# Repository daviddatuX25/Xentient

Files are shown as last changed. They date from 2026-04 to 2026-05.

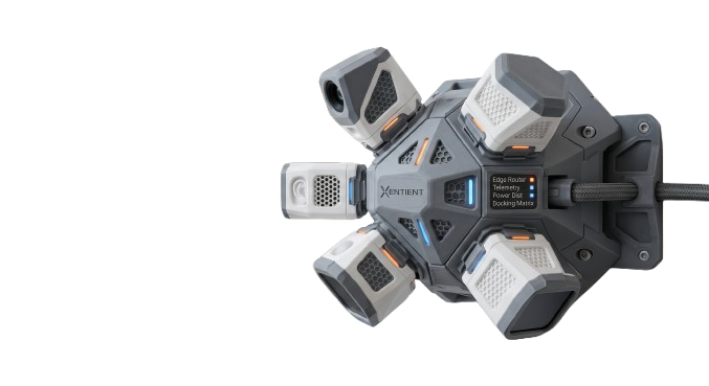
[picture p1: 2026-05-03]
Xentient-vision-product-bgremoved.png

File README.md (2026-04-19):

# Xentient

The IoT terminal that gives any AI a physical presence in any room.

Voice. Sensors. Display. Any AI brain can plug in.

---

## What It Does

Xentient is the bridge between physical rooms and AI brains. The core is a thin terminal OS — voice pipeline, MQTT bridge, LCD faces, mode management. That is what Xentient uniquely owns. Intelligence plugs in via Hermes, Mem0, OpenClaw, or a basic LLM. The same hardware can be a simple room assistant in one space and a full dev workstation in another.

---

## Demo Status

V1 prototype demo Apr 24, 2026. Voice pipeline + MQTT bridge + LCD + basic memory.

---

## Quick Start

- Full architecture and integration tiers: [docs/VISION.md](docs/VISION.md)
- Locked hardware decisions (B1-B7): [docs/HARDWARE.md](docs/HARDWARE.md)
- Explicit scope boundaries: [docs/NON_GOALS.md](docs/NON_GOALS.md)

---

## Architecture

```
Tier 3  AI Brain (remote/sandboxed)
        Hermes + Mem0 | OpenClaw | Archon
                |              |          |
Tier 2  Core (always-on hosted)            |
        Runtime daemon + Web Control Panel  |
        Brain Router → adapters ───────────┘
                |
Tier 1  Hardware
        Node Base + Mic + Speaker + LCD + Sensors
```

---

## Documentation

| Document | Purpose |
|---|---|
| [VISION.md](docs/VISION.md) | Bridge model, integration tiers, Spaces/Modes |
| [HARDWARE.md](docs/HARDWARE.md) | Locked B1-B7 decisions, BOM, enclosures |
| [NON_GOALS.md](docs/NON_GOALS.md) | What Xentient explicitly does NOT do |
| [CONTRACTS.md](docs/CONTRACTS.md) | Wire format, MQTT topics, message schemas |
| [PACKS.md](docs/PACKS.md) | Pack folder spec, manifest, handlers, lifecycle |
| [SPACES.md](docs/SPACES.md) | Space model, Mode state machine, integration tiers |

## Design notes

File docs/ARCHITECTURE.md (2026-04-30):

# Xentient Architecture

> Source of truth for *structure* — for *intent* see `CONTEXT.md`, for *contracts* see `CONTRACTS.md`, for *hardware* see `HARDWARE.md`.

---

## 1. System Overview

**Xentient is a room that thinks.** Two processes: Core (always-on) and Brain (connected sandbox). The room is the constant, the brain is the variable.

```mermaid
flowchart TB
    subgraph CORE["CORE — Always-On Orchestrator"]
        direction TB
        SE["SkillExecutor<br/>heartbeat loop"]
        MM["ModeManager<br/>sleep/listen/active/record"]
        SM["SpaceManager<br/>identity + configurations"]
        MC["MqttClient<br/>Node Base bridge"]
        AS["AudioServer<br/>PCM WebSocket"]
        CS["CameraServer<br/>JPEG WebSocket"]
        MCP["MCP Server<br/>8+ tools"]
        REST["ControlServer<br/>16+ REST endpoints"]
        SSE["SSE Bus<br/>10+ event types"]
        AW["ArtifactWriter<br/>audio + transcript"]
        PL["PackLoader<br/>skill manifests"]
    end

    subgraph NODES["NODE BASES (ESP32)"]
        NB1["Node Base 1<br/>MQTT + WS"]
        NB2["Node Base 2<br/>MQTT + WS"]
    end

    subgraph BRAIN["BRAIN — Connected Sandbox"]
        direction TB
        EI["Channel 1<br/>Escalation Inbox"]
        SO["Channel 2<br/>Stream Out"]
        TC["Channel 3<br/>Tool Calls"]
    end

    subgraph DASH["Web Dashboard"]
        UI["HTML/JS<br/>Overview/Skills/Telemetry/Mode"]
    end

    NB1 & NB2 <-->|MQTT + WS| MC & AS
    MC & AS <--> SE & MM
    SE <--> SM & MM
    MCP <-->|MCP| EI
    TC <-->|xentient_* tools| MCP
    SO -->|brain_stream| SSE
    SE -->|skill events| SSE
    MM -->|mode events| SSE
    REST <--> UI
    SSE --> UI
```

**Key idea:** Core and Brain are separate processes. Core never stops. Brain can disconnect, reconnect, or be swapped. Core is the room. Brain is the guest.

---

## 2. Three-Layer Skill Continuum

```mermaid
flowchart LR
    subgraph L0["L0 — NODE SKILLS"]
        direction TB
        NS["Behavioral contracts<br/>pushed from Core<br/>Define sampling, sensors,<br/>event frequency<br/>Enum-gated event types<br/>Paired with CoreSkills"]
    end

    subgraph L1["L1 — CORE SKILLS"]
        direction TB
        CS["Live in Core process<br/>Run on heartbeat tick<br/>Deterministic, <1ms<br/>No network calls<br/>Always run, Brain offline or not<br/>Created by: pack manifests<br/>OR Brain via MCP"]
    end

    subgraph L2["L2 — BRAIN SKILLS"]
        direction TB
        BS["Live in Brain process<br/>Run when Brain decides<br/>LLM-powered, flexible<br/>Full network, memory, reasoning<br/>Require Brain to be connected<br/>Created by: Brain process"]
    end

    NS <-->|paired activation| CS
    CS -->|escalation| BS
    BS -->|tool calls| CS
```

**Pairing Invariant:** A Node Skill and its counterpart CoreSkill(s) are always activated together. Core never pushes a Node Skill without knowing what to do with its output.

**Escalation Bridge (L1 → L2):**
Core Skill detects condition → fires L1 actions immediately → packages context → sends to Brain via MCP notification → Brain runs L2 reasoning → Brain calls back Core MCP tools → Core executes hardware actions.

---

## 3. Core Architecture (What's Built)

All paths reference actual source files in `harness/src/`.

| Component | File | Role |
|---|---|---|
| Entrypoint | `core.ts` | Starts all subsystems, wires dependencies |
| SkillExecutor | `engine/SkillExecutor.ts` | Heartbeat loop: tick → evaluate triggers → fire actions → escalate |
| SpaceManager | `engine/SpaceManager.ts` | Space identity, configurations, node assignments, ack tracking |
| ModeManager | `engine/ModeManager.ts` | State machine: sleep/listen/active/record |
| PackLoader | `engine/PackLoader.ts` | Load skill manifests from `packs/` directories |
| MqttClient | `comms/MqttClient.ts` | Bridge to ESP32 Node Bases via Mosquitto |
| AudioServer | `comms/AudioServer.ts` | PCM WebSocket in/out + camera JPEG relay |
| ControlServer | `comms/ControlServer.ts` | REST API (16+ endpoints) + static dashboard |
| MCP Server | `mcp/` | 8+ `xentient_*` tools for Brain connection |
| ArtifactWriter | (in pipeline) | Saves audio/transcript/metadata to disk |
| SSE Bus | `mcp/events.ts` | 10+ event types relayed to Dashboard |

```mermaid
flowchart LR
    CORE["core.ts"] --> SE["SkillExecutor"]
    CORE --> SM["SpaceManager"]
    CORE --> MM["ModeManager"]
    SM --> PL["PackLoader"]
    CORE --> MC["MqttClient"]
    CORE --> AS["AudioServer"]
    CORE --> REST["ControlServer"]
    CORE --> MCP["MCP Server"]
    SE <--> SM
    SE <--> MM
    REST <--> SM
    MCP <--> SM
    MCP <--> SE
```

---

## 4. Brain Interface (3 Channels)

Any MCP client can be a Brain. The interface is the contract, not the implementation.

### Channel 1: Escalation Inbox

Core pushes escalations when a CoreSkill detects a condition that requires Brain reasoning. Every escalation gets a unique `escalation_id`.

```typescript
interface EscalationPayload {
  escalation_id: string        // unique per escalation, groups Brain Feed events
  skill_id: string
  space_id: string
  mode: CoreNodeState           // dormant or running
  timestamp: number
  audio?: string               // base64 PCM
  sensor_snapshot?: SensorSnapshot
  context?: Record<string, unknown>
}
```

### Channel 2: Stream Out

Brain calls `xentient_brain_stream` to push reasoning tokens, tool calls, and status back to Core. Core relays these to the SSE bus with `source: "brain"`.

```typescript
interface BrainStreamEvent {
  escalation_id: string        // always present, ties event to its escalation
  subtype: BrainStreamSubtype
  payload: unknown
  timestamp: number
}

type BrainStreamSubtype =
  | "reasoning_token"
  | "tool_call_fired"
  | "tool_call_result"
  | "tts_queued"
  | "escalation_received"
  | "escalation_complete"
```

### Channel 3: Tool Calls Back to Core

Brain calls `xentient_*` MCP tools to act on the room: play audio, register skills, change modes, push node skills, write artifacts. See `docs/CONTRACTS.md` for full tool schemas.

### Reference Implementations

- **brain-basic.ts** — Minimal Brain (Channel 1 + 3 only, no streaming)
- **brain/hermes/HermesAdapter.ts** — Full Brain (all three channels)

### Building a Custom Brain

The minimum viable Brain is a script that: (a) connects to Core's MCP server, (b) subscribes to escalation notifications, (c) calls Core MCP tools to respond. Streaming is optional. Memory is optional. Tool use is optional.

---

## 5. Node Skills

Node Skills are behavioral contracts pushed from Core to Node Bases via MQTT. They configure sampling behavior, active sensors, event emission frequency, and local state machines. See `docs/NODE-SKILLS.md` for the full spec.

**Key properties:**
- Always paired with a CoreSkill (pairing invariant)
- Enum-gated event types (no arbitrary MQTT floods)
- Hardware capability declarations checked before push
- Core won't push a camera skill to a node with no camera

---

## 5a. NodeProfile Compilation Pipeline

When a configuration is activated, Core compiles each node's assigned NodeSkill into a firmware-ready `NodeProfile` via `toNodeProfile()` in `engine/nodeProfileCompiler.ts`. This is a two-layer contract model:

```
NodeSkill (Core-level)  →  toNodeProfile()  →  NodeProfile (firmware-level)
```

**NodeSkill** lives in the pack manifest. It declares `requires` (hardware), `sampling`, `emits` (event types), and `compatibleConfigs`.

**NodeProfile** is the compiled binary payload pushed to the ESP32 over MQTT. It contains the `eventMask` (bitmask), `micMode` (0=off, 1=vad-only, 2=always-on), sensor intervals, and LCD strings — everything the firmware Mode Task needs.

The compilation step (`toNodeProfile()`) checks hardware compatibility, maps event type strings to bitmask bits, and validates `micMode`. If a node lacks required hardware, the compiler returns `null` and Core falls back to the default profile.

---

## 5b. Configuration Transitions & Ack Timeout

Configuration changes are not immediate — they go through a `TransitionQueue` in SpaceManager. This ensures:

1. **Ordered transitions:** If Brain rapidly switches config A → B → C, they execute in order, not as a race.
2. **Ack tracking:** When Core pushes a `NodeProfile` to a node, it starts a 5-second ack timer. If the node doesn't respond with `node_profile_ack` within 5 seconds, Core marks the node `dormant` and emits a `xentient/node_offline` notification.
3. **Reconnect replay:** On MQTT reconnect (`onMqttReconnect()`), Core re-enqueues the active configuration for all spaces. This ensures firmware stuck on `DEFAULT_PROFILE` after a broker restart catches up.

```
activateConfig("classroom")
  → TransitionQueue.enqueue({type: 'activate_config', configName: 'classroom'})
  → drain() → executeConfigTransition()
    → for each node: toNodeProfile(nodeSkill, node) → MQTT publish
    → pendingAcks.set(nodeId, { timeout: 5s })
    → on ack: clearTimeout, mark node 'running'
    → on timeout: mark node 'dormant', notify Brain via xentient/node_offline
```

---

## 6. Data Flows

### Audio Flow

```mermaid
sequenceDiagram
    participant MIC as ESP32 Mic
    participant WS as AudioServer
    participant SE as SkillExecutor
    participant BR as Brain
    participant TTS as TTS Provider
    participant SPK as ESP32 Speaker

    MIC->>WS: PCM frames (16k mono)
    WS->>SE: audio chunks
    SE->>SE: noise-gate → voice-classifier → keyword-spotter
    SE->>BR: escalate (audio payload)
    BR->>BR: STT → LLM → TTS
    BR->>SE: xentient_play_audio (PCM)
    SE->>WS: TTS PCM out
    WS->>SPK: PCM playback
```

### Sensor Flow

```mermaid
flowchart LR
    BME["BME280"] -->|MQTT env| MC["MqttClient"]
    PIR["PIR"] -->|MQTT motion| MC
    MC --> SE["SkillExecutor"]
    SE -->|trigger evaluation| SM["SpaceManager"]
    SE -->|event| SSE["SSE Bus"]
```

### Skill Escalation Flow

```mermaid
flowchart LR
    SE["CoreSkill<br/>detects condition"] -->|fires L1 actions| ACT["L1 Actions<br/>(mode change, audio)"]
    SE -->|packages context| PAY["EscalationPayload<br/>(escalation_id, audio, sensors)"]
    PAY -->|MCP notification| BR["Brain"]
    BR -->|L2 reasoning| LLM["STT/LLM/TTS"]
    BR -->|tool calls| CORE["xentient_* MCP tools"]
    CORE -->|execute| HW["Hardware"]
```

### Node Skill Push Flow

```mermaid
sequenceDiagram
    participant CORE as Core
    participant MQTT as Mosquitto
    participant NODE as Node Base

    CORE->>CORE: config change → compile NodeProfile via toNodeProfile()
    CORE->>CORE: check hardware declaration vs node capabilities
    CORE->>MQTT: publish xentient/node/{nodeId}/profile/set
    MQTT->>NODE: receive Node Skill config
    NODE->>NODE: load into Mode Task
    NODE->>MQTT: publish xentient/node/{nodeId}/skill/ack
    MQTT->>CORE: skill acknowledged
    NODE->>MQTT: emit events per Node Skill config
    MQTT->>CORE: receive events → paired CoreSkill interprets
```

### Brain Feed Flow

```mermaid
flowchart LR
    BR["Brain"] -->|xentient_brain_stream| CORE["Core"]
    CORE -->|"source: brain"| SSE["SSE Bus"]
    SSE --> UI["Dashboard"]
```

---

## 7. Known Architecture Debt

| Item | Status | Notes |
|---|---|---|
| **Pipeline.ts in Core** | Active and working | Do NOT delete until `brain/VoiceResponder.ts` is proven in its place. The refactor is a **migration, not a deletion** — run both in parallel until Brain Channel 1 and 3 are confirmed working end-to-end. Cutover point: when brain-basic can receive an escalation, call STT/LLM/TTS, and call `xentient_play_audio` successfully. Then Pipeline.ts gets removed. |
| **PIR wake bug (9id)** | Open | Firmware ISR works, harness gap in ModeManager sleep→listen transition |
| **Camera not forwarded to Brain** | Not built | CameraServer streams to dashboard but doesn't relay frames to Brain via MCP |

---

## 8. Process & Port Map

| Process | Tech | Port(s) | Lives where |
|---|---|---|---|
| Mosquitto | broker | 1883 (MQTT), 9001 (WS) | LAN |
| Core Runtime | Node.js | REST 3000, audio WS 8081, MCP stdio | Operator PC / VPS |
| Web Dashboard | Static HTML/JS | Served by ControlServer on :3000 | Served by Core |
| brain-basic | Node.js | connects to Core MCP | Same host or remote |

---

## 9. What Lives Where (Codebase)

```
xentient/                         ← this repo
├── harness/                      ← Core Runtime (Node.js)
│   ├── src/
│   │   ├── core.ts               ← always-on orchestrator entrypoint
│   │   ├── engine/
│   │   │   ├── SkillExecutor.ts   ← heartbeat loop executing CoreSkills
│   │   │   ├── ModeManager.ts     ← sleep/listen/active/record
│   │   │   ├── SpaceManager.ts    ← identity + configurations + ack tracking
│   │   │   ├── TransitionQueue.ts ← ordered config transition queue
│   │   │   ├── nodeProfileCompiler.ts ← NodeSkill → NodeProfile compilation
│   │   │   ├── PackLoader.ts      ← load skill manifests from packs/
│   │   ├── mcp/
│   │   │   ├── server.ts          ← MCP server (Brain connects here)
│   │   │   ├── tools.ts           ← xentient_* MCP tools
│   │   │   └── events.ts          ← SSE event bus
│   │   ├── comms/
│   │   │   ├── MqttClient.ts      ← Node Base bridge
│   │   │   ├── AudioServer.ts     ← PCM + JPEG WebSocket
│   │   │   └── ControlServer.ts   ← REST API + static dashboard
│   │   └── shared/
│   │       ├── contracts.ts       ← Zod schemas
│   │       └── contracts-schemas.ts
│   ├── public/                    ← Web Dashboard (static HTML/JS/CSS)
│   ├── packs/                     ← Pack manifests + skills
│   └── tests/                     ← Vitest suites
├── brain/                          ← Brain (SEPARATE PROCESS)
│   ├── index.ts                   ← Brain entrypoint
│   ├── hermes/
│   │   └── HermesAdapter.ts       ← Hermes Agent wrapper
│   ├── pipeline/
│   │   └── VoiceResponder.ts      ← STT → LLM → TTS
│   └── adapters/
│       ├── Mem0Adapter.ts
│       └── OpenClawAdapter.ts
├── firmware/                       ← ESP32 Node Base (C++)
│   ├── src/
│   │   ├── main.cpp               ← FreeRTOS two-task model
│   │   ├── mqtt_client.cpp
│   │   ├── lcd_driver.cpp
│   │   ├── i2s_mic.cpp
│   │   ├── vad.cpp
│   │   ├── ws_audio.cpp
│   │   ├── cam_relay.cpp
│   │   └── bme_reader.cpp
│   ├── include/
│   └── shared/
│       └── messages.h              ← mirrors contracts.ts
└── docs/                           ← this directory
```

---

## 10. Decision Boundaries (What We Will Not Cross)

| Line | Why |
|---|-----|
| Core never embeds an AI brain | Brains are external processes — keeps Core thin and swappable |
| Brain never talks to hardware directly | All hardware goes through Core MCP tools |
| Core continues if Brain disconnects | The room never bricks. L1 skills keep running. |
| Handlers are enum-gated, not dynamic | No `eval`, no plugin loading, no arbitrary code paths. New handler = harness PR. |
| One pack active per space | No multi-pack composition in v1 |
| Node Skills are pushed by Core, not self-selected | Configuration authority lives in Core, not in hardware |
| Brain streams via Core, not directly to Dashboard | Core owns the observability bus. Brain is a producer, not a publisher. |

---

## 11. Reading Order

1. **`CONTEXT.md`** — *why* (the vision, the skill continuum, what needs to change)
2. **`ARCHITECTURE.md`** — *what shape* (this document)
3. **`BRAIN-INTERFACE.md`** — *how Brain connects* (3-channel spec)
4. **`NODE-SKILLS.md`** — *how Node Skills work* (L0 behavioral contracts)
5. **`SKILLS.md`** — *what a skill is* (unified reference across all layers)
6. **`CONTRACTS.md`** — *how they talk* (MQTT, REST, SSE, MCP, Node Skill, Brain Stream)
7. **`HARDWARE.md`** — *what's wired* (BOM, pinouts, wiring decisions)
8. **`PACKS.md`** / **`SPACES.md`** — *the configuration model*

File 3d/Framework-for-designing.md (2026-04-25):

# Xentient Framework: SketchUp Design Guide V3

**Architecture:** Distributed Hub-and-Spoke Edge AI (Truncated Hex-Pyramid Base)
**Modeling Tool:** SketchUp (Free/Pro — web or desktop)
**Core Pivot:** 16x2 LCD is an independent, pluggable peripheral cap.
**Print Material:** PETG mandatory for Main Node, Speak Cap, and Sight Cap. PLA acceptable for low-heat peripherals.

---

## 1. SketchUp Setup & Modeling Conventions

### Tool Setup
- Use **SketchUp Make 2017** (free desktop) or **SketchUp Free** (web) — both work for this project
- Install **Solid Inspector²** extension to verify manifold geometry before export
- Install **Export STL** or **STL Exporter** extension for 3D printing output
- Set **model units to millimeters** (Window → Model Info → Units → Millimeters, precision 0.0mm)

### Modeling Rules
- **Everything must be a Solid Group or Component** — no loose geometry
- Name every group/component descriptively (e.g., `NodeBase-Shell`, `Sled-Male`, `Sleeve-30deg`)
- Use **Layers/Tags** to organize: `Shell`, `Ports`, `Interior`, `Caps`, `Anchors`
- Model at **1:1 real scale** (mm) — never scale up/down for printing
- **No zero-thickness faces** — every wall must have real volume (min 1.5mm, structural walls 3.0mm)
- Export each printable part as a **separate STL** — one file per print job
- Run **Solid Inspector²** before export — fix all leaks and internal faces

### SketchUp → STL Workflow
1. Model component as a solid group
2. Right-click → **Export STL** (select binary format, units: mm)
3. Open STL in slicer (Cura/PrusaSlicer)
4. Verify dimensions match spec before printing

---

## 2. Global 3D Printing & Manufacturing Guidelines

**Material:** PETG is mandatory for the Main Node, Speak Cap (amp heat), and Sight Cap (ESP32-CAM heat). PLA will warp near heat sources.

**Structural Wall Thickness:** Minimum 3.0mm for the main hub shell and anchor planes. Peripherals: 1.5mm–2.0mm walls.

**Tolerances:**
- Friction Fits (Sleds/Plugs): Male parts designed exactly **0.4mm smaller** (0.2mm offset per side) than female receivers
- Screw Holes: Add 0.2mm to screw body diameter (e.g., M3 body = 3.2mm hole)

**Fasteners:** Brass Heat-Set Inserts (M2 for PCBs, M3 for structural anchors) — do not tap plastic.

**Overhangs/Bridging:** Design internal cavities with **45° chamfers** to eliminate internal supports (hard to remove from enclosed Hub).

---

## 3. The Universal Mating Protocol (Sled & Socket)

The standardized mechanical interface connecting every Cap to the Hub.

### The Female Socket (Carved into the Hub)

| Parameter | Value |
|---|---|
| Width | 24.0mm |
| Height | 16.0mm |
| Depth | 10.0mm (recessed sleeve behind wall) |
| Wire Channel | 18.0mm W × 8.0mm H (passes 6-pin JST XH2.54) |

**SketchUp How-To:** Use the **Push/Pull** tool to carve the pocket from the hub face. Start with a 24×16mm rectangle, push 10mm deep. Carve the wire channel as a separate 18×8mm rectangle pushed through the sleeve interior.

### The Male Sled (Base of Every Peripheral Cap)

| Parameter | Value |
|---|---|
| Width | 23.6mm |
| Height | 15.6mm |
| Depth | 10.0mm |
| Draft Angle | 1° (outer walls taper inward for wedge fit) |
| Hollow Core | 18.0mm × 8.0mm (pigtail wiring pass-through) |

**SketchUp How-To:** Draw the sled profile as a 23.6×15.6mm rectangle. Extrude 10mm. Apply 1° taper using the **Move** tool on top edges (offset ~0.17mm per side). Subtract the 18×8mm wire channel with Push/Pull. Group as `Sled-Male` component.

---

## 4. Main Node Module (The Hex-Core Base)

The Conduit Entity — powers the system and routes telemetry. Does not process AI.

### Geometry: Truncated Hexagonal Pyramid

| Dimension | Value |
|---|---|
| Base Width (Rear/Wall-side) | 150mm flat-to-flat (radius ~86.6mm) |
| Front Width | 60mm flat-to-flat (radius ~34.6mm) |
| Total Depth | 90mm |
| Collar Height | 12mm (straight section at base, full radius) |

### SketchUp Construction Steps

1. **Draw the base hexagon:** Use the **Polygon** tool (6 sides), radius 86.6mm. Center at origin.
2. **Draw the front hexagon:** Polygon tool, radius 34.6mm. Place at 90mm above base (Z=90).
3. **Connect the pyramids:** Select both hexagons, use **Loft** (if available via extension) or manually connect each vertex pair with the **Line** tool to form the 6 trapezoidal faces.
4. **Add collar:** Extrude the base hexagon downward 12mm (or model as a separate 12mm straight section below the pyramid taper).
5. **Make solid:** Select all faces, right-click → **Make Group** → check with Solid Inspector².
6. **Shell the solid:** Use **Erase** to remove the top face, then use **Push/Pull** on the inner faces to hollow the shell to 3mm wall thickness. Alternatively, model the inner cavity as a slightly smaller pyramid and subtract with **Solid Tools → Subtract**.

### Port Matrix

| Port | Position | Assignment |
|---|---|---|
| Center Front | Dedicated wide socket | Display Cap (LCD 16×2) |
| 30° face | Angled perimeter | Sight (ESP32-CAM) — high visibility, clear LOS |
| 90° face | Angled perimeter | Speak (MAX98357A) — near USB-C, ventilation |
| 150° face | Angled perimeter | Climate (BME280) — away from heat |
| 210° face | Angled perimeter | Motion (HC-SR501 PIR) — human detection height |
| 270° face | Angled perimeter | Listen (INMP441) — opposite speaker, no feedback |
| 330° face | Angled perimeter | Reserved (future peripheral) |
| Rear | Anchor pocket | 40mm diameter, 6mm deep, anti-rotation cross-keys |

### Key Shell Features

- **Ventilation:** 4 slits per face (2mm wide, 45° chamfered) on 3 alternating collar faces (0°, 120°, 240°)
- **USB-C Cutout:** 12×6mm on collar face, 1mm floor overcut for thick cable plug housings
- **Rear Anchor Pocket:** 40mm diameter, 6mm deep, with anti-rotation cross-key channels
- **Collar Aesthetic Ribs:** 6× ridges at 0°, 60°, 120°, 180°, 240°, 300° (collar zone only)
- **Breakout PCB Flange:** 2mm flange around each pocket sleeve interior with M2 mounting holes

---

## 5. Peripheral Cap Specifications

Each Cap is a standalone model/print that starts with the Universal Male Sled and extends into its specific housing. See `tutorials/caps/` for step-by-step SketchUp guides.

### Housing 1: Listen (Microphone)
- **Component:** INMP441 MEMS mic (8×8mm) + 100nF cap
- **Connection:** 6-pin JST pigtail (I2S)
- **Form:** Low-profile dome, ~10mm extension from sled
- **Features:** 3×3 pinhole array (1mm holes) on front face, internal PCB slot
- **Tutorial:** `tutorials/caps/listen.md`

### Housing 2: Speak (Amplifier + Speaker)
- **Component:** MAX98357A (7×7mm) + 3W 8Ω Speaker (40mm)
- **Connection:** 6-pin JST pigtail (I2S)
- **Form:** Heavy trapezoidal box with asymmetric flare (40mm speaker > 24mm sled)
- **Features:** Structural grille, thermal divider (amp ↔ speaker), top/bottom vents
- **Tutorial:** `tutorials/caps/speak.md`

### Housing 3: Climate (Environmental)
- **Component:** BME280 (13×10mm) + 100nF cap
- **Connection:** 6-pin JST pigtail (4 active: VCC, GND, SDA, SCL)
- **Form:** Standoff vented box, minimum 15mm from hub face
- **Features:** 4-sided louvered gills for passive airflow
- **Tutorial:** `tutorials/caps/climate.md`

### Housing 4: Motion (Presence)
- **Component:** HC-SR501 PIR (23×23mm board, 15mm dome)
- **Connection:** 4-pin JST pigtail (VCC, GND, OUT, NC)
- **Form:** Recessed shroud
- **Features:** 15.5mm Fresnel lens cutout, 2× 3mm adjustment holes for potentiometers
- **Tutorial:** `tutorials/caps/motion.md`

### Housing 5: Sight (Camera)
- **Component:** ESP32-CAM-MB dual-board (40×27mm)
- **Connection:** 4-pin JST pigtail (UART: VCC, GND, TX, RX)
- **Form:** Articulated ball-joint head (two-part print)
- **Features:** 15.5mm lens cutout, thin wall (<1.5mm) near WiFi antenna
- **Tutorial:** `tutorials/caps/sight.md`

### Housing 6: Display (The Monitor)
- **Component:** LCD 16×2 + PCF8574 backpack (71×26×15mm)
- **Connection:** 4-pin JST pigtail (I2C: VCC, GND, SDA, SCL)
- **Form:** Flared monitor (24mm sled → 75×30mm bezel)
- **Features:** 71×27mm window, M3 standoffs for backpack, snap-fit backplate
- **Socket:** Center Front ONLY
- **Tutorial:** `tutorials/caps/display.md`

---

## 6. Anchor Ecosystem

Adapters that plug into the Rear Universal Anchor (40mm circular recess). See `tutorials/anchors/` for SketchUp guides.

### Wall Plate Adapter
- 40×6mm male cylinder with cross-keys → 60×60mm flat plate
- 4× M3 countersunk holes + central 15mm cable hole
- **Tutorial:** `tutorials/anchors/wall-plate.md`

### Desk Pedestal Adapter
- Weighted wedge, 15° upward tilt for desk viewing
- Hollow cable routing channel + weight fill pocket
- **Tutorial:** `tutorials/anchors/desk-pedestal.md`

---

## 7. Internal Spatial Layout Protocol

All component placement must respect the truncated hex-pyramid geometry. The cavity tapers from 150mm F2F (rear) to 60mm F2F (front) over 90mm depth.

### Cavity Taper Formula

At any Z-height: `F2F(Z) = Base_F2F - (Base_F2F - Front_F2F) × (Z - Collar_H) / Pyr_H`

For Z < Collar_H (collar zone): `F2F = Base_F2F = 150mm`

### Hex Boundary Constraint

A rectangular component of width W and height H fits inside a hex with circumradius R only if: `H/2 ≤ −√3·(W/2) + √3·R`. Components wider than the inscribed rectangle must have corners chamfered.

### Z-Stack Layout (90mm depth)

| Zone | Z Range | Contents |
|---|---|---|
| A | 3–15mm | Battery holder (18650) + TP4056 + MT3608 + 3.3V LDO |
| Gap | 15–20mm | Wire routing |
| B | 20–37mm | 120×80mm master solder board on M3 standoffs |
| Gap | 37–45mm | Wire routing |
| C | 45–65mm | ESP32-WROOM-32 (55×28mm) on M2 standoffs, Y=+18mm offset |
| Gap | 65–75mm | Wire routing to LCD |
| Front | 75–87mm | LCD 16×2 display (as Display Cap) |

### Floor Plan
- Power modules (TP4056, MT3608) cluster near USB-C wall (Y=+30mm)
- Battery holder centered at Y=−25mm
- Master board centered on X-axis
- ESP32 offset Y=+18mm for USB-C access

### Minimum Clearance
No component or standoff may have less than 3mm clearance from the cavity wall. Below 2mm → increase Total_Depth or relocate to a wider zone.

---

## 8. Modular Assembly Protocol

### Two Valid Assembly Paths

**Path A (Printed Plates):** Print Zone A/B/C plates as modular sleds that slide into internal rail slots and screw onto bosses. Best for reproducible builds and serviceability. See `tutorials/nodebase/interior-plates.md`.

**Path B (Glue-In Standoffs):** Skip printing plates. Use flat landing pads on the hub interior as glue surfaces. Scuff with sandpaper, apply cyanoacrylate, seat standoff. Faster for one-off prototypes. See `tutorials/nodebase/interior-plates.md`.

Both paths are valid. Plates are RECOMMENDED but NOT MANDATORY.

### Interior Components (separate prints that glue in)

| Component | Count | Glue Position | Z Range | Purpose |
|---|---|---|---|---|
| Rail Guides | 6 | Hex vertices (0°,60°,...300°) | 3–12mm | Channel for plate edges |
| Keyway Strips | 3 | 0°, 120°, 240° | 3–87mm | Angular orientation |
| Landing Pads | 4 | (±57, ±37) | Z=20 | Glue targets for M3 standoffs |
| Reference Markers | 10 | Zone A/B/C coords | Various | Drill/glue pilot guides |
| Zone A Tray | 1 | Floor, slides into rails | 3–15mm | Battery + power cradle |
| Zone B Plate | 1 | Z=20, rails or standoffs | 20–37mm | Master board mount |
| Zone C Plate | 1 | Z=45, rails or standoffs | 45–65mm | ESP32 mount |

### Mandatory Plate Design Rules
All printed interior plates MUST include:
1. **Wire Chimney:** Central 30×30mm cutout per plate
2. **Socket Clearance Notches:** Subtract port sleeve volumes from plates
3. **Hex-Grid Infill:** Honeycomb pattern for non-structural areas (airflow)

### Adhesive Notes
- PETG is chemically resistant → scuff landing pads with 120-grit sandpaper for mechanical bond
- Cyanoacrylate (super glue): good bond after scuffing
- Hot glue: removable, but softens above 80°C — avoid near MT3608
- PETG cement (Weld-On 3): permanent bond option

### Fastener Standards
- M3 heat-set insert: 4.2mm hole, 5mm boss diameter
- M2 heat-set insert: 2.4mm hole, 4mm boss diameter
- Screw lengths: M3×6 (tray), M3×8 (plate), M2×4 (PCB), M2×6 (plate)

---

## 9. Print Settings Reference

| Setting | Value |
|---|---|
| Material | PETG (mandatory for NodeBase, Speak, Sight) |
| Layer Height | 0.2mm |
| Wall Count | 3+ perimeters (3mm shell) |
| Infill | 20% gyroid |
| Build Plate | Brim recommended (large flat base) |
| Orientation | Base flat on bed, rear face down |
| Supports | None required (all overhangs ≤ 45° by design) |

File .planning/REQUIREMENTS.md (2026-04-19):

# Requirements: Xentient

**Defined:** 2026-04-13
**Core Value:** Modular, zero-friction spatial intelligence through a visual control plane and high-speed AI orchestration.

## v1 Requirements

Requirements for the April 24 Prototype.

### Node Hardware & Firmware
- [ ] **NODE-01**: ESP32 core detects peripherals via I2C/EEPROM ID.
- [ ] **NODE-02**: RMS-based VAD (Voice Activity Detection) notifies Harness of speech start/end.
- [ ] **NODE-03**: Camera frames forwarded from ESP32-CAM via UART1/2 to Node Base at >5fps.
- [ ] **NODE-04**: Bi-directional MQTT communication for sensor telemetry and control commands.
- [ ] **NODE-05**: Reliable GPIO mapping for all 4 slots (Listen, Speak, Sense, Sight).

### Harness Intelligence Engine
- [ ] **HARN-01**: n8n-style modular processing pipeline (Trigger -> STT -> Logic -> TTS -> Output).
- [ ] **HARN-02**: Mosquitto-based central message brokerage with separate channels for audio/frames/sensors.
- [ ] **HARN-03**: Integration of Cloud LLM APIs (GPT-4o / Gemini 1.5 Pro) for high-speed reasoning.
- [ ] **HARN-04**: Real-time audio ingestion and TTS generation with low latency (<2s round-trip).

### Memory (Hermes-Agent)
- [ ] **MEM-01**: Persistent user profile and context stored in SQLite/FTS5.
- [ ] **MEM-02**: Proactive memory retrieval (LLM reviews history to inject context into current prompt).
- [ ] **MEM-03**: Cross-session identification and greeting based on persistent user model.

### Web Control Plane
- [ ] **WEB-01**: Dashboard showing live heartbeat status of Node Base and Peripherals.
- [ ] **WEB-02**: Visual flow editor to configure "Modes" (Query Mode vs. Workflow Mode).
- [ ] **WEB-03**: Activity log viewer showing processed triggers and AI responses.

## v2 Requirements (Deferred)
- **MESH-01**: Multi-node coordination and spatial presence detection.
- **LOCAL-01**: Fully local LLM/Voice stack (Ollama/Whisper/Piper) on edge server.
- **OTA-01**: Over-the-air firmware updates for Node Base base.

### Documentation Architecture
- [x] **DOC-01**: VISION.md exists as canonical L1 vision with bridge model, integration tiers, Spaces/Modes primitives.
- [x] **DOC-02**: NON_GOALS.md explicitly lists what Xentient is NOT, including no Archon in v1 demo.
- [x] **DOC-03**: HARDWARE.md preserves B1-B7 decisions verbatim from NOTES.md.
- [ ] **DOC-04**: CONTRACTS.md, PACKS.md, SPACES.md exist as L2 spec documents.
- [ ] **DOC-05**: INTEGRATIONS/hermes.md, mem0.md, openclaw.md exist as L2 integration specs.
- [x] **DOC-06**: README.md rewritten as 60-second pitch aligned with bridge model.
- [x] **DOC-07**: Archon contradiction resolved (included as P9 in Platform Track, deferred in demo scope).

## Out of Scope
| Feature | Reason |
|---|---|
| On-node Audio DSP | ESP32 limited processing; STT offloaded to Harness for V1 stability. |
| Custom Case Design | Focus on functional assembly first; parametric enclosure for V1. |

## Traceability

| Requirement | Phase | Status |
|---|---|---|
| NODE-01 | Phase 1 | Pending |
| NODE-02 | Phase 1 | Pending |
| NODE-04 | Phase 1 | Pending |
| HARN-01 | Phase 2 | Pending |
| HARN-02 | Phase 2 | Pending |
| MEM-01 | Phase 2 | Pending |
| WEB-01 | Phase 3 | Pending |
| DOC-01 | Phase 5 | Complete |
| DOC-02 | Phase 5 | Complete |
| DOC-03 | Phase 5 | Complete |
| DOC-04 | Phase 5 | Pending |
| DOC-05 | Phase 5 | Pending |
| DOC-06 | Phase 5 | Complete |
| DOC-07 | Phase 5 | Complete |

**Coverage:**
- v1 requirements: 22 total
- Mapped to phases: 14
- Unmapped: 8 (Remaining hardware assembly and presentation)

---
*Requirements defined: 2026-04-13*
*Last updated: 2026-04-19 — DOC requirements added, DOC-01/02/03/06/07 marked complete*

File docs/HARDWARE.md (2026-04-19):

# Xentient Hardware Decisions

> Locked hardware and firmware decisions. Source of truth for B1-B7. These decisions are NOT negotiable — they are the hardware foundation that software builds upon.

---

## Decision Lock Table

### B1: Harness Retry Bug — DECIDED

- **Trigger:** Auto-retry, max 3 attempts, exponential backoff (1s/2s/4s) on transient errors only
- **Fatal errors (no retry):** 401/403 auth, 429 quota exhausted, 400 bad request → surface to UI immediately
- **Transient (retry):** network timeout, 5xx, WS disconnect, stream abort
- **UI fallback:** After max retries OR fatal error → WS sends `{type:"session_error", recoverable:bool}` → UI shows "Retry" (recoverable) or "Reset Conversation" (fatal) button
- **State machine:** `IDLE → LISTENING → THINKING → SPEAKING → ERROR → IDLE`. ERROR state calls `resetSession()` which: (a) closes all 3 streams (STT/LLM/TTS), (b) releases MQTT busy flag, (c) clears token buffers, (d) emits `session_reset` event
- **Library:** `p-retry` (2KB, battle-tested) — NOT XState (too heavy for 6-day window). Inline enum + switch for state machine.
- **New deps:** only `p-retry`. Everything else uses existing `ws`/`pino`.

### B2: Shared Data Contract — DECIDED

- **Source of truth:** `harness/src/shared/contracts.ts` (Zod schemas) + hand-mirror to `firmware/shared/messages.h` (C++ structs)
- **Wire format:** JSON over MQTT (human-debuggable), binary PCM over WS (audio only)
- **Key naming:** camelCase everywhere (ArduinoJson handles both sides)
- **Timestamps:** `epoch-millis uint32` (half the bytes of ISO8601, demo-safe)
- **Enum widths:** pinned to `uint8_t` opcodes (0-255); TS mirrors with `z.number().int().min(0).max(255)`
- **Version field:** YES — every packet has `v: 1` at root. Harness rejects mismatched versions with `{error:"version_mismatch"}`
- **Payload cap:** 3KB hard limit on any MQTT packet (ESP32 default 4KB minus headroom)
- **Peripheral ID registry:** enum lives in `contracts.ts` and mirrors EEPROM identity byte (B4). Single integer table, no drift.
- **Library:** `zod` + `zod-to-json-schema` for runtime validation on TS side. No codegen — hand-sync the .h file.

### B3: Node Base Firmware — DECIDED

- **Sample rate:** **16kHz mono PCM S16LE** (32KB/s, fine on 2.4GHz LAN, matches Deepgram input)
- **Compression:** **Raw PCM, NO Opus on-device.** Opus encoder eats ESP32 cycles + adds latency. LAN bandwidth is free.
- **Audio buffering:** DMA ring buffer from I2S ISR (8 x 1024-sample blocks) → FreeRTOS queue → WS task. Backpressure = drop oldest block + log (never block ISR).
- **TTS playback:** Stream-in PCM, play as it arrives. Buffer 100ms ahead before starting playback.
- **Task priorities:** Audio (highest) > WS I/O > MQTT telemetry > PIR/BME280 polling. Pin audio to Core 1, networking to Core 0.
- **Reconnect rule:** New WS session = flush audio buffer + increment `sessionId`. Harness drops stale-sessionId frames.
- **Libraries:** `ArduinoWebsockets` (Links2004), `PubSubClient`, `ArduinoJson v7`, native `driver/i2s.h` for INMP441. Skip ESP-ADF / esp32-audioI2S.

### B4: EEPROM Enumeration — DROPPED (2026-04-18 revision)

- **Reason:** Slots are fixed-role (no any-module-anywhere). Each peripheral type is compile-time bound to a known GPIO/I2C address. Dynamic enumeration = solving a problem we deliberately designed out.
- **Replacement:** Compile-time peripheral map in `firmware/config/peripherals.h` — const table of {slotId, type, pins, i2cAddr}. Firmware iterates on boot, logs what's present via I2C ping.
- **Demo behavior:** If expected peripheral doesn't ACK on I2C → log "Slot X offline" + continue. No crash, no hot-swap detection.
- **Wins:** ~200 LOC dropped, no AT24C02 needed in BOM, no I2C enumeration bus traffic, zero scan-time I2C contention with BME280.
- **Type registry (still used for contracts + logs):** 0x10=Speaker, 0x11=PIR, 0x12=BME280, 0x13=INMP441, 0x14=ESP32-CAM, 0x15=LCD
- **Library:** Native `Wire.h` only for I2C presence ping (<20 LOC).

### B5: JST Connectors — DECIDED (revised 2026-04-18)

- **User's existing spec:** 4-pin and 6-pin JST 1.0mm (already on hand / committed). No single-pinout unification.
- **4-pin (I2C peripherals):** VCC + GND + SDA + SCL
  - **Uses:** BME280, PIR (PIR needs only 3 — VCC/GND/OUT; 4th pin unused/floats, PIR OUT wired to SDA-slot GPIO via firmware remap)
- **6-pin (I2S peripherals):** VCC + GND + BCLK(SCK) + LRCK(WS) + DATA(SD) + L/R-select (or GND for mono)
  - **Uses:** INMP441 mic, MAX98357 I2S speaker amp
- **Pigtail wiring:** Pre-crimped 1.0mm pigtails, solder to PCB-side headers. Heatshrink color code per connector type:
  - 4-pin: R=VCC, B=GND, W=SDA, Y=SCL
  - 6-pin: R=VCC, B=GND, W=BCLK, Y=LRCK, G=DATA, Blk=L/R
- **Strain relief:** hot-glue at solder joint. Demo-grade.

### B6: Enclosures — DECIDED (revised 2026-04-18)

- **Mounting style:** **Slot-in slide (wall-hang type).** Peripheral has a male dovetail/T-slot rail on its back; Node Base dock has matching female slot. Slide down to seat, JST plug mates automatically at bottom of travel.
- **Compact:** Minimum footprint per peripheral. No EEPROM pocket (B4 dropped). Just PCB + I2S/I2C chip + JST pigtail exit.
- **Material:** **PETG** everywhere (PLA softens at 60C, PETG handles 80C — matters for speaker amp thermals)
- **Fit:** Slide rails use press-fit (no screws on peripherals). Node Base dock uses M2 heat inserts for wall-mount screws only.
- **Overhangs:** 45deg max on slide rails to print support-free.
- **Dock order:** Design peripherals FIRST (with rails) → measure rail dimensions → design dock SECOND (with matching slots + JST header positions).

### B7: LCD Display (NEW 2026-04-18) — DECIDED

- **Placement:** **Core to Node Base dock** (always-on, hardwired to main I2C bus). NOT a slide-in peripheral. LCD = Xentient's face; always present.
- **Spec:** I2C 16x2 with PCF8574 backpack at 0x27 (Shopee.ph standard, ~150 PHP). Coexists with BME280 at 0x76/0x77 — no I2C collision.
- **Dual-mode use:**
  1. **Expressive (primary — "face of Xentient"):** pipeline-state-driven faces.
     - IDLE: `(^_^) Xentient` / `  ready...`
     - LISTENING: `(O_O) listening` / `> [transcript]`
     - THINKING: `(@_@) thinking...` / animated dots
     - SPEAKING: `(>_<) talking` / `> [reply snippet]`
     - ERROR: `(x_x) oops!` / `retrying N/3`
  2. **Functional (secondary):** boot/Wi-Fi status, sensor readouts on idle, error codes.
- **Driver task:** low-priority FreeRTOS task. Subscribes to MQTT topic `xentient/display` + listens to pipeline state events from harness.
- **Library:** `LiquidCrystal_I2C` by marcoschwartz (de facto, well-documented).
- **Contract addition:** new message type `display_update` in `contracts.ts`:
  ```
  { v:1, type:"display_update", mode:"expression"|"text"|"status", line1:string, line2:string, duration?:ms }
  ```
  Harness publishes on state transitions; firmware renders with 2s min-hold (prevents flicker).
- **Enclosure impact:** Node Base dock front face gets 71x27mm rectangular cutout for LCD window + 4 mounting posts (M3 standoffs common on these modules). Bezel 3mm thick.
- **Demo win:** Visual state feedback during demo = judges see what Xentient is "thinking" even before audio response — HUGE narrative boost.

---

## Bill of Materials

| Component | Part | Role |
|---|---|---|
| MCU | ESP32-WROOM-32 | Peripheral enumeration, data routing, WiFi upstream, OTA |
| Ethernet | W5500 (SPI) | Onboard wired upstream for fixed installations |
| Microphone | INMP441 | MEMS I2S mic — voice input |
| Speaker Amp | MAX98357A | I2S Class D amp — voice output |
| Camera | OV2640 | Image sensor — vision input |
| Motion Sensor | HC-SR501 | PIR motion detection |
| Environmental | BME280 | Temperature, humidity, pressure sensing |
| LCD Display | I2C 16x2 (PCF8574) | Xentient face — always-on status display |
| Charge Controller | TP4056 | LiPo charge management (when USB-C present) |
| Boost Converter | MT3608 | LiPo to regulated 5V system rail |
| Connectors | JST-SH 1.0mm (4-pin, 6-pin) | Typed peripheral docking |

---

## Enclosure Specifications

- **Material:** PETG (80C thermal tolerance — critical for speaker amp heat)
- **Mounting:** Slot-in slide (dovetail/T-slot rail system)
- **Overhangs:** 45deg max on slide rails to print support-free
- **Node Base dock:** M2 heat inserts for wall-mount screws
- **Peripherals:** Press-fit slide rails (no screws)
- **LCD cutout:** 71x27mm rectangular window on dock front face, 3mm bezel, M3 standoff mounting posts
- **Design order:** Peripherals first → measure rails → dock second (with matching slots + JST header positions)

---

## Sample Rate and Audio Format

- **Sample rate:** 16kHz mono
- **Bit depth:** 16-bit signed little-endian (S16LE)
- **Compression:** None — raw PCM. No Opus on-device
- **Rationale:** ESP32 cycles are scarce. Opus encoding adds latency and CPU load. LAN bandwidth is free. Raw PCM at 32KB/s is trivially handled by 2.4GHz WiFi.
- **Transport:** Binary PCM over WebSocket; JSON control over MQTT

---

*These decisions are sourced verbatim from NOTES.md (2026-04-18) and are the authoritative reference for all hardware and firmware work.*

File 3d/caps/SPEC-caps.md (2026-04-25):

# Xentient Peripheral Caps — Specification Sheet

**Date:** 2026-04-25  
**Framework Reference:** §4 (Peripheral Cap Specifications)  
**Mating Protocol:** §2 (Universal Sled & Socket)

---

## Universal Sled Parameters

All caps share the same base dimensions per Framework §2:

| Parameter | Value | Notes |
|---|---|---|
| Male width | 23.6mm | 0.4mm clearance in 24.0mm female socket |
| Male height | 15.6mm | 0.4mm clearance in 16.0mm female socket |
| Insertion depth | 10.0mm | Matches female pocket depth |
| Draft angle | 1° | Wedge fit, no binding |
| Wire channel | 18×8mm | Passes JST XH 2.54mm 6-pin connector |
| Flange | +2mm each side | Sits flush against hub exterior |
| Material | PETG | Mandatory for Speak (amp heat), recommended for all |

---

## Housing 1: Listen (INMP441 MEMS Mic)

| Parameter | Value | Status |
|---|---|---|
| File | `caps/housing_listen.scad` | ✅ Draft |
| Component | INMP441 MEMS mic (8×8mm PCB) | — |
| Connection | 6-pin JST XH (I2S: VCC, GND, WS, SCK, SD, L/R) | — |
| Socket | 270° (opposite speaker, no feedback) | — |
| Extension | ~10mm from hub face | — |
| Form | Low-profile dome | — |
| Features | 3×3 pinhole array (1mm holes), internal PCB slot | — |
| Print notes | No supports needed (dome < 45°) | ⬜ Verify |

### Assembly Checklist
- [ ] INMP441 board slides into internal slot
- [ ] 6-pin JST pigtail routed through wire channel
- [ ] L/R select pin configured (GND = left channel per validation 1xi)
- [ ] 100nF decoupling cap soldered on VCC line

---

## Housing 2: Speak (MAX98357A + 3W Speaker)

| Parameter | Value | Status |
|---|---|---|
| File | `caps/housing_speak.scad` | ✅ Draft |
| Component | MAX98357A (7×7mm) + 3W 8Ω speaker (40mm dia) | — |
| Connection | 6-pin JST XH (I2S: VCC, GND, DIN, BCLK, LRC, GAIN) | — |
| Socket | 90° (near USB-C, ventilation access) | — |
| Extension | ~22mm from hub face (speaker flare) | — |
| Form | Trapezoidal flare (40mm speaker > 24mm sled) | — |
| Features | Speaker grille, thermal divider, top/bottom vents, asymmetric offset | — |
| Print notes | Supports likely for overhanging flare | ⬜ Verify |

### Critical Design Notes
- **Speaker (40mm) > Sled (24mm)**: Housing flares outward asymmetrically
- **Thermal divider**: Separates MAX98357A heat zone from speaker magnet
- **Ventilation slits**: Top and bottom for amp heat dissipation
- **Offset**: 3mm shift to avoid blocking neighboring caps

### Assembly Checklist
- [ ] MAX98357A placed behind thermal divider
- [ ] 40mm speaker seated in cutout with grille facing out
- [ ] 6-pin JST pigtail routed through wire channel
- [ ] GAIN pin configuration (SD_MODE: pull to VCC for 15W, GND for mute)

---

## Housing 3: Climate (BME280)

| Parameter | Value | Status |
|---|---|---|
| File | `caps/housing_climate.scad` | ✅ Draft |
| Component | BME280 breakout (13×10mm) + 100nF cap | — |
| Connection | 6-pin JST XH (I2C: VCC, GND, SDA, SCL, NC, NC) — 4 active | — |
| Socket | 150° (away from heat sources) | — |
| Extension | 15mm minimum from hub face | — |
| Form | Standoff vented box | — |
| Features | 4-sided louvered gills (4 slits/side), BME shelf, 15mm standoff | — |
| Print notes | No supports for gills (horizontal slits) | ⬜ Verify |

### Critical Design Notes
- **15mm standoff MANDATORY**: BME280 must be far from hub heat (ESP32/battery)
- **4-sided ventilation**: Maximum passive airflow for accurate readings
- **6-pin JST with 2 NC pins**: BOM only has 4-pin and 6-pin JST; use 6-pin, leave 2 unused

### Assembly Checklist
- [ ] BME280 board seated on internal shelf
- [ ] 6-pin JST pigtail (4 active wires + 2 empty)
- [ ] 100nF decoupling cap on VCC line
- [ ] Verify I2C address 0x76 per validation 1xi

---

## Housing 4: Motion (HC-SR501 PIR)

| Parameter | Value | Status |
|---|---|---|
| File | `caps/housing_motion.scad` | ✅ Draft |
| Component | HC-SR501 PIR (23×23mm board, 15mm dome) | — |
| Connection | 4-pin JST XH (VCC, GND, OUT, NC) — 3 active + 1 NC | — |
| Socket | 210° (human detection height) | — |
| Extension | ~18mm from hub face | — |
| Form | Recessed shroud | — |
| Features | 15.5mm Fresnel lens cutout, 2× 3mm adjustment holes | — |
| Print notes | No supports needed | ⬜ Verify |

### Critical Design Notes
- **3-pin JST not in BOM**: Using 4-pin JST with 1 NC pin (4th pin unused/floats)
- **PIR NOT wired in firmware yet** (per validation audit 2026-04-25) — hardware only for now
- **Adjustment holes**: Allow screwdriver access to Sensitivity and Delay potentiometers without disassembly

### Assembly Checklist
- [ ] HC-SR501 board seated in recessed shelf
- [ ] Fresnel lens dome protrudes through 15.5mm cutout
- [ ] 4-pin JST pigtail (3 active: VCC, GND, OUT + 1 NC)
- [ ] Potentiometer access holes aligned with PIR trimmers
- [ ] **FIRMWARE TODO**: Wire PIR interrupt on GPIO13 (bead 2ux pending)

---

## Housing 5: Sight (ESP32-CAM)

| Parameter | Value | Status |
|---|---|---|
| File | `caps/housing_sight.scad` | ✅ Draft |
| Component | ESP32-CAM-MB dual-board (40×27mm) | — |
| Connection | 4-pin JST XH (UART: VCC, GND, TX, RX) | — |
| Socket | 30° (high visibility, clear LOS) | — |
| Extension | Ball joint + articulated head | — |
| Form | Ball joint head (separate print) | — |
| Features | 15.5mm lens cutout, thin wall near antenna (<1.5mm), M2 board mounts | — |
| Print notes | **Two-part print**: socket side (sled+socket) and head (ball+lens) | ⬜ Verify |

### Critical Design Notes
- **UART2 remap**: GPIO2(TX)/GPIO12(RX) — NOT GPIO1/3 (conflict with UART0)
- **Antenna wall**: Must be <1.5mm thick near WiFi antenna trace
- **Ball joint**: Socket on sled side, ball on head side, ~25° articulation range
- **Camera level**: Level 1 (snapshot feed) per camera architecture decision

### Assembly Checklist
- [ ] Socket side printed and attached to sled
- [ ] Camera head printed separately (ball joint on back)
- [ ] ESP32-CAM board mounted with 2× M2 screws
- [ ] 4-pin JST pigtail (UART2: VCC, GND, GPIO2, GPIO12)
- [ ] OV2640 lens centered in front cutout
- [ ] UART2 wiring: ESP-CAM GPIO2 → NodeBase GPIO16, GPIO12 → GPIO17

---

## Housing 6: Display (LCD 16×2 + PCF8574)

| Parameter | Value | Status |
|---|---|---|
| File | `caps/housing_display.scad` | ✅ Draft |
| Component | LCD 16×2 + PCF8574 backpack (71×26×15mm) | — |
| Connection | 4-pin JST XH (I2C: VCC, GND, SDA, SCL) | — |
| Socket | CENTER FRONT (dedicated, not side port) | — |
| Extension | ~18mm flare from sled to bezel | — |
| Form | Flared monitor (24mm sled → 75×30mm bezel) | — |
| Features | 71×27mm window, 4× M3 standoffs for backpack, snap-fit backplate | — |
| Print notes | Supports for overhanging flare | ⬜ Verify |

### Critical Design Notes
- **EXCLUSIVE**: Only fits center front socket (per Framework §2)
- **Rapid flare**: 24×16mm sled expands to 75×30mm bezel
- **Separate backplate**: Snap-fit enclosure, M3 screws into heat-set inserts

### Assembly Checklist
- [ ] LCD + PCF8574 backpack mounted on M3 standoffs
- [ ] 4-pin JST pigtail (I2C: VCC, GND, SDA, SCL)
- [ ] Verify I2C address (0x27 default for PCF8574)
- [ ] Snap-fit backplate installed
- [ ] LCD contrast pot accessible through backplate opening

---

## Anchor 1: Wall Plate Adapter

| Parameter | Value | Status |
|---|---|---|
| File | `anchors/anchor_wall_plate.scad` | ✅ Draft |
| Socket | Rear universal anchor (40mm dia, 6mm deep) | — |
| Plate | 60×60mm flat plate, 6mm thick | — |
| Features | Cross-keys (anti-rotation), 4× M3 countersunk holes, 15mm cable hole | — |
| Print notes | No supports needed | ⬜ Verify |

### Assembly Checklist
- [ ] Male cylinder seats fully in hub rear anchor
- [ ] Cross-keys engage anti-rotation channels
- [ ] 4× M3 screws into wall anchors
- [ ] USB-C cable routed through 15mm center hole (optional)

---

## Anchor 2: Desk Pedestal

| Parameter | Value | Status |
|---|---|---|
| File | `anchors/anchor_desk_pedestal.scad` | ✅ Draft |
| Socket | Rear universal anchor (40mm dia, 6mm deep) | — |
| Base | 80×70mm weighted wedge, 15° upward tilt | — |
| Features | Cross-keys, hollow cable routing channel, weight fill pocket | — |
| Print notes | No supports, fill pocket with sand/metal for stability | ⬜ Verify |

### Assembly Checklist
- [ ] Male cylinder seats in hub rear anchor
- [ ] Weight fill pocket loaded (sand, BBs, or metal plate)
- [ ] USB-C cable routed through internal channel
- [ ] Hub angled 15° upward for optimal viewing/mic pickup

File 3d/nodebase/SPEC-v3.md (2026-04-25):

# Xentient NodeBase V3.1 — Specification Sheet

**Version:** 3.1 (Atrium + Shell Features Restored)  
**File:** `v3.scad`  
**Date:** 2026-04-25  
**Status:** Shell geometry complete with rail slots, keyways, pits, and landing pads. Interior modules and peripherals in progress.

---

## 1. What V3.1 Is

A **hollow shell with essential mounting features** — the truncated hex-pyramid hub with port pockets, sleeves, ventilation, USB-C cutout, rear anchor, PLUS rail slots, alignment keyways, reference pits, and landing pads. Interior plates (Zone A/B/C trays) remain separate module files.

### Design Intent

The shell provides the geometry for both assembly paths:
- **Path A (Printed Plates):** Print Zone A/B/C tray/plate modules that slide into rail slots and screw onto bosses. Keyways provide angular orientation.
- **Path B (Glue-In Standoffs):** Skip printed plates. Glue physical M3/M2 standoffs onto landing pads at reference pit locations. Faster for one-off prototypes.

Both paths require the shell to be printed first, then interior components installed.

---

## 2. What Is IN the Print (V3 Shell)

| Feature | Spec | Status |
|---|---|---|
| Outer hex pyramid body | 150mm base F2F → 60mm front F2F, 90mm depth | ✅ Done |
| Collar (straight section) | 12mm tall, full base radius, aesthetic ribs | ✅ Done |
| 6× Side port pockets | 24.4×16.4mm, 10mm depth, 1° draft | ✅ Done |
| 6× Pocket sleeves | 2mm wall, recessed 10mm inward | ✅ Done |
| 1× Front center pocket | Same socket spec, for Display Cap | ✅ Done |
| Front sleeve | Same sleeve spec, vertical orientation | ✅ Done |
| USB-C cutout | 12×6mm, collar face, floor overcut for thick plugs | ✅ Done |
| Ventilation gills | 4 slits/face, 3 alternate faces, 2 rows (collar + mid-body) | ✅ Done |
| Rear anchor pocket | 40mm dia, 6mm deep, anti-rotation cross-keys | ✅ Done |
| Collar aesthetic ribs | 6× at 0°,60°,120°,180°,240°,300° | ✅ Done |
| Breakout PCB mounting lips | 2mm flange, M2 holes in each pocket sleeve | ✅ Done |
| Rail slots (6× at hex vertices) | 3.5mm wide × 2mm deep, collar zone Z=3–12 | ✅ Done (V3.1) |
| Alignment keyways (3×) | 1.6mm grooves at 0°, 120°, 240° | ✅ Done (V3.1) |
| Reference pits (Zone A/B/C) | 0.5mm deep × 1.5mm dia dimples | ✅ Done (V3.1) |
| Landing pads (Zone B) | 8mm dia × 0.5mm raised, Path B glue targets | ✅ Done (V3.1) |

---

## 3. What Is NOT in the Print (Separate Modules)

These remain as **separate .scad files** — not printed as part of the shell.

| Feature | File | Why Separate | Status |
|---|---|---|---|
| Zone A tray (battery/power) | `zone_a_tray.scad` | Needs clip-in pockets, slides into rail slots | ⬜ Not started |
| Zone B plate (master board) | `zone_b_plate.scad` | 120×80mm flat mount, can't be glued standoffs | ⬜ Not started |
| Zone C plate (ESP32) | `zone_c_plate.scad` | Board mount + anti-rotation, slides into rail slots | ⬜ Not started |
| Battery cradle | Part of `zone_a_tray.scad` | Integrated into tray | ⬜ Not started |
| Power module clips | Part of `zone_a_tray.scad` | Integrated into tray | ⬜ Not started |
| Master board standoffs | Part of `zone_b_plate.scad` | Integrated into plate | ⬜ Not started |
| ESP32 standoffs | Part of `zone_c_plate.scad` | Integrated into plate | ⬜ Not started |
| LCD standoffs | `caps/housing_display.scad` | Part of Display Cap | ✅ Draft |
| Power module clips (TP4056, MT3608, LDO) | Part of `zone_a_tray.scad` | Integrated into tray | ⬜ Not started |

---

## 4. Shell Features Already Added Back (V3.1)

These subtractive/additive features were restored in V3.1. They must be IN the shell because plates slide into them or they serve as glue targets.

### 4.1 Rail Slots ✅ DONE
- **Location:** 6× hex vertices (0°, 60°, 120°, 180°, 240°, 300°)
- **Spec:** 3.5mm wide × 2mm deep grooves, collar zone only (Z=3 to Z=12)
- **Purpose:** Path A plates slide into these for angular alignment

### 4.2 Alignment Keyways ✅ DONE
- **Location:** 3× grooves at 0°, 120°, 240° on cavity walls
- **Spec:** 1.6mm wide × 1.6mm deep subtractive grooves
- **Purpose:** Angular orientation for all plates regardless of assembly path

### 4.3 Reference Pits ✅ DONE
- **Location:** Zone A/B/C mounting coordinates
- **Spec:** 0.5mm deep × 1.5mm diameter subtractive dimples
- **Purpose:** Easier to locate with drill/glue tip than additive bumps. Path B glue targets.

### 4.4 Landing Pads ✅ DONE (Path B)
- **Location:** Zone B standoff coordinates (±57, ±37) at Z=20
- **Spec:** 8mm diameter × 0.5mm raised circles on inner cavity wall
- **Purpose:** Flat glue surfaces for physical M3 standoffs

### 4.4 Landing Pads (Path B glue targets)

- **Location:** Zone B standoff coordinates (±57, ±37) at Z=20
- **Spec:** 8mm diameter, 0.5mm raised circles on cavity wall
- **Why in shell:** Flat glue surfaces for physical M3 standoffs
- **Priority:** P2 — Path B only; Path A uses printed bosses

---

## 5. Parts That CANNOT Be Replaced by Glued Standoffs

These components need **printed plates/trays**, not just glue-in standoffs:

| Part | Why Printed, Not Glued | Status |
|---|---|---|
| **Zone B Plate** (master board) | Board is 120×80mm — too large for 4 standalone standoffs to hold rigidly without a plate connecting them. Needs cross-bracing and a flat mounting surface with chamfered corners. | ⬜ Not started |
| **Zone A Tray** | Battery holder needs clip-in pockets with retaining lips. TP4056/MT3608/LDO need positioning clips. A flat plate is the only way to locate these precisely. | ⬜ Not started |
| **Zone C Plate** | ESP32 board needs precise 4× M2 standoff positions + anti-rotation nub. Could use glue-in standoffs for Path B, but printed plate is more reliable. | ⬜ Not started |

### Parts That CAN Use Glued Standoffs (Path B)

| Part | Path B Approach | Tradeoff |
|---|---|---|
| ESP32 (Zone C) | Glue M2 standoffs at reference pit locations | Less precise alignment, but works |
| LCD (Display Cap) | Printed separately as a cap — not in shell | Same for both paths |

---

## 6. Fit-In Parts Checklist

### Hardware (Not Printed)

- [ ] 4× M3 heat-set brass inserts (Zone A bosses, if Path A)
- [ ] 4× M3 heat-set brass inserts (Zone B bosses, if Path A)
- [ ] 4× M2 heat-set brass inserts (Zone C, if Path A)
- [ ] 4× M2 heat-set brass inserts (LCD, in Display Cap)
- [ ] M3×6 screws (Zone A tray → shell)
- [ ] M3×8 screws (Zone B plate → shell)
- [ ] M2×4 screws (PCB mounts)
- [ ] M2×6 screws (Zone C plate → shell)
- [ ] 6× JST XH 2.54mm female headers (per socket)
- [ ] 1× JST XH 2.54mm female header (front display socket)
- [ ] 18650 battery holder (clip-in, ~78×22×19mm)
- [ ] Nylon or brass M3 standoffs (Path B: 4× for Zone B, glue-in)
- [ ] Nylon or brass M2 standoffs (Path B: 4× for Zone C, glue-in)
- [ ] Cyanoacrylate (super glue) + 120-grit sandpaper (Path B only)
- [ ] PETG-specific plastic cement (optional, for permanent bonds)

### Printed Modules (Separate .scad Files)

- [ ] `zone_a_tray.scad` — Battery cradle + power module clips + wire chimney
- [ ] `zone_b_plate.scad` — Master board mount + cross-brace + wire chimney + chamfered corners
- [ ] `zone_c_plate.scad` — ESP32 mount + anti-rotation nub + wire chimney
- [ ] `display_cap.scad` — LCD 16×2 housing + bezel + snap-fit backplate

### Peripheral Caps (Separate .scad Files — See §4 of Framework)

- [ ] `housing_listen.scad` — INMP441 MEMS mic (low-profile dome, pinhole array)
- [ ] `housing_speak.scad` — MAX98357A + 3W 8Ω speaker (trapezoidal flare, thermal divider)
- [ ] `housing_climate.scad` — BME280 (vented standoff box, 15mm extension, gill slits)
- [ ] `housing_motion.scad` — HC-SR501 PIR (recessed shroud, 15.5mm lens cutout, adjustment holes)
- [ ] `housing_sight.scad` — ESP32-CAM (articulated ball joint head, lens cutout, thin antenna wall)
- [ ] `housing_display.scad` — LCD 16×2 + PCF8574 (flared monitor, 75×30mm bezel, snap-fit)

### Anchor Adapters (Separate .scad Files — See §5 of Framework)

- [ ] `anchor_wall_plate.scad` — 40×6mm male cylinder → 60×60mm wall plate
- [ ] `anchor_desk_pedestal.scad` — Weighted wedge, 15° tilt, cable routing

---

## 7. Assembly Path Decision Matrix

| Step | Path A (Printed Plates) | Path B (Glue-In Standoffs) |
|---|---|---|
| 1 | Print shell with rail slots, keyways, bosses | Print shell with landing pads, reference pits |
| 2 | Heat-set M3/M2 inserts into bosses | Scuff landing pads with sandpaper |
| 3 | Print Zone A tray, test-fit | Glue M3 standoffs at Zone B coords |
| 4 | Slide Zone A tray into rail slots at Z=3 | Glue battery holder to floor (Y=−25mm) |
| 5 | Wire battery → TP4056 → MT3608/LDO | Glue TP4056/MT3608 near USB-C wall |
| 6 | Print Zone B plate, mount board | Mount board on glued standoffs |
| 7 | Slide Zone B plate into rail slots at Z=20 | Glue M2 standoffs at Zone C coords |
| 8 | Route wires through chimney | Wire and assemble |
| 9 | Print Zone C plate, mount ESP32 | — |
| 10 | Slide Zone C plate, secure M2×6 | — |
| 11 | Wire JST connectors | — |

---

## 8. Print Settings

| Setting | Value |
|---|---|
| Material | **PETG** (mandatory — PLA will warp near amp heat) |
| Layer height | 0.2mm |
| Overhangs | 45° max (support-free design) |
| Wall count | 3+ (perimeters for 3mm shell) |
| Infill | 20% gyroid (structural shell) |
| Build plate adhesion | Brim recommended (large flat base) |
| Orientation | Base (150mm F2F) flat on bed, rear face down |
| Supports | **None required** — all overhangs ≤ 45° |

---

## 9. Port Assignment Reference

| Face Angle | Peripheral | JST Pins | Notes |
|---|---|---|---|
| 30° | Sight (ESP32-CAM) | 4-pin (UART) | High visibility, clear LOS |
| 90° | Speak (MAX98357A) | 6-pin (I2S) | Near USB-C, ventilation |
| 150° | Climate (BME280) | 6-pin (I2C, 4 active) | Away from heat sources |
| 210° | Motion (HC-SR501) | 4-pin (1 active + NC) | Human detection height |
| 270° | Listen (INMP441) | 6-pin (I2S) | Opposite speaker, no feedback |
| 330° | Reserved (future) | — | Expansion slot |
| Front | Display (LCD 16×2) | 4-pin (I2C) | Dedicated center socket |

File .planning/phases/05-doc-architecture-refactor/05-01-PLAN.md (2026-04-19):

---
phase: 05-doc-architecture-refactor
plan: 01
type: execute
wave: 1
depends_on: []
files_modified:
  - docs/VISION.md
  - docs/NON_GOALS.md
  - docs/HARDWARE.md
  - README.md
autonomous: true
requirements:
  - DOC-01
  - DOC-02
  - DOC-03
  - DOC-06
  - DOC-07

must_haves:
  truths:
    - "VISION.md contains the bridge model (Xentient = IoT terminal, not AI brain), integration tiers (basic/hermes+mem0/openclaw/archon), and Spaces/Modes primitives"
    - "NON_GOALS.md explicitly lists what Xentient is NOT, including no Archon in v1 demo"
    - "HARDWARE.md contains B1-B7 decisions verbatim from NOTES.md"
    - "README.md reads as a 60-second pitch aligned with the bridge model"
    - "Archon contradiction is resolved: included as P9 in Platform Track, explicitly deferred in demo scope"
    - "Three-tier architecture explicit: Hardware / Core (Runtime + Web Control Panel) / AI Brain (Hermes, Mem0, OpenClaw, Archon)"
    - "'Tool Router' renamed to 'Brain Router' — it is the routing layer between Core and the AI Brain tier"
  artifacts:
    - path: "docs/VISION.md"
      provides: "L1 vision document with bridge model, integration tiers, architecture diagram, Spaces/Modes"
      min_lines: 80
    - path: "docs/NON_GOALS.md"
      provides: "Explicit exclusion list for v1 and Platform Track"
      min_lines: 30
    - path: "docs/HARDWARE.md"
      provides: "Locked B1-B7 decisions, BOM, enclosures, LCD spec"
      min_lines: 60
    - path: "README.md"
      provides: "60-second pitch with bridge model framing"
      min_lines: 20
  key_links:
    - from: "docs/VISION.md"
      to: "docs/repurpose.md"
      via: "content derivation"
      pattern: "bridge model|IoT terminal|integration tiers"
    - from: "docs/HARDWARE.md"
      to: "NOTES.md"
      via: "verbatim B1-B7 extraction"
      pattern: "B1\\.|B2\\.|B3\\.|B4\\.|B5\\.|B6\\.|B7\\."
---

<objective>
Create the four foundational L0/L1 documents that anchor the entire documentation restructure. VISION.md promotes repurpose.md into the canonical vision. NON_GOALS.md draws hard boundaries. HARDWARE.md preserves all locked decisions verbatim. README.md becomes the 60-second pitch.

Purpose: These four docs are the source of truth that all other L2 specs will reference. They must be written first because CONTRACTS, PACKS, SPACES, and INTEGRATIONS all derive from them.

Output: docs/VISION.md, docs/NON_GOALS.md, docs/HARDWARE.md, README.md
</objective>

<execution_context>
@$HOME/.claude/get-shit-done/workflows/execute-plan.md
@$HOME/.claude/get-shit-done/templates/summary.md
</execution_context>

<context>
@.planning/PROJECT.md
@.planning/ROADMAP.md
@.planning/STATE.md
@.planning/phases/05-doc-architecture-refactor/05-CONTEXT.md
@.planning/phases/05-doc-architecture-refactor/05-RESEARCH.md
@docs/repurpose.md
@NOTES.md
@README.md
@xentient.md

<interfaces>
From NOTES.md (source of truth for B1-B7):
- B1: Harness Retry Bug — auto-retry max 3, exponential backoff, p-retry library, state machine
- B2: Shared Data Contract — Zod schemas, camelCase, epoch-millis uint32, v:1 field, 3KB cap, peripheral ID registry
- B3: Node Base Firmware — 16kHz mono PCM S16LE, raw PCM no Opus, DMA ring buffer, FreeRTOS priorities, ArduinoWebsockets + PubSubClient + ArduinoJson v7
- B4: EEPROM Enumeration DROPPED — compile-time peripheral map in firmware/config/peripherals.h
- B5: JST Connectors — 4-pin (I2C) and 6-pin (I2S), pigtail wiring, heatshrink color code
- B6: Enclosures — PETG, slot-in slide mount, design peripherals first then dock, 45deg max overhangs
- B7: LCD Display — I2C 16x2 PCF8574 at 0x27, core to Node Base dock, dual-mode expressive + functional, LiquidCrystal_I2C library

From repurpose.md (source for VISION.md):
- Bridge model architecture diagram
- Integration tiers: basic/hermes+mem0/openclaw/archon
- Spaces model with SpaceMode state machine
- Tool Router handler table (8 handler types)
- What Xentient owns vs delegates table
- Post-demo migration path P1-P8
- Demo day narrative (ships current harness as-is)
</interfaces>
</context>

<tasks>

<task type="auto" tdd="false">
  <name>Task 1: Create VISION.md from repurpose.md</name>
  <files>docs/VISION.md</files>
  <read_first>
    docs/repurpose.md
    .planning/phases/05-doc-architecture-refactor/05-CONTEXT.md
  </read_first>
  <action>Promote docs/repurpose.md into docs/VISION.md as the canonical L1 vision document. This is NOT a copy — it is a curated promotion with the following changes:

1. Remove the "Date / Status / Scope / Author" header preamble — VISION.md is evergreen, not dated.

2. Keep the "The Reframe" section exactly as-is (per D1).

3. Keep the "What Xentient Owns vs What It Delegates" table (per D1, D2).

4. Keep the "Integration Flexibility Principle" section with the 4 integration tiers (per D2):
   - basic (direct LLM, no memory)
   - hermes+mem0 (default)
   - hermes+mem0+openclaw (computer use)
   - hermes+mem0+openclaw+archon (coding workflows)

5. Keep the "Architecture: The Bridge Model" section with the full ASCII architecture diagram. Update the diagram to show the three-tier model explicitly: **Tier 1 Hardware** (Node Bases + peripherals) ↔ **Tier 2 Core** (always-on hosted: Runtime daemon + Web Control Panel, both sharing the same codebase) ↔ **Tier 3 AI Brain** (remote/sandboxed: Hermes, Mem0, OpenClaw, Archon). Add a paragraph noting the Core runs live 24/7 because it owns hardware state; Web Control Panel is Face B of the same Core, providing hardware config, pack/space/permission management, and integration toggles.

6. Keep the "Spaces: Identity, Permissions, Modes" section with Space interface, SpaceMode type, mode transition diagram, and Space examples table (per D3, D4).

7. Keep the "Integration Details" section (Hermes, Mem0, OpenClaw, Archon).

8. Rename the "Tool Router" section to "Brain Router" with handler table (per D5). Brain Router = the routing layer inside Core that dispatches handler invocations across the three tiers (Hardware via MQTT, Core-local basic LLM, or AI Brain tier via Hermes/OpenClaw/Archon adapters).

9. Keep the "Communication Layer: Server Architecture" section (per D6).

10. Keep the "Concrete Demo: Daily Prayer Workflow" section.

11. Keep the "Post-Demo Migration Path" section but update the table to P1-P9 (per D10, D17). Order: P1 Hermes Adapter, P2 Mem0 Integration, P3 Mode Manager, P4 Space Manager, P5 Pack Loader v2, P6 Web Control Panel (NEW — Core's second face: hardware config UI, sleep state control, pack/space/permission management, integration toggles, live telemetry), P7 Communication Bridge (REST/WS/MQTT bridge between Core and AI Brain tier), P8 OpenClaw Adapter, P9 Archon Adapter.

12. Keep the "Glossary" section.

13. KEEP the "Demo Day (Apr 24) — What Ships" section verbatim — it is critical context.

14. KEEP the "Preserved Context: Pre-Reframe Decisions" section — hardware decisions must be referenceable.

15. REMOVE the "Open Questions" section — those belong in individual spec docs, not the vision.

16. ADD a document header: "# Xentient Vision\n\n> The authoritative vision document. Describes what Xentient is, what it owns, what it delegates, and how it evolves post-demo."

17. ADD a "Document Layer" note at the top: "L1 Vision — Defines the bridge model and integration architecture. Referenced by all L2 spec docs."

The result should be a clean, authoritative vision document that reads top-to-bottom without redundancy.</action>
  <verify>
    grep -c "bridge model\|IoT terminal" docs/VISION.md && echo "VISION: bridge model present"
    grep -c "integration tier\|basic.*hermes\|hermes+mem0" docs/VISION.md && echo "VISION: tiers present"
    grep -c "Space\b.*Mode\|SpaceMode\|sleep.*listen.*active.*record" docs/VISION.md && echo "VISION: Spaces/Modes present"
    grep -c "P1.*P8\|Hermes Adapter\|Post-Demo Migration" docs/VISION.md && echo "VISION: migration path present"
    grep -c "Archon" docs/VISION.md && echo "VISION: Archon included (not omitted)"
    test $(wc -l < docs/VISION.md) -ge 80 && echo "VISION: minimum line count met"
  </verify>
  <done>VISION.md exists as the canonical L1 vision document with bridge model, integration tiers, Spaces/Modes primitives, Tool Router, and P1-P8 migration path. Archon is included as P8.</done>
</task>

<task type="auto" tdd="false">
  <name>Task 2: Create NON_GOALS.md and HARDWARE.md, rewrite README.md</name>
  <files>docs/NON_GOALS.md, docs/HARDWARE.md, README.md</files>
  <read_first>
    NOTES.md
    .planning/phases/05-doc-architecture-refactor/05-CONTEXT.md
    docs/repurpose.md
    README.md
    xentient.md
  </read_first>
  <action>Create three documents:

**docs/NON_GOALS.md** — Explicit "what Xentient is NOT" list (per D20, D28):

1. Header: "# Xentient Non-Goals\n\n> What Xentient explicitly does NOT do. This list prevents scope creep."

2. Section "v1 Demo Non-Goals (through Apr 24)":
   - No Hermes/Mem0/OpenClaw/Archon integration code ships before demo (per D17)
   - No Pack system, no Space Manager, no Mode Manager (per D17)
   - No Communication Bridge code
   - No Provider SDK npm publish (per D29 — post-demo)
   - No Visual Builder / web UI (per CONTEXT.md deferred ideas)

3. Section "Platform Non-Goals (v1 scope)":
   - No custom DSL — markdown prompts + JSON tools cover 95% of use cases (per D28)
   - No sandboxing / VM isolation — handlers are enum-gated, no eval, no dynamic require (per D28)
   - No versioned pack migrations for v1 — manifest version mismatch = load fails with clear error (per D28)
   - No pack dependencies — packs are flat, self-contained (per D28)
   - No remote pack fetch at boot — local folders only (per D28)
   - No multi-pack active state — one pack at a time (per D28)
   - No Archon full coding agent — P8 basic YAML DAG workflows only (per D10, D11)

4. Section "Out of Scope (future consideration, not v1 or Platform Track P1-P8)":
   - Visual builder / web UI (Xentient-a8u retarget) — future phase (per CONTEXT.md deferred)
   - Pack marketplace / gallery — post-v1
   - Remote pack fetch — v1 NON_GOAL
   - Multi-pack active state — v1 NON_GOAL
   - Custom DSL for behavior scripting
   - Universal slot architecture (v2 hardware target)
   - On-device speech-to-text (STT offloaded for v1 accuracy)

**docs/HARDWARE.md** — Locked B1-B7 decisions, BOM, enclosures, LCD (per D12-D16, D27):

1. Header: "# Xentient Hardware Decisions\n\n> Locked hardware and firmware decisions. Source of truth for B1-B7. These decisions are NOT negotiable — they are the hardware foundation that software builds upon."

2. Section "Decision Lock Table" with each B1-B7 as a subsection:
   - **B1: Harness Retry Bug** — Copy verbatim from NOTES.md "B1. Retry Bug — DECIDED" section: auto-retry max 3, exponential backoff (1s/2s/4s), transient vs fatal distinction, UI fallback, state machine, p-retry library.
   - **B2: Shared Data Contract** — Copy verbatim from NOTES.md "B2. Data Contract — DECIDED" section: source of truth in contracts.ts, Zod schemas, camelCase, epoch-millis uint32, v:1 field, 3KB cap, peripheral ID registry.
   - **B3: Node Base Firmware** — Copy verbatim from NOTES.md "B3. Node Base Firmware — DECIDED" section: 16kHz mono PCM S16LE, raw PCM no Opus, DMA ring buffer, task priorities, ArduinoWebsockets + PubSubClient + ArduinoJson v7.
   - **B4: EEPROM Enumeration — DROPPED** — Copy verbatim from NOTES.md "B4. EEPROM Enumeration — DROPPED" section: compile-time peripheral map, type registry.
   - **B5: JST Connectors** — Copy verbatim from NOTES.md "B5. JST Connectors — DECIDED" section: 4-pin and 6-pin pinouts, pigtail wiring, heatshrink color code.
   - **B6: Enclosures** — Copy verbatim from NOTES.md "B6. Enclosures — DECIDED" section: PETG, slot-in slide mount, design peripherals first then dock.
   - **B7: LCD Display** — Copy verbatim from NOTES.md "B7. LCD Display (NEW) — DECIDED" section: I2C 16x2 at 0x27, dual-mode, display_update contract, LiquidCrystal_I2C library.

3. Section "Bill of Materials" — list the known BOM items from xentient.md: ESP32-WROOM-32, W5500, INMP441, MAX98357A, OV2640, HC-SR501, BME280, I2C 16x2 LCD (PCF8574), TP4056, MT3608, JST-SH connectors.

4. Section "Enclosure Specifications" — PETG, 45deg max overhangs, M2 heat inserts for dock, press-fit for peripherals.

5. Section "Sample Rate & Audio Format" — 16kHz mono PCM S16LE, raw, no on-device compression.

6. Note at bottom: "These decisions are sourced verbatim from NOTES.md (2026-04-18) and are the authoritative reference for all hardware and firmware work."

**README.md** — Rewrite as a 60-second pitch aligned with bridge model (per D1, D20):

1. Title: "# Xentient"
2. One-line description: "The IoT terminal that gives any AI a physical presence in any room."
3. Subtitle/tagline: "Voice. Sensors. Display. Any AI brain can plug in."
4. Section "What It Does" — 3-4 sentence bridge model explanation: Xentient is the bridge between physical rooms and AI brains. The harness is a thin terminal OS. Voice pipeline, MQTT bridge, LCD faces, mode management — that is what Xentient uniquely owns. Intelligence plugs in via Hermes, Mem0, OpenClaw, or basic LLM.
5. Section "Demo Status" — brief note: V1 prototype demo Apr 24, 2026. Voice pipeline + MQTT bridge + LCD + basic memory.
6. Section "Quick Start" — link to docs/VISION.md for full architecture and docs/HARDWARE.md for hardware decisions.
7. Section "Architecture" — 5-line ASCII showing: Node Base (bottom) ↔ Harness (middle) ↔ AI Brain Layer (top). No more than 10 lines total.
8. Section "Documentation" — table linking to VISION.md, HARDWARE.md, NON_GOALS.md, CONTRACTS.md, PACKS.md, SPACES.md.
9. Remove all the old "Interactive Showcase", "Node Builder", "Flow Simulator" language from the current README.

The README should be short (40-60 lines max). Punchy. Bridge-model aligned. No emoji. No marketing fluff.</action>
  <verify>
    grep -c "NOT.*do\|NOT.*build\|No custom DSL\|No sandboxing\|No Archon" docs/NON_GOALS.md && echo "NON_GOALS: explicit exclusions present"
    grep -c "demo.*Apr.*24\|v1.*demo\|Platform Track" docs/NON_GOALS.md && echo "NON_GOALS: demo scope boundaries present"
    grep -c "B1\.\|B2\.\|B3\.\|B4\.\|B5\.\|B6\.\|B7\." docs/HARDWARE.md && echo "HARDWARE: all B1-B7 present"
    grep -c "16kHz mono PCM\|compile-time peripheral\|PETG\|I2C 16x2\|0x27" docs/HARDWARE.md && echo "HARDWARE: key specs present"
    grep -c "IoT terminal\|bridge" README.md && echo "README: bridge model language present"
    grep -c "VISION.md\|HARDWARE.md\|NON_GOALS.md" README.md && echo "README: doc links present"
    test $(wc -l < docs/NON_GOALS.md) -ge 30 && echo "NON_GOALS: minimum line count met"
    test $(wc -l < docs/HARDWARE.md) -ge 60 && echo "HARDWARE: minimum line count met"
  </verify>
  <done>NON_GOALS.md lists all explicit exclusions for v1 demo and Platform Track. HARDWARE.md preserves B1-B7 verbatim. README.md is a 60-second pitch aligned with the bridge model.</done>
</task>

</tasks>

<threat_model>
## Trust Boundaries

| Boundary | Description |
|---|---|
| Documentation reader → project | No trust boundary — docs are public project artifacts, not runtime code |

## STRIDE Threat Register

| Threat ID | Category | Component | Disposition | Mitigation Plan |
|---|---|---|---|---|
| T-05-01 | Repudiation | HARDWARE.md | accept | Static document — version control (git) provides audit trail for changes |
| T-05-02 | Tampering | NON_GOALS.md | mitigate | Scope boundaries are explicit and verifiable; any addition must be tracked in CONTEXT.md decisions |
</threat_model>

<verification>
1. docs/VISION.md exists and contains bridge model, integration tiers, Spaces/Modes
2. docs/NON_GOALS.md exists and lists all explicit exclusions
3. docs/HARDWARE.md exists and contains B1-B7 verbatim
4. README.md rewritten as bridge-model pitch under 60 lines
5. Archon contradiction resolved: P8 in VISION.md, excluded from demo in NON_GOALS.md
</verification>

<success_criteria>
- VISION.md promoted from repurpose.md with bridge model, integration tiers, Spaces/Modes, P1-P8
- NON_GOALS.md explicit about no Archon in v1, no custom DSL, no sandboxing, no pack dependencies
- HARDWARE.md preserves B1-B7 decisions word-for-word from NOTES.md
- README.md is a concise bridge-model pitch, no stale "n8n" or "visual control plane" language
- All 4 files committed to git
</success_criteria>

<output>
After completion, create `.planning/phases/05-doc-architecture-refactor/05-01-SUMMARY.md`
</output>

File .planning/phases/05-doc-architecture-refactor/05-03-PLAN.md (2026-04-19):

---
phase: 05-doc-architecture-refactor
plan: 03
type: execute
wave: 3
depends_on: ["05-01", "05-02"]
files_modified:
  - .planning/ROADMAP.md
  - .planning/PROJECT.md
  - .planning/REQUIREMENTS.md
  - .planning/STATE.md
  - NOTES.md
  - xentient.md
  - .planning/phases/02-harness-intelligence-layer/SUPERSEDED.md
autonomous: true
requirements:
  - DOC-04
  - DOC-05
  - DOC-07

must_haves:
  truths:
    - "ROADMAP.md shows two tracks: Demo Track (frozen scope, Apr 24) and Platform Track (P1-P8, post-capstone)"
    - "NOTES.md is trimmed to append-only decision log with dated entries only; platform/pack/SDK content extracted to L2 specs"
    - "xentient.md shrunk from ~647 lines to ~200 lines as L0 narrative pitch"
    - "PROJECT.md reflects bridge-model vision, not old 'visual control plane' language"
    - "REQUIREMENTS.md has MEM-01/02/03 replaced with delegation reqs and HARN-01 rephrased as voice pipeline"
    - "Phase 2 directory has SUPERSEDED.md marker explaining the bridge reframe"
    - "STATE.md reflects Phase 5 as current focus with doc architecture refactor status"
  artifacts:
    - path: ".planning/ROADMAP.md"
      provides: "Two-track roadmap with Demo Track and Platform Track"
      contains: "Demo Track"
    - path: ".planning/PROJECT.md"
      provides: "Updated project charter with bridge model"
      contains: "bridge"
    - path: ".planning/REQUIREMENTS.md"
      provides: "Updated requirements with delegation reqs"
      contains: "MEM"
    - path: ".planning/STATE.md"
      provides: "Updated project state"
      contains: "Phase 5"
    - path: "NOTES.md"
      provides: "Trimmed append-only decision log"
      max_lines: 100
    - path: "xentient.md"
      provides: "Shrunk narrative pitch (~200 lines)"
      max_lines: 220
    - path: ".planning/phases/02-harness-intelligence-layer/SUPERSEDED.md"
      provides: "Marker explaining bridge reframe superseded phase 2"
      contains: "SUPERSEDED"
  key_links:
    - from: ".planning/ROADMAP.md"
      to: "docs/VISION.md"
      via: "Platform Track P1-P8 references"
      pattern: "P1.*P8|Platform Track"
    - from: ".planning/PROJECT.md"
      to: "docs/VISION.md"
      via: "Core value references bridge model"
      pattern: "bridge|IoT terminal"
---

<objective>
Restructure all existing project documentation to align with the bridge-model vision. Rewrite ROADMAP.md with two-track structure, update PROJECT.md and REQUIREMENTS.md, trim NOTES.md to append-only log, shrink xentient.md to L0 pitch, add SUPERSEDED marker to Phase 2, and update STATE.md.

Purpose: The existing docs still describe the old "n8n-style orchestration" and "visual control plane" vision. This plan rewrites them to reflect the bridge model, ensuring no stale references remain.

Output: Updated ROADMAP.md, PROJECT.md, REQUIREMENTS.md, STATE.md, NOTES.md, xentient.md, SUPERSEDED.md
</objective>

<execution_context>
@$HOME/.claude/get-shit-done/workflows/execute-plan.md
@$HOME/.claude/get-shit-done/templates/summary.md
</execution_context>

<context>
@.planning/phases/05-doc-architecture-refactor/05-CONTEXT.md
@.planning/phases/05-doc-architecture-refactor/05-RESEARCH.md
@.planning/ROADMAP.md
@.planning/PROJECT.md
@.planning/REQUIREMENTS.md
@.planning/STATE.md
@NOTES.md
@xentient.md
@docs/repurpose.md

<interfaces>
From 05-CONTEXT.md decisions:
- D1: Xentient = IoT terminal (bridge), NOT AI brain
- D17: NONE of Platform Track (P1-P8) ships before Apr 24 demo
- D18: Demo ships current harness as-is
- D20: 4-layer doc system (L0 Pitch, L1 Vision, L2 Spec, L3 Phase, L4 Ops)
- D21: xentient.md shrinks from ~647 to ~200 lines
- D22: NOTES.md becomes append-only decision log
- D23: Phase 2 plans marked SUPERSEDED
- D29: Provider SDK documented as Layer 1, post-demo npm publish
- D30: SDK README included in deliverables
</interfaces>
</context>

<tasks>

<task type="auto" tdd="false">
  <name>Task 1: Rewrite ROADMAP.md, update PROJECT.md and REQUIREMENTS.md</name>
  <files>.planning/ROADMAP.md, .planning/PROJECT.md, .planning/REQUIREMENTS.md</files>
  <read_first>
    .planning/ROADMAP.md
    .planning/PROJECT.md
    .planning/REQUIREMENTS.md
    .planning/phases/05-doc-architecture-refactor/05-CONTEXT.md
    docs/repurpose.md
  </read_first>
  <action>Rewrite three L2 planning documents:

**.planning/ROADMAP.md** — Two-track roadmap (per D17, D18, specific idea 1 from CONTEXT.md):

Replace the current single-track roadmap with a two-track structure:

1. Header: "# Roadmap: Xentient"

2. Section "Overview" — one paragraph: Xentient is the IoT terminal — a thin voice/hardware bridge that lets any AI brain inhabit a physical room. Two tracks: Demo Track (frozen scope, April 24 presentation) and Platform Track (post-capstone evolution, P1-P8).

3. Section "Demo Track (Frozen — Through Apr 24)" with a table:
   | Phase | Goal | Status |
   | 1: Node Base & Comms | ESP32 firmware + MQTT telemetry | Not started |
   | 2: Harness & Intelligence | Voice pipeline + memory (SUPERSEDED by bridge reframe — see below) | Superseded |
   | 3: Web-Control & Assembly | Dashboard + hardware assembly | Not started |
   | 4: Optimization & Demo Prep | Latency + demo narrative | Not started |
   | 5: Doc Architecture Refactor | Restructure docs to bridge model | In progress |

4. Section "Platform Track (Post-Capstone — Apr 25+)" with the P1-P9 table (three-tier architecture — Hardware / Core / AI Brain):
   | Phase | What | LOC Impact | Dependency |
   | P1: Hermes Adapter | Replace custom LLM+memory loop with Hermes connection | -300 LOC, +80 LOC | Hermes installed |
   | P2: Mem0 Integration | Add Mem0 as Hermes plugin + direct API fallback | +30 LOC | Mem0 Docker |
   | P3: Mode Manager | sleep/listen/active/record state machine | +60 LOC | None |
   | P4: Space Manager | Space context + MQTT contract + permissions | +100 LOC | P3 |
   | P5: Pack Loader v2 | New handler types, space awareness | +60 LOC | P1, P4 |
   | P6: Web Control Panel (Core Face B) | Browser UI for hardware config, pack/space/permission mgmt, integration toggles, live telemetry | +600 LOC (new surface) | P3, P4, P5 |
   | P7: Communication Bridge | REST/WS/MQTT bridge between Core and AI Brain tier | +100 LOC | P1 |
   | P8: OpenClaw Adapter | Computer-use handler (sandboxed/remote machine) | +60 LOC | P5, P7 |
   | P9: Archon Adapter | Basic YAML DAG workflow delegation | +50 LOC | P5, P7 |

5. Section "Phase Details" — keep Phase 1, 3, 4, 5 details from current ROADMAP (update Phase 5 to reflect completed planning). For Phase 2, add a note: "**Phase 2 is SUPERSEDED.** The n8n-style orchestration vision has been replaced by the bridge model (see docs/VISION.md). The custom memory layer (MEM-01/02/03) will be replaced by Hermes+Mem0 integration in Platform Track P1-P2. Phase 2 deliverables that still ship in the demo (voice pipeline, MQTT bridge, basic memory) are carried forward as-is."

6. Section "Progress" — update the table to reflect Phase 5 in progress.

7. Section "Document Architecture" — reference the 4-layer system (L0-L4) from CONTEXT.md D20 with links:
   - L0: README.md (pitch), xentient.md (narrative)
   - L1: docs/VISION.md, docs/NON_GOALS.md
   - L2: docs/CONTRACTS.md, docs/PACKS.md, docs/SPACES.md, docs/HARDWARE.md, docs/INTEGRATIONS/*.md, .planning/*.md
   - L3: .planning/phases/*
   - L4: NOTES.md (decision log), CLAUDE.md, AGENTS.md

**.planning/PROJECT.md** — Update project charter (per D1):

1. Replace "What This Is" paragraph: "Xentient is the IoT terminal — a thin voice/hardware bridge that lets any AI brain inhabit a physical room. The harness is a terminal OS; intelligence plugs in via integration tiers (basic, Hermes+Mem0, OpenClaw, Archon)."

2. Replace "Core Value" from "Modular, zero-friction spatial intelligence through a visual control plane and high-speed AI orchestration" to: "The bridge between physical rooms and any AI brain. Voice, sensors, display — any intelligence can plug in."

3. Replace "Requirements" section:
   - Validated: ARCH-V1, COMMS-V1, MODEL-V1 (keep as-is)
   - Active: Update to reflect bridge model. Remove HARNESS-CORE ("n8n-style visual workflow engine") and MEMORY-HERMES ("Hermes-Agent proactive memory"). Add:
     - VOICE-PIPELINE: STT→LLM→TTS streaming pipeline (current harness, ships in demo)
     - MQTT-BRIDGE: MQTT hardware bridge + VAD (current, ships in demo)
     - LCD-FACE: I2C 16x2 display state machine (B7, ships in demo)
     - HERMES-INTEGRATION: Replace custom memory with Hermes+Mem0 (Platform Track P1-P2)
     - SPACE-MODE-MGR: Mode and Space managers (Platform Track P3-P4)
   - Out of Scope: Add "n8n-style visual orchestration — superseded by bridge model"

4. Replace "Context" paragraph: "Xentient is in V1 demo prep with a hard deadline of April 24, 2026. Post-demo, the architecture shifts from a custom AI brain to a thin terminal that delegates intelligence to best-in-class integrations (Hermes, Mem0, OpenClaw, Archon)."

5. Update "Key Decisions" table:
   - Change "Web App Control Plane" to "Three-Tier Architecture — Hardware / Core (Runtime + Web Control Panel) / AI Brain (Hermes, Mem0, OpenClaw, Archon)"
   - Add: "Core is Always-On — Xentient Core runs live 24/7 on hosted server; owns hardware state; Node Bases reconnect to Core"
   - Add: "Core Has Two Faces — Runtime daemon (machine-facing) + Web Control Panel (human-facing), same codebase"
   - Add: "Brain Router — Core's dispatch layer routing handler calls across the three tiers (replaces 'Tool Router' naming)"
   - Change "Hermes Memory Pattern" to "Mem0 as primary memory layer (P2), Hermes as default brain (P1)"
   - Keep "Cloud LLM Mandatory" as-is
   - Keep "UART Camera Path" as-is
   - Add: "Demo ships current harness as-is — no Platform Track code before Apr 24"

6. Update "Last updated" timestamp to 2026-04-19.

**.planning/REQUIREMENTS.md** — Update requirements (per CONTEXT.md specifics item 6):

1. Keep NODE-01 through NODE-05 as-is (hardware/firmware, still valid).

2. Update HARN-01 from "n8n-style modular processing pipeline" to "Voice pipeline (STT→LLM→TTS) with streaming audio — thin terminal OS, not orchestration engine".

3. Keep HARN-02 (MQTT brokerage) and HARN-04 (audio ingestion) as-is — still valid.

4. Replace HARN-03 "Integration of Cloud LLM APIs" with: "Cloud LLM provider integration for basic mode (direct provider call, no memory, no skills). Post-demo: Hermes integration (Platform Track P1)."

5. Replace MEM-01 "Persistent user profile and context stored in SQLite/FTS5" with: "MEM-01: Delegate memory to Hermes+Mem0 (Platform Track P1-P2). Demo uses current MemoryDB/FactExtractor/MemoryInjector as temporary implementation. Post-demo, custom memory code (memory/ directory) is DELETED and replaced by ~80 LOC HermesAdapter + ~30 LOC Mem0Adapter."

6. Replace MEM-02 "Proactive memory retrieval (LLM reviews history to inject context)" with: "MEM-02: Proactive memory retrieval via Hermes+Mem0 (Platform Track P1-P2). Mem0 provides semantic extraction, recency weighting, entity resolution, and space-scoped tags natively. No custom FactExtractor/MemoryInjector code remains post-demo."

7. Replace MEM-03 "Cross-session identification and greeting based on persistent user model" with: "MEM-03: Cross-session identification via Hermes+Mem0 (Platform Track P1-P2). Mem0 user-scoped tags enable greeting by name and persistent context across sessions. No custom user model code remains post-demo."

8. Add a new section "Platform Track Requirements (Post-Demo)" with entries:
   - PT-01: Hermes Adapter — Replace custom LLM+memory loop with Hermes connection (P1)
   - PT-02: Mem0 Integration — Direct Mem0 API fallback for basic mode (P2)
   - PT-03: Mode Manager — Sleep/listen/active/record state machine (P3)
   - PT-04: Space Manager — Space context + MQTT contract + permissions (P4)
   - PT-05: Pack Loader v2 — New handler types, space awareness (P5)
   - PT-06: Web Control Panel — Core Face B: browser UI for hardware config, pack/space/permission management, integration toggles, live telemetry (P6)
   - PT-07: Communication Bridge — REST/WS/MQTT bridge between Core and AI Brain tier (P7)
   - PT-08: OpenClaw Adapter — Computer-use handler via remote/sandboxed sidecar (P8)
   - PT-09: Archon Adapter — Basic YAML DAG workflow delegation (P9)

9. Keep WEB-01, WEB-02, WEB-03 as-is (still valid for demo).

10. Keep "v2 Requirements (Deferred)" section as-is.

11. Update "Out of Scope" table: Add "n8n-style visual orchestration (superseded by bridge model)" row.

12. Update "Traceability" table to include new PT requirements.

13. Update timestamp to 2026-04-19.</action>
  <verify>
    grep -c "Demo Track\|Platform Track\|P1.*P8" .planning/ROADMAP.md && echo "ROADMAP: two-track structure present"
    grep -c "SUPERSEDED\|bridge reframe\|bridge model" .planning/ROADMAP.md && echo "ROADMAP: Phase 2 superseded note present"
    grep -c "IoT terminal\|bridge\|bridge model" .planning/PROJECT.md && echo "PROJECT: bridge model language present"
    grep -c "visual control plane\|n8n-style" .planning/PROJECT.md || echo "PROJECT: old language removed"
    grep -c "MEM-01\|MEM-02\|MEM-03\|Hermes\|Mem0\|delegat" .planning/REQUIREMENTS.md && echo "REQUIREMENTS: memory delegation present"
    grep -c "PT-0[1-8]\|Platform Track" .planning/REQUIREMENTS.md && echo "REQUIREMENTS: PT requirements present"
    grep -c "voice pipeline\|Voice pipeline" .planning/REQUIREMENTS.md && echo "REQUIREMENTS: HARN-01 rephrased"
  </verify>
  <done>ROADMAP.md rewritten with two-track structure (Demo + Platform). PROJECT.md updated with bridge model. REQUIREMENTS.md updated with delegation reqs and PT requirements. Phase 2 superseded note present.</done>
</task>

<task type="auto" tdd="false">
  <name>Task 2: Trim NOTES.md, shrink xentient.md, add SUPERSEDED marker, update STATE.md</name>
  <files>NOTES.md, xentient.md, .planning/phases/02-harness-intelligence-layer/SUPERSEDED.md, .planning/STATE.md</files>
  <read_first>
    NOTES.md
    xentient.md
    .planning/STATE.md
  </read_first>
  <action>Restructure four files:

**NOTES.md** — Trim to append-only decision log (per D22):

1. Keep the header rule and format: `> **RULE:** All entries are dated and user-approved only.`

2. Keep the Status Snapshot section (updated to current state).

3. Keep ALL dated entries as-is: [2026-04-18] entries for 3D Enclosure Progress, Software Bug, Deep-Plan Seeds, B1-B7 Decisions, Archon/Library decisions, Execution Order.

4. REMOVE the entire "Platform Vision — SDK + Bot Pack Extensibility" section (lines starting with "## [2026-04-18] Platform Vision — SDK + Bot Pack Extensibility" through the end of the glossary). This content now lives in:
   - Layer 1 → docs/VISION.md (integration tiers, bridge model)
   - Layer 2 → docs/PACKS.md (pack folder spec, manifest, lifecycle, guardrails)
   - Layer 2 → docs/SPACES.md (Space model, Mode state machine)
   - Layer 2 → docs/CONTRACTS.md (wire contracts, MQTT topics)
   - Layer 2 → docs/HARDWARE.md (B1-B7 decisions)
   - Layer 2 → docs/INTEGRATIONS/hermes.md, mem0.md, openclaw.md

5. Add a note at the top of the trimmed file (after the rule, before Status Snapshot):
   ```
   > **Note (2026-04-19):** Platform Vision, Pack System, and SDK content has been extracted to L2 spec docs. See docs/VISION.md, docs/PACKS.md, docs/SPACES.md, docs/CONTRACTS.md, docs/HARDWARE.md, and docs/INTEGRATIONS/*.md. This file is now an append-only decision log for hardware/firmware/demo-critical decisions only.
   ```

6. The trimmed NOTES.md should be approximately 200-250 lines (just the header, note, status snapshot, and dated entries through "Execution Order").

**xentient.md** — Shrink from ~647 lines to ~200 lines (per D21):

1. Keep the title and one-line description: "Xentient — A programmable nervous system for intelligent spaces"

2. Keep the "What Xentient Is" paragraph (first 5-6 lines of current intro — the bridge model positioning).

3. Keep the "The Name" section (3 lines).

4. Keep the "Core Principles" section (5 principles — these are timeless).

5. Replace the "Architecture" section with a much shorter version:
   - 4-line ASCII showing: Node Base (bottom) ↔ Harness (middle) ↔ AI Brain Layer (top)
   - One paragraph: "Xentient is built in four layers. The Node Base is dumb hardware. The Harness is a thin terminal OS. The AI Brain Layer (Hermes, Mem0, OpenClaw, Archon) provides intelligence via integration. Basic mode (direct LLM call) always works without any integration."

6. REMOVE the detailed Layer 1-4 descriptions (Node Base details, Peripheral Units, Snap Interface, Typed Slot Architecture, Universal Slot Architecture, Power Architecture, Firmware vs Profile, Node States, Node Roles, Data Modes — all of this is hardware reference material that belongs in HARDWARE.md or xentient.md's full form).

7. Replace with: "See docs/HARDWARE.md for hardware decisions, BOM, and enclosure specs."

8. Keep a shortened "Spaces" section (3-4 lines explaining the concept, pointing to docs/SPACES.md for full spec).

9. Keep a shortened "Integration Tiers" section (3-4 lines explaining basic/hermes+mem0/openclaw/archon, pointing to docs/VISION.md for full architecture).

10. REMOVE: Data Contract section (moved to docs/CONTRACTS.md), Output Streams section, Identity and Privacy section, Hardware Reference section (moved to docs/HARDWARE.md), Lifecycle sections, Roadmap section (moved to ROADMAP.md), What Xentient Is Not section (moved to docs/NON_GOALS.md), Taglines section.

11. Add a "Full Documentation" section at the bottom linking to:
   - docs/VISION.md — Full architecture and integration tiers
   - docs/CONTRACTS.md — Wire format specification
   - docs/PACKS.md — Pack system specification
   - docs/SPACES.md — Space model and Mode state machine
   - docs/HARDWARE.md — Locked hardware decisions (B1-B7)
   - docs/NON_GOALS.md — What Xentient is NOT
   - docs/INTEGRATIONS/ — Integration adapter contracts

12. Target: ~200 lines total. Punchy. Narrative pitch only (L0).

**.planning/phases/02-harness-intelligence-layer/SUPERSEDED.md** (per D23):

Create a new file in the Phase 2 directory:
```markdown
# SUPERSEDED — Bridge Model Reframe

**Date:** 2026-04-19
**Reason:** The "n8n-style orchestration" vision for Phase 2 has been superseded by the bridge model (Xentient = IoT terminal, not AI brain). The custom memory layer (MemoryDB/FactExtractor/MemoryInjector) will be replaced by Hermes+Mem0 integration in Platform Track P1-P2.

**What changed:**
- Phase 2 was originally scoped as "Build the n8n-style orchestration engine and Hermes-Agent memory"
- The bridge reframe means Xentient no longer builds the AI brain — it delegates to Hermes/Mem0/OpenClaw/Archon
- The voice pipeline (STT→LLM→TTS), MQTT bridge, and basic memory still ship in the demo
- Custom memory code (memory/ directory) will be deleted post-demo and replaced by thin adapters

**What still ships in the demo:**
- Voice pipeline (STT→LLM→TTS streaming)
- MQTT hardware bridge + VAD
- Basic memory (MemoryDB/FactExtractor/MemoryInjector — temporary, replaced in P1-P2)
- LCD display (B7)

**What moved to Platform Track (P1-P9):**
- P1: Hermes Adapter (replaces custom LLM+memory loop)
- P2: Mem0 Integration (replaces MemoryDB/FactExtractor/MemoryInjector)
- P3-P9: Mode Manager, Space Manager, Pack Loader v2, Web Control Panel (Core Face B), Communication Bridge, OpenClaw, Archon

**Reference:** See docs/VISION.md for the full bridge model architecture and migration path.
```

**.planning/STATE.md** — Update project state:

1. Update `last_updated` to 2026-04-19.
2. Update `status` to `in-progress`.
3. Update `progress.total_phases` to 5.
4. Update `current focus` to "Phase 5 — doc-architecture-refactor".
5. Update "Recent Decisions" section to include the bridge model reframe:
   - "Bridge model adopted: Xentient = IoT terminal, not AI brain"
   - "4-layer doc system established (L0-L4)"
   - "Phase 2 plans superseded by bridge reframe"
   - "Two-track roadmap: Demo Track (frozen) + Platform Track (P1-P8)"
6. Update milestone status to reflect Phase 5 in progress.</action>
  <verify>
    grep -c "append-only\|L2 spec\|extracted to" NOTES.md && echo "NOTES: extraction note present"
    test $(wc -l < NOTES.md) -le 250 && echo "NOTES: trimmed to reasonable size"
    grep -c "IoT terminal\|bridge\|docs/VISION\|docs/HARDWARE" xentient.md && echo "XENTIENT: bridge model and doc links present"
    test $(wc -l < xentient.md) -le 220 && echo "XENTIENT: shrunk to ~200 lines"
    grep -c "SUPERSEDED\|bridge reframe\|bridge model" .planning/phases/02-harness-intelligence-layer/SUPERSEDED.md && echo "SUPERSEDED: marker present"
    grep -c "Phase 5\|doc-architecture\|bridge model" .planning/STATE.md && echo "STATE: updated for Phase 5"
    ! grep -c "Platform Vision.*SDK\|Bot Pack Extensibility" NOTES.md && echo "NOTES: platform vision section removed"
  </verify>
  <done>NOTES.md trimmed to append-only decision log with platform content extracted to L2 specs. xentient.md shrunk to ~200-line L0 narrative pitch. SUPERSEDED.md added to Phase 2 directory. STATE.md updated for Phase 5.</done>
</task>

</tasks>

<threat_model>
## Trust Boundaries

| Boundary | Description |
|---|---|
| Planning docs → implementation | Stale planning docs could mislead developers into building old architecture |

## STRIDE Threat Register

| Threat ID | Category | Component | Disposition | Mitigation Plan |
|---|---|---|---|---|
| T-05-05 | Tampering | ROADMAP.md, PROJECT.md, REQUIREMENTS.md | mitigate | All old "n8n-style" and "visual control plane" language replaced with bridge model language; SUPERSEDED marker prevents confusion |
| T-05-06 | Repudiation | NOTES.md trim | mitigate | Extraction note in NOTES.md references exactly which docs received the extracted content |
</threat_model>

<verification>
1. ROADMAP.md shows two-track structure (Demo Track + Platform Track P1-P8)
2. PROJECT.md reflects bridge model, not "visual control plane"
3. REQUIREMENTS.md has MEM-01/02/03 replaced with delegation reqs, HARN-01 rephrased
4. NOTES.md is trimmed to append-only decision log (~200-250 lines)
5. xentient.md shrunk to ~200 lines as L0 pitch
6. SUPERSEDED.md exists in Phase 2 directory
7. STATE.md reflects Phase 5 as current focus
8. No stale "n8n-style orchestration" or "visual control plane" language remains in any modified file
</verification>

<success_criteria>
- ROADMAP.md has two tracks: Demo Track (frozen, through Apr 24) and Platform Track (P1-P8, post-capstone)
- PROJECT.md core value and description reflect bridge model
- REQUIREMENTS.md has updated MEM/HARN requirements and new PT-01 through PT-08
- NOTES.md trimmed to dated entries only, platform content extracted
- xentient.md is ~200 lines with links to full docs
- Phase 2 has SUPERSEDED.md explaining the bridge reframe
- STATE.md reflects Phase 5 in progress
- All docs committed to git
</success_criteria>

<output>
After completion, create `.planning/phases/05-doc-architecture-refactor/05-03-SUMMARY.md`
</output>

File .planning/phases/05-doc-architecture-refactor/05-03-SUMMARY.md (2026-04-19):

---
phase: 05-doc-architecture-refactor
plan: 03
subsystem: documentation
tags: [docs, roadmap, bridge-model, requirements, notes-trim, superseded]
dependency_graph:
  requires: ["05-01", "05-02"]
  provides: ["two-track-roadmap", "bridge-model-requirements", "trimmed-notes", "shrunk-xentient", "superseded-marker"]
  affects: [".planning/ROADMAP.md", ".planning/PROJECT.md", ".planning/REQUIREMENTS.md", ".planning/STATE.md", "NOTES.md", "xentient.md", ".planning/phases/02-harness-intelligence-layer/SUPERSEDED.md"]
tech_stack:
  added: []
  patterns: [two-track-roadmap, bridge-model-language, append-only-decision-log, L0-narrative-pitch]
key_files:
  created: [".planning/phases/02-harness-intelligence-layer/SUPERSEDED.md"]
  modified: [".planning/ROADMAP.md", ".planning/PROJECT.md", ".planning/REQUIREMENTS.md", ".planning/STATE.md", "NOTES.md", "xentient.md"]
decisions:
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

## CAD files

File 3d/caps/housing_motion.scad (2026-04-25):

// ==========================================
// Xentient Framework - Housing 4: Motion (HC-SR501 PIR)
// Recessed shroud with Fresnel lens cutout and adjustment holes
// ==========================================
// Component: HC-SR501 PIR (23×23mm board, 15mm dome)
// Connection: 4-pin JST XH pigtail (VCC, GND, OUT, NC)
//              3 active pins, 4th unused (3-pin JST not in BOM)
// Socket: 210° face (human detection height)
// Per Framework §4 Housing 4
// Units: mm

include <sleds.scad>;

$fn = 64;

// ==========================================
// COMPONENT DIMENSIONS
// ==========================================

PIR_Board_W  = 23.0;   // HC-SR501 board width
PIR_Board_H  = 23.0;   // HC-SR501 board height (roughly square)
PIR_Board_T  = 1.6;    // PCB thickness
PIR_Dome_Dia = 15.0;   // Fresnel lens dome diameter
PIR_Dome_H   = 12.0;   // Dome height above board
PIR_Clear    = 0.4;    // Clearance per side

// Potentiometer access holes
Pot_Dia      = 3.0;    // Access hole diameter for screwdriver
Pot_Offset_X = 5.5;    // Distance from board center to pot center
Pot_Offset_Y = 7.0;    // Forward offset

// Housing dimensions
Shroud_W     = 28.0;   // Width of shroud (23mm board + walls)
Shroud_H     = 30.0;   // Height of shroud
Shroud_D     = 18.0;   // Depth of shroud (dome clearance)
House_Wall   = 2.0;    // Wall thickness
Lens_Cutout  = 15.5;   // 15mm dome + 0.5mm clearance
House_Wall2  = 1.5;    // Thin wall near lens dome

// ==========================================
// MODULE: housing_motion()
// ==========================================

module housing_motion() {
    union() {
        // Sled base with flange
        male_sled_with_flange(flange_w=2.0, flange_h=2.0, flange_t=2.0);

        // Recessed shroud body
        translate([0, 0, Sled_D]) {
            difference() {
                // Outer shroud
                hull() {
                    // Transition from sled
                    translate([0, 0, 1])
                        cube([Sled_H + 4, Sled_W + 4, 2], center=true);
                    // Shroud body
                    translate([0, 0, Shroud_D / 2 + 4])
                        cube([Shroud_H, Shroud_W, Shroud_D], center=true);
                }

                // Inner cavity
                hull() {
                    translate([0, 0, 0.5])
                        cube([Sled_H - 2, Sled_W - 2, 2], center=true);
                    translate([0, 0, Shroud_D / 2 + 4])
                        cube([Shroud_H - 2*House_Wall, Shroud_W - 2*House_Wall,
                              Shroud_D - 2*House_Wall], center=true);
                }

                // Fresnel lens dome cutout (front face)
                // 15.5mm circular hole allowing dome to protrude
                translate([0, 0, Shroud_D + 4])
                    cylinder(h=House_Wall2 + 2, d=Lens_Cutout, center=true, $fn=48);

                // Recessed shelf for PIR board (sits inside shroud)
                translate([0, 0, Shroud_D * 0.4 + 4])
                    difference() {
                        cube([PIR_Board_W + PIR_Clear, PIR_Board_H + PIR_Clear, 3], center=true);
                        // Center cutout (board sits on shelf edges)
                        translate([0, 0, 1.5])
                            cube([PIR_Board_W - 2, PIR_Board_H - 2, 3], center=true);
                    }

                // Wire channel
                translate([0, 0, -2])
                    cube([Sled_Wire_H, Sled_Wire_W, Shroud_D + 8], center=true);

                // ===== POTENTIOMETER ACCESS HOLES =====
                // Two 3mm holes on side wall for Sensitivity and Delay adjustment
                // Left side: Sensitivity pot
                translate([0, -Shroud_W/2 - 1, Shroud_D * 0.65 + 4])
                    rotate([90, 0, 0])
                        cylinder(h=House_Wall + 4, d=Pot_Dia, center=true, $fn=16);
                // Left side: Delay pot (offset from first)
                translate([0, -Shroud_W/2 - 1, Shroud_D * 0.45 + 4])
                    rotate([90, 0, 0])
                        cylinder(h=House_Wall + 4, d=Pot_Dia, center=true, $fn=16);
            }
        }
    }
}

// ==========================================
// RENDER
// ==========================================

housing_motion();

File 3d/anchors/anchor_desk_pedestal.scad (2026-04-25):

// ==========================================
// Xentient Framework - Anchor: Desk Pedestal Adapter
// Weighted wedge stand, 15° upward tilt, cable routing
// Per Framework §5
// ==========================================
// Component: Male cylinder (40mm dia) with cross-keys
//            Wedge-shaped base, 15° upward angle
//            Hollow routing channel for USB-C cable
// Material: PETG (structural) + weighted fill (sand/metal in base)
// Units: mm

$fn = 64;

// ==========================================
// ANCHOR DIMENSIONS (matching hub rear)
// ==========================================

Anchor_Dia   = 40.0;    // Male cylinder diameter
Anchor_Depth = 6.0;     // Insertion depth
Anchor_Key_W = 10.0;    // Anti-rotation key width

// Desk pedestal dimensions
Tilt_Angle   = 15;      // 15° upward angle for optimal viewing
Base_W       = 80.0;    // Base width (stable footprint)
Base_D       = 70.0;    // Base depth (front to back)
Base_H       = 25.0;    // Base height at rear (highest point)
Base_Min_H   = 10.0;    // Base height at front (lowest point)
Wall_T       = 2.5;     // Wall thickness

// Cable routing
Cable_D      = 8.0;     // USB-C cable diameter for routing channel

// Weight fill pocket (for sand/metal insert)
Weight_W     = 60.0;
Weight_D     = 50.0;
Weight_H     = 10.0;

// ==========================================
// MODULE: anchor_desk_pedestal()
// ==========================================

module anchor_desk_pedestal() {
    difference() {
        union() {
            // Male cylinder (plugs into hub rear)
            cylinder(h=Anchor_Depth, d=Anchor_Dia, $fn=64);

            // Anti-rotation cross-keys
            for (a = [0, 90]) {
                rotate([0, 0, a])
                    translate([0, -Anchor_Key_W/2, 0])
                        cube([Anchor_Dia/2 + 2, Anchor_Key_W, Anchor_Depth]);
            }

            // Wedge base (15° tilt)
            // Front is low, rear is high for upward viewing angle
            hull() {
                // Front face (low)
                translate([0, Base_D/2 - 10, Base_Min_H/2])
                    cube([Base_W, 2, Base_Min_H], center=true);
                // Rear face (high)
                translate([0, -Base_D/2 + 10, Base_H/2])
                    cube([Base_W, 2, Base_H], center=true);
            }

            // Draft taper on cylinder
            translate([0, 0, Anchor_Depth - 0.5])
                cylinder(h=1, d1=Anchor_Dia, d2=Anchor_Dia + 1.0, $fn=64);
        }

        // Hollow interior for weight fill
        translate([0, 0, Wall_T])
            hull() {
                translate([0, Base_D/2 - 12, Base_Min_H/2])
                    cube([Weight_W, 2, Base_Min_H - 2*Wall_T], center=true);
                translate([0, -Base_D/2 + 12, Base_H/2])
                    cube([Weight_W, 2, Base_H - 2*Wall_T], center=true);
            }

        // Weight fill access (bottom opening)
        translate([0, 0, -1])
            hull() {
                translate([0, Base_D/2 - 15, 0])
                    cube([Weight_W - 10, 2, 3], center=true);
                translate([0, -Base_D/2 + 15, 0])
                    cube([Weight_W - 10, 2, 3], center=true);
            }

        // Cable routing channel (from rear, through base, to anchor cylinder)
        // Channel follows the 15° tilt
        translate([0, 5, 0])
            rotate([Tilt_Angle, 0, 0]) {
                // Horizontal section under base
                translate([0, 0, -Base_Min_H/2])
                    cube([Cable_D + 2, Base_D + 10, Cable_D + 2], center=true);
                // Vertical section up to anchor
                translate([0, -Base_D/2 + 15, Base_H/2])
                    cylinder(h=Anchor_Depth + Base_H, d=Cable_D + 2, $fn=24);
            }

        // Anti-rotation keyway cutouts (matching hub grooves)
        // 1° draft on cylinder for wedge fit
    }
}

// ==========================================
// RENDER
// ==========================================

anchor_desk_pedestal();

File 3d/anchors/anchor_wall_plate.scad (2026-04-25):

// ==========================================
// Xentient Framework - Anchor: Wall Plate Adapter
// Plugs into Rear Universal Anchor (40mm circular recess)
// Per Framework §5
// ==========================================
// Component: Male cylinder (40mm dia) with cross-keys
//            Flares to 60×60mm flat plate with 4× M3 countersunk holes
// Material: PETG (structural)
// Units: mm

$fn = 64;

// ==========================================
// ANCHOR DIMENSIONS (matching hub rear)
// ==========================================

Anchor_Dia   = 40.0;    // Male cylinder diameter
Anchor_Depth = 6.0;     // Insertion depth into hub
Anchor_Key_W = 10.0;    // Anti-rotation cross-key width
Anchor_Key_H = Anchor_Depth;  // Key height matches depth

// Wall plate dimensions
Plate_W      = 60.0;    // Square plate width
Plate_T      = 6.0;     // Plate thickness
M3_CSK_Dia  = 6.5;     // M3 countersunk head diameter
M3_Hole_Dia = 3.2;     // M3 screw hole diameter
CSK_Depth   = 3.0;     // Countersink depth
Hole_Offset = 24.0;    // Hole offset from center (24mm = 48mm span)

// Wire routing
Wire_Hole_D = 15.0;    // Central wire routing hole diameter

// ==========================================
// MODULE: anchor_wall_plate()
// ==========================================

module anchor_wall_plate() {
    difference() {
        union() {
            // Male cylinder (plugs into hub rear)
            cylinder(h=Anchor_Depth, d=Anchor_Dia, $fn=64);

            // Anti-rotation cross-keys (2 perpendicular ridges)
            for (a = [0, 90]) {
                rotate([0, 0, a])
                    translate([0, -Anchor_Key_W/2, 0])
                        cube([Anchor_Dia/2 + 2, Anchor_Key_W, Anchor_Key_H]);
            }

            // Transition from cylinder to square plate
            hull() {
                cylinder(h=1, d=Anchor_Dia + 4, $fn=64);
                translate([0, 0, Plate_T])
                    cube([Plate_W, Plate_W, 1], center=true);
            }

            // Wall plate
            translate([0, 0, Plate_T / 2])
                cube([Plate_W, Plate_W, Plate_T], center=true);
        }

        // Anti-rotation keyways in hub (matching grooves)
        // These are cut from the cylinder — the hub has matching channels

        // Central wire routing hole (for USB power through drywall)
        translate([0, 0, -1])
            cylinder(h=Anchor_Depth + Plate_T + 2, d=Wire_Hole_D, $fn=32);

        // 4× M3 countersunk holes
        for (sx = [-1, 1], sy = [-1, 1]) {
            translate([sx * Hole_Offset, sy * Hole_Offset, 0]) {
                // Through hole
                translate([0, 0, -1])
                    cylinder(h=Anchor_Depth + Plate_T + 2, d=M3_Hole_Dia, $fn=24);
                // Countersink (on outer face)
                translate([0, 0, Plate_T - CSK_Depth])
                    cylinder(h=CSK_Depth + 1, d=M3_CSK_Dia, $fn=24);
            }
        }

        // Draft angle on cylinder for easier insertion
        // (1° taper on cylinder outer surface)
    }

    // 1° draft taper on cylinder (additive ridge at base for wedge fit)
    translate([0, 0, Anchor_Depth - 0.5])
        cylinder(h=1, d1=Anchor_Dia, d2=Anchor_Dia + 1.0, $fn=64);
}

// ==========================================
// RENDER
// ==========================================

anchor_wall_plate();

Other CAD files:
3d/caps/housing_climate.scad
3d/_archive/scad/anchors/anchor_desk_pedestal.scad
3d/_archive/scad/anchors/anchor_wall_plate.scad
3d/_archive/scad/caps/housing_climate.scad
3d/_archive/scad/caps/housing_display.scad
3d/_archive/scad/caps/housing_listen.scad
3d/_archive/scad/caps/housing_motion.scad
3d/_archive/scad/caps/housing_sight.scad
3d/_archive/scad/caps/housing_speak.scad
3d/_archive/scad/caps/sleds.scad
3d/_archive/scad/nodebase/interior/keyway_strips.scad
3d/_archive/scad/nodebase/interior/landing_pads.scad
3d/_archive/scad/nodebase/interior/rail_guides.scad
3d/_archive/scad/nodebase/interior/reference_markers.scad
3d/_archive/scad/nodebase/interior/zone_a_tray.scad
3d/_archive/scad/nodebase/interior/zone_b_plate.scad
3d/_archive/scad/nodebase/interior/zone_c_plate.scad
3d/_archive/scad/nodebase/v1.scad
3d/_archive/scad/nodebase/v2.scad
3d/_archive/scad/nodebase/v3.scad
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

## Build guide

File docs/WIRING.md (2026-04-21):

# Xentient — Wiring & Connections (Source of Truth)

> Live diagram of every wire, bus, and pin between the **Node Base** (ESP32-WROOM-32) and its 6 peripheral housings. Update this file BEFORE soldering or moving a wire. Firmware `peripherals.h` and the breadboard must match this doc, in that priority.
>
> **Status:** DRAFT — breadboard validation pending. Pin assignments marked `?` are unresolved.
> **Last edited:** 2026-04-19
> **Companion docs:** [HARDWARE.md](HARDWARE.md) (locked decisions), [CONTRACTS.md](CONTRACTS.md) (message schema)

---

## 1. System Overview

```mermaid
flowchart LR
  subgraph PWR["Power Path"]
    USB[USB-C 5V] --> TP[TP4056<br/>charger]
    TP --> BAT[18650 LiPo<br/>3.7V]
    BAT --> MT[MT3608<br/>boost]
    MT --> R5[5V rail]
    R5 --> LDO[3.3V LDO]
    LDO --> R3[3.3V rail]
  end

  subgraph NB["Node Base (ESP32-WROOM-32)"]
    ESP[ESP32]
    LCD["LCD 16x2<br/>PCF8574 @0x27<br/>(hardwired, not slide-in)"]
    ESP -- I2C --- LCD
  end

  subgraph DOCK["6 Slide-in Housings"]
    H1["Listen<br/>INMP441"]
    H2["Speak<br/>MAX98357A + 3W 8Ω"]
    H3["Climate<br/>BME280"]
    H4["Motion<br/>PIR HC-SR501"]
    H5["Sight<br/>ESP32-CAM"]
    H6["(reserved)"]
  end

  R3 --> ESP
  R3 --> H1
  R5 --> H2
  R3 --> H3
  R3 --> H4
  R3 --> H5
  R3 --> LCD

  ESP -- I2S --- H1
  ESP -- I2S --- H2
  ESP -- I2C --- H3
  ESP -- GPIO --- H4
  ESP -- UART --- H5
```

---

## 2. Housing → Bus → Connector Matrix

| Housing  | Component(s) | Bus | Voltage | JST | Notes |
|---|---|---|---|---|---|
| Listen | INMP441 | I2S (in) | 3.3V | 6-pin  | L/R pin → GND (mono left) |
| Speak | MAX98357A + 3W 8Ω speaker | I2S (out) | 5V | 6-pin  | Amp needs 5V for full SPL; logic 3.3V-tol  |
| Climate  | BME280 | I2C | 3.3V | 6-pin* | 6-pin JST soldered but only 4 used; CSB/SDO NC |
| Motion | PIR HC-SR501 | GPIO | 3.3V | 3-pin  | Standalone module; OUT = GPIO interrupt |
| Sight | ESP32-CAM (OV2640) | UART | 5V | 4-pin  | Must be flashed independently first |
| LCD | 16x2 + PCF8574 @0x27 | I2C | 3.3V | 4-pin  | **Hardwired to dock**, not a slide-in slot |

\* Climate housing: 6-pin JST physically present, but only VCC/GND/SDA/SCL are wired. CSB and SDO are left unconnected (SDO tied LOW on breakout = 0x76).

---

## 3. ESP32 GPIO Map (DRAFT — needs breadboard validation)

| Function | Pin | Direction | Goes to | Status |
|---|---|---|---|---|
| I2C SDA | GPIO21 | bidir | BME280, LCD | ✅ VALIDATED 2026-04-20 |
| I2C SCL | GPIO22 | out | BME280, LCD | ✅ VALIDATED 2026-04-20 |
| I2S BCLK | GPIO26 | out | INMP441 SCK, MAX98357 BCLK | ✅ VALIDATED 2026-04-20 |
| I2S LRCK / WS | GPIO25 | out | INMP441 WS, MAX98357 LRC | ✅ VALIDATED 2026-04-20 |
| I2S DIN (mic) | GPIO35 | in | INMP441 SD | ✅ VALIDATED 2026-04-20 — left ch, >>16 shift, peak ~2200 loud |
| I2S DOUT (amp)  | GPIO27 | out | MAX98357 DIN | ✅ resolved (was GPIO22 conflict) |
| PIR interrupt | GPIO13 | in | PIR OUT | ⏳ not yet tested |
| CAM UART TX | GPIO17 | out | ESP32-CAM RX (GPIO3) | ✅ VALIDATED 2026-04-21 — PONG RTT=1ms |
| CAM UART RX | GPIO16 | in | ESP32-CAM TX (GPIO1) | ✅ VALIDATED 2026-04-21 — PONG RTT=1ms |
| LCD | shared | - | I2C bus | ✅ |

### Open pin questions

1. ~~**I2S DOUT vs I2C SCL on GPIO22**~~ — **RESOLVED:** I2S DOUT moved to GPIO27. No conflict.
2. ~~**CAM on UART0**~~ — **RESOLVED:** Using UART2 (TX=GPIO17, RX=GPIO16). UART0 avoided — keeps USB-serial debug live during CAM operation.

---

## 4. I2C Bus Map

```mermaid
flowchart LR
  ESP[ESP32<br/>SDA=GPIO21 SCL=GPIO22]
  ESP --- BME[BME280<br/>0x76]
  ESP --- LCD[LCD PCF8574<br/>0x27]
```

| Address | Device | Housing | Notes |
|---|---|---|---|
| 0x27 | PCF8574 (LCD)  | dock | Hardwired |
| 0x76 | BME280 | Climate | SDO tied LOW = 0x76 |
| (0x77)  | BME280 alt | - | Avoid — keep SDO low |

Pull-ups: 4.7kΩ to 3.3V on SDA + SCL, mounted on the Node Base PCB (one set for the whole bus).

---

## 5. I2S Bus Map

Single I2S peripheral block on the ESP32 services BOTH the mic (in) and the amp (out) on shared BCLK/LRCK with separate data lines.

```mermaid
flowchart LR
  ESP["ESP32 I2S<br/>BCLK=26 LRCK=25"]
  MIC["INMP441<br/>SD → DIN=GPIO35"]
  AMP["MAX98357A<br/>DIN ← DOUT=GPIO27"]
  ESP -- BCLK,LRCK --- MIC
  ESP -- BCLK,LRCK --- AMP
  MIC -. "SD (in)"  .-> ESP
  ESP -. "DOUT (out)" .-> AMP
```

- Format: 16 kHz, 16-bit S16LE mono (per HARDWARE.md §B3).
- INMP441 L/R pin tied to GND → channel = LEFT.
- MAX98357 GAIN pin: leave floating (default 9 dB) for breadboard; tune later.

---

## 6. Module Wiring (per JST connector)

> Colors in **bold** are actually soldered; *italic* are recommended standard for unsoldered modules.

### Climate — BME280 (4-pin active, 6-pin JST soldered)

| Pin | Color | Signal | Module Pad | Notes |
|-----|---|---|---|---|
| 1 | **Red**  | VCC | VIN | 3.3V |
| 2 | **Black**| GND | GND | |
| 3 | **Yellow**| SDA | SDI/SDA | |
| 4 | **White**| SCL | SCK/SCL | |

Removed: SDO (was Yellow), CSB (was Blue) — SDO tied LOW on breakout = 0x76; CSB unused.

### Speak — MAX98357A (6-pin JST)

| Pin | Color | Signal | Module Pad | Notes |
|-----|---|---|---|---|
| 1 | **Yellow** | VCC | VIN | 5V for full SPL |
| 2 | **Black**  | GND | GND | |
| 3 | **Red** | BCLK | BCLK | |
| 4 | **Green**  | LRCK | LRC | |
| 5 | *Green* | DATA | DIN | **Not yet soldered** → GPIO27 |
| 6 | **White**  | GAIN | GAIN | Leave floating (default 9 dB)|

Speaker wires: **Red** (+), **Black** (−)

### Listen — INMP441 (6-pin JST, soldered)

| Pin | Color | Signal | Module Pad | Notes |
|-----|---|---|---|---|
| 1 | **Red** | VCC | VDD | 3.3V (VDD = VCC)  |
| 2 | **Black**  | GND | GND | |
| 3 | **Green**  | BCLK | SCK | |
| 4 | **White**  | LRCK | WS | |
| 5 | **Yellow** | DATA | SD | → GPIO35 |
| 6 | **Blue** | L/R | L/R | → GND (mono left)  |

### Motion — PIR HC-SR501 (3-pin JST, not yet soldered)

| Pin | Color | Signal | Notes |
|-----|---|---|---|
| 1 | *Red* | VCC | 3.3V–5V (PIR tolerant)|
| 2 | *Black*  | GND | |
| 3 | *White*  | OUT | → GPIO13 |

### Sight — ESP32-CAM (4-pin JST, not yet soldered)

| Pin | Color | Signal | Notes |
|-----|---|---|---|
| 1 | *Red* | VCC | 5V recommended for stability |
| 2 | *Black*  | GND | |
| 3 | *White*  | TX | ESP32-CAM TX → Node Base RX (GPIO16) |
| 4 | *Yellow* | RX | ESP32-CAM RX ← Node Base TX (GPIO17) |

### LCD — 16x2 PCF8574 (4-pin JST, not yet soldered)

| Pin | Color | Signal | Notes |
|-----|---|---|---|
| 1 | *Red* | VCC | 3.3V  |
| 2 | *Black*  | GND | |
| 3 | *White*  | SDA | |
| 4 | *Yellow* | SCL | |

---

## 7. Breadboard Validation Order

Per HARDWARE.md, build and prove on breadboard BEFORE designing the dock PCB:

1. **Power path** — TP4056 → 18650 → MT3608 → 5V → 3.3V LDO. Measure rails with multimeter.
2. **I2C bus** — BME280 + LCD on shared SDA/SCL. Run `Wire` scanner sketch, expect `0x27` and `0x76`. ✅ PASS 2026-04-20
3. **I2S mic** — INMP441 capture on GPIO35. Left channel confirmed, >>16 shift, peak ~2200 loud/~50 silence. ✅ PASS 2026-04-20
4. **PIR** — GPIO13 attachInterrupt, log motion events. Standalone 3-pin connector.
5. **ESP32-CAM** — flash independently first ✅, then connect via 4-wire UART2 (GPIO16/17). Run `cam_uart` validation sketch — expect PONG replies to PING.

Each step → tick the box and update the affected section above with the actually-wired pins. Diagram drift = bugs.

---

## 8. Change Log

- 2026-04-19 — Initial draft. Captured housing matrix, GPIO draft, flagged GPIO22 conflict and CAM UART0 concern as open questions.
- 2026-04-19 — Major restructure. Split "Sense" into standalone "Climate" (BME280) and "Motion" (PIR) modules. Resolved GPIO22 conflict: I2S DOUT moved to GPIO27. Added 3-pin GPIO connector spec. Updated ESP32-CAM notes (independent flash, 4-wire UART). 6 housings total (was 5).
- 2026-04-19 — Replaced generic JST pinout tables with per-module wiring tables showing actual soldered wire colors (Climate, Speak) and recommended standard colors (Listen, Motion, Sight, LCD). Flagged Speak DIN wire as not yet soldered.
- 2026-04-20 — 1xi VALIDATION PASS: I2C scanner confirmed LCD 0x27 + BME280 0x76. I2S mic read confirmed INMP441 on left channel (L/R=GND), >>16 shift correct. Calibrated: silence ~0.001 RMS / ~50 peak, normal speech ~0.02 RMS / ~1600 peak, loud/near ~0.04 RMS / ~2200 peak. VAD thresholds 1000/600 confirmed appropriate. Marked PIR as not yet tested.
- 2026-04-21 — UART2 decision locked: CAM uses GPIO17 (TX) / GPIO16 (RX). UART0 avoided to keep USB-serial debug live. Updated §3 GPIO map, §6 Sight table, §7 step 5. Added cam_uart validation sketch.
- 2026-04-21 — 02i VALIDATION PASS: UART2 link confirmed. Node Base GPIO16/17 ↔ ESP32-CAM GPIO1/3. PING/PONG RTT=1ms, 0% loss after CAM boot. ESP32-CAM MB used (direct USB, no FTDI).

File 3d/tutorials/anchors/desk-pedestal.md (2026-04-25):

# Desk Pedestal Anchor — SketchUp Tutorial

**Component:** Hub-to-Desk Mounting Adapter
**Socket:** Rear Universal Anchor (40mm diameter, 6mm deep)
**Print Count:** 1
**Material:** PETG

---

## What You're Building

A weighted wedge-shaped stand. Holds the hub at a 15° upward angle for optimal desk viewing and mic pickup. Features a hollow cable routing channel and a weight-fill pocket.

---

## Step 1: Male Cylinder

1. Draw a 40mm diameter circle
2. Push/Pull 6mm tall
3. Add anti-rotation cross-keys (same as wall plate: 3mm × 2mm channels)
4. Group as `Cylinder-DeskPed`

## Step 2: Wedge Base

1. On the cylinder's rear face, draw a trapezoidal wedge profile:
   - Bottom edge: 80mm wide
   - Top edge: 40mm (matches cylinder diameter)
   - Height: 70mm (depth of the base from front to back)
   - The wedge angle creates a 15° upward tilt when the hub is mounted
2. Use **Push/Pull** or **Follow Me** to create the 3D wedge
3. Shell to 3mm walls (structural anchor plane requires 3mm minimum)
4. Group as `Wedge-DeskPed`

## Step 3: 15° Tilt Verification

1. Use the **Protractor** tool to verify the top surface is at 15° from horizontal
2. When the hub is mounted, the front face should tilt 15° upward
3. This optimizes: LCD viewing angle, PIR detection zone, mic pickup pattern

## Step 4: Cable Routing Channel

Through the center of the wedge:
1. Draw a 13mm diameter channel (8mm cable channel + 2.5mm wall each side, increased from original 8mm per audit)
2. Route from the cylinder base to the wedge rear bottom
3. Push/Pull through the wedge body (subtractive cutout)
4. USB-C cable feeds through this channel

## Step 5: Weight Fill Pocket

At the bottom of the wedge:
1. Draw a rectangular pocket: 60mm × 50mm × 15mm deep
2. Push/Pull to carve into the wedge bottom
3. This pocket is filled with sand, BBs, or a metal plate for stability
4. The added weight prevents the hub from tipping forward
5. Add a slide-in cover or use tape to seal the pocket after filling

## Step 6: Anti-Slip Feet

On the wedge bottom (outside the fill pocket):
1. Add 4× small rubber foot recesses (8mm diameter × 2mm deep)
2. After printing, glue rubber bumpers into these recesses
3. Prevents the pedestal from sliding on smooth desk surfaces

## Step 7: Union & Export

1. Select `Cylinder-DeskPed` and `Wedge-DeskPed`
2. Solid Tools → Union
3. Run Solid Inspector²
4. Export as `anchor_desk_pedestal.stl`

---

## Assembly Checklist

- [ ] Male cylinder seats in hub rear anchor (40mm × 6mm)
- [ ] Cross-keys engage anti-rotation channels
- [ ] Weight fill pocket loaded with sand/BBs/metal
- [ ] Fill pocket sealed (tape or slide cover)
- [ ] USB-C cable routed through internal channel
- [ ] Hub angled 15° upward for optimal viewing/mic pickup
- [ ] Anti-slip feet installed on bottom

---

## Weight Fill Recommendations

| Material | Approx. Weight | Notes |
|---|---|---|
| Sand | ~150g (fills pocket) | Cheap, easy to pour |
| Steel BBs | ~200g | Denser, rattles slightly |
| Metal plate | ~250g | Heaviest, no rattle — best stability |
| Unused PETG scraps | ~100g | Free, but lighter than alternatives |

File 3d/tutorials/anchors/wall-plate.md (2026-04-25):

# Wall Plate Anchor — SketchUp Tutorial

**Component:** Hub-to-Wall Mounting Adapter
**Socket:** Rear Universal Anchor (40mm diameter, 6mm deep)
**Print Count:** 1
**Material:** PETG

---

## What You're Building

A 40mm male cylinder with anti-rotation cross-keys that fits the hub's rear anchor pocket. It flares out to a 60×60mm flat plate with 4× M3 countersunk holes for wall mounting. Central 15mm hole for optional USB-C cable routing through drywall.

---

## Step 1: Male Cylinder

1. Draw a 40mm diameter circle (matches hub anchor pocket)
2. Push/Pull 6mm tall (matches pocket depth)
3. Add anti-rotation cross-keys:
   - Draw 2 perpendicular rectangular channels on the cylinder exterior (3mm wide × 2mm deep)
   - These engage matching channels in the hub anchor pocket
   - Use Push/Pull to carve them into the cylinder wall
4. Group as `Cylinder-WallPlate`

## Step 2: Transition Flange

1. On the cylinder's rear face, draw a 60×60mm square centered on the cylinder
2. Connect the cylinder edge to the square corners with the **Line** tool
3. This creates 4 triangular transition faces
4. Push/Pull the square profile 6mm rearward (total plate thickness = 6mm at center, tapering to 4mm at edges)
5. Group as `Flange-WallPlate`

## Step 3: M3 Mounting Holes

On the plate face:
1. Draw 4× M3 countersunk holes at the plate corners (3.2mm body + 6mm countersink head)
2. Position: 10mm inset from each corner (50×50mm bolt pattern)
3. Push/Pull through the plate (cutout)
4. For the countersink: draw a 6mm circle on the outer face, then chamfer it to the 3.2mm hole

## Step 4: Central Cable Hole (Optional)

1. Draw a 15mm diameter circle at the plate center
2. Push/Pull through the plate and cylinder (cutout)
3. This allows routing the USB-C power cable through the drywall directly to the hub

## Step 5: Union & Export

1. Select `Cylinder-WallPlate` and `Flange-WallPlate`
2. Solid Tools → Union
3. Run Solid Inspector²
4. Export as `anchor_wall_plate.stl`

---

## Assembly Checklist

- [ ] Male cylinder seats fully in hub rear anchor (40mm × 6mm)
- [ ] Cross-keys engage anti-rotation channels in hub
- [ ] 4× M3 screws into wall anchors
- [ ] USB-C cable routed through 15mm center hole (if routing through drywall)
- [ ] Plate sits flush against wall surface

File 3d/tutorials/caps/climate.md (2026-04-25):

# Climate Cap — SketchUp Tutorial

**Component:** BME280 Breakout (13×10mm) + 100nF decoupling cap
**Connection:** 6-pin JST XH (I2C: VCC, GND, SDA, SCL, NC, NC — 4 active + 2 NC)
**Socket Position:** 150° (away from heat sources)
**Print Count:** 1
**Material:** PETG (recommended) or PLA

---

## What You're Building

A standoff vented box that extends at least 15mm from the hub face before housing the sensor. The BME280 must be far from hub heat (ESP32, battery, amp). Heavily louvered sides for maximum passive airflow.

---

## Step 1: Male Sled Base

1. Draw 23.6mm × 15.6mm rectangle
2. Push/Pull 10mm deep
3. Apply 1° draft on outer walls
4. Subtract 18×8mm wire channel
5. Add +3mm flange per side
6. Group as `Sled-Climate`

## Step 2: Standoff Neck (15mm Minimum)

The 15mm standoff is **MANDATORY** — the BME280 must be away from hub heat:

1. On the sled front face, draw a rectangle matching sled outer dimensions (23.6mm × 15.6mm)
2. Push/Pull forward 15mm (minimum standoff length)
3. This creates a hollow neck connecting sled to the sensor housing
4. Maintain the 18×8mm wire channel continuity through the neck
5. Group as `Neck-Climate`

## Step 3: Sensor Housing Box

At the end of the neck:
1. Draw a box: 25mm wide × 20mm tall × 15mm deep (enough room for BME280 + air circulation)
2. Push/Pull 15mm deep
3. Shell to 1.5mm wall thickness (Solid Subtract)
4. Group as `Box-Climate`

## Step 4: Louvered Gills (4-Sided Ventilation)

This is the most important feature — maximum passive airflow for accurate readings:

On each of the 4 side faces:
1. Draw 4 horizontal slits per face
2. Each slit: 2mm tall × (face-width - 4mm) wide (2mm margin on each side)
3. Space slits evenly (roughly 4mm center-to-center)
4. Push/Pull each slit through the wall (cutout)
5. Chamfer top and bottom edges of each slit at 45°

**Total:** 4 faces × 4 slits = 16 ventilation openings

## Step 5: Internal BME280 Shelf

Inside the housing:
1. Draw a 13mm × 10mm rectangular shelf (matching BME280 PCB)
2. Push/Pull 1mm down from the top — the BME280 sits on this shelf
3. Position the shelf so the sensor faces outward (toward the front opening)
4. Leave at least 5mm clearance between sensor and front wall for airflow

## Step 6: Union & Export

1. Select `Sled-Climate`, `Neck-Climate`, `Box-Climate`
2. Solid Tools → Union
3. Run Solid Inspector²
4. Export as `housing_climate.stl`

---

## Assembly Checklist

- [ ] BME280 board seated on internal shelf, sensor facing outward
- [ ] 6-pin JST pigtail (4 active: VCC, GND, SDA, SCL + 2 NC)
- [ ] 100nF decoupling cap on VCC line
- [ ] Verify I2C address **0x76** (per validation bead 1xi)
- [ ] 15mm standoff intact — sensor is NOT near hub body
- [ ] All 16 gill slits unobstructed
- [ ] No supports needed for print (horizontal slits print cleanly at 0.2mm layer height)

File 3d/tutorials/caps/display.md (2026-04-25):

# Display Cap — SketchUp Tutorial

**Component:** LCD 16×2 + PCF8574 Backpack (71×26×15mm)
**Connection:** 4-pin JST XH (I2C: VCC, GND, SDA, SCL)
**Socket Position:** CENTER FRONT (dedicated — not a side port)
**Print Count:** 1 (housing) + 1 (backplate)
**Material:** PETG or PLA

---

## What You're Building

A flared monitor housing. The base is the standard 24×16mm sled, which rapidly flares outward to a 75×30mm rectangular bezel. The LCD sits behind an exact window, mounted on M3 standoffs, with a snap-fit backplate.

---

## Step 1: Male Sled Base

1. Draw 23.6mm × 15.6mm rectangle
2. Push/Pull 10mm deep
3. Apply 1° draft on outer walls
4. Subtract 18×8mm wire channel
5. Add +3mm flange per side
6. Group as `Sled-Display`

**Note:** This is the CENTER FRONT socket, which is vertically oriented. The sled inserts upward (Z-axis) rather than at an angle like the side ports.

## Step 2: Flared Transition

The housing must expand from 23.6×15.6mm (sled) to 75×30mm (bezel):

1. On the sled front face, draw the target bezel: 75mm wide × 30mm tall
2. Connect the sled corners to the bezel corners with the **Line** tool
3. This creates 4 trapezoidal transition faces
4. The flare extends ~18mm forward from the sled
5. Use **Push/Pull** or **Follow Me** to create the solid volume
6. Shell to 2mm walls
7. Group as `Flare-Display`

## Step 3: LCD Window

On the front bezel face:
1. Draw a rectangle: 71mm × 27mm (matches LCD visible area exactly — the 26mm height + 1mm tolerance for the glass)
2. Push/Pull through the front wall (cutout)
3. This creates the viewing window — the LCD glass sits just behind this opening

## Step 4: Internal M3 Standoffs

Inside the housing, mount the LCD + PCF8574 backpack:
1. Add 4× M3 standoff cylinders (5mm boss, 4.2mm hole)
2. Position at corners matching the LCD backpack mounting holes
3. Standoff height: positions the LCD glass flush with the front window (or 0.5mm behind for protection)
4. The PCF8574 backpack sits behind the LCD — both share the same standoffs

## Step 5: Snap-Fit Backplate

The backplate encloses the rear of the housing:

1. Draw a 75mm × 30mm rectangle (matches bezel outer dimensions)
2. Push/Pull 2mm thick (thin plate)
3. Add snap-fit features:
   - 4× small tabs on the top and bottom edges (1mm × 3mm, protruding 1mm inward)
   - These snap into corresponding slots on the housing interior
4. Add a small rectangular opening (~5mm × 5mm) for LCD contrast potentiometer access
5. Group as `Backplate-Display`
6. Export as a **separate** STL: `housing_display_backplate.stl`

## Step 6: Snap-Fit Slots on Housing

On the housing interior (where the backplate meets):
1. Draw 4× rectangular slots matching the backplate tab positions
2. Each slot: 1.2mm × 3.2mm (0.2mm clearance on each side)
3. Push/Pull 1.5mm deep into the housing wall
4. The backplate tabs click into these slots

## Step 7: Union & Export

1. Select `Sled-Display` and `Flare-Display`
2. Solid Tools → Union
3. Run Solid Inspector²
4. Export housing as `housing_display.stl`
5. Export backplate separately as `housing_display_backplate.stl`

---

## Assembly Checklist

- [ ] LCD + PCF8574 backpack mounted on M3 standoffs inside housing
- [ ] LCD glass aligned with front window (71×27mm opening)
- [ ] 4-pin JST pigtail (I2C: VCC, GND, SDA, SCL)
- [ ] Verify I2C address (0x27 default for PCF8574)
- [ ] Snap-fit backplate clicks into place
- [ ] LCD contrast pot accessible through backplate opening
- [ ] Cap plugs into CENTER FRONT socket only (not a side port)

---

## SketchUp Tips for Flared Shapes

- The rapid flare (24mm → 75mm) can create thin walls at the transition point — verify minimum 2mm thickness throughout
- Use **Section Plane** tool to inspect internal geometry at various depths
- The snap-fit tabs are small features — zoom in to 1mm precision when drawing them
- Test the snap-fit by printing just the backplate and housing rim before the full print

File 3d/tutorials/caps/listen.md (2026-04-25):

# Listen Cap — SketchUp Tutorial

**Component:** INMP441 MEMS Microphone (8×8mm PCB)
**Connection:** 6-pin JST XH (I2S: VCC, GND, WS, SCK, SD, L/R)
**Socket Position:** 270° (opposite speaker, avoids feedback)
**Print Count:** 1
**Material:** PETG (recommended) or PLA

---

## What You're Building

A low-profile dome housing extending ~10mm from the sled, with a 3×3 pinhole array on the front face for acoustic transparency and an internal slot for the INMP441 PCB.

---

## Step 1: Male Sled Base

1. Draw 23.6mm × 15.6mm rectangle (0.4mm clearance in 24.0×16.0mm socket)
2. Push/Pull 10mm deep
3. Apply 1° draft on outer walls: Move top edges inward ~0.17mm per side
4. Subtract 18×8mm wire channel from center (Push/Pull through)
5. Add +3mm flange on each side (total width 29.6mm) that sits flush against hub exterior
6. Group as `Sled-Listen`

## Step 2: Dome Body

1. On the sled front face, draw the dome profile: start at sled width (23.6mm), extend ~10mm forward
2. Use **Arc** tool (`A`) to draw a gentle dome curve from the top of the sled face to ~10mm forward
3. **Push/Pull** the dome profile to match sled height (15.6mm)
4. **Follow Me** tool: Select the dome face path, then use Follow Me to sweep the dome shape — OR manually draw the dome as a half-cylinder with filleted top
5. Group as `Dome-Listen`

## Step 3: Pinhole Array

On the dome front face:
1. Draw a 3×3 grid of 1mm diameter circles
2. Space them 4mm apart (center-to-center)
3. Push/Pull each circle through the dome wall (cutout)
4. These allow sound to reach the MEMS mic while protecting the PCB

## Step 4: Internal PCB Slot

Inside the dome:
1. Draw an 8mm × 8mm rectangle (INMP441 PCB size)
2. Push/Pull to create a slot 1mm deep — the PCB slides in horizontally
3. Add a 0.5mm retaining lip on the top edge (Line tool, Push/Pull 0.5mm) to keep the PCB from falling out

## Step 5: Wire Routing

1. The 18×8mm wire channel from the sled must connect to the PCB slot interior
2. Verify the channel is continuous from the sled rear to the PCB slot
3. The 6-pin JST connector must pass through this channel during assembly

## Step 6: Union & Export

1. Select `Sled-Listen` and `Dome-Listen`
2. Use **Solid Tools → Union** to merge into one solid
3. Run **Solid Inspector²** — fix any leaks
4. Export as `housing_listen.stl` (binary, mm)

---

## Assembly Checklist

- [ ] INMP441 board slides into internal slot
- [ ] 6-pin JST pigtail routed through wire channel
- [ ] L/R select pin configured: **GND = left channel** (per validation bead 1xi)
- [ ] 100nF decoupling cap soldered on VCC line
- [ ] Pinholes face outward (away from hub body)
- [ ] Mic orientation: sound enters through pinholes → MEMS diaphragm

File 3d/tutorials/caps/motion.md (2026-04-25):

# Motion Cap — SketchUp Tutorial

**Component:** HC-SR501 PIR (23×23mm board, 15mm dome)
**Connection:** 4-pin JST XH (VCC, GND, OUT, NC — 3 active + 1 NC)
**Socket Position:** 210° (human detection height)
**Print Count:** 1
**Material:** PETG or PLA

---

## What You're Building

A recessed shroud housing the PIR sensor. The Fresnel lens dome protrudes through a 15.5mm circular front cutout. Two 3mm side holes allow screwdriver access to the potentiometers without disassembly.

---

## Step 1: Male Sled Base

1. Draw 23.6mm × 15.6mm rectangle
2. Push/Pull 10mm deep
3. Apply 1° draft on outer walls
4. Subtract 18×8mm wire channel
5. Add +3mm flange per side
6. Group as `Sled-Motion`

## Step 2: Shroud Body

1. On the sled front face, draw a rectangle slightly larger than the PIR board: 25mm × 25mm
2. Push/Pull forward ~18mm (enough to enclose the 23mm board + 15mm dome)
3. Shell to 1.5mm walls (Solid Subtract)
4. The interior should be a recessed pocket that the PIR board sits inside
5. Group as `Shroud-Motion`

## Step 3: Fresnel Lens Cutout

On the front face:
1. Draw a 15.5mm diameter circle (matches the Fresnel dome exactly)
2. Push/Pull through the front wall (cutout)
3. The PIR dome protrudes slightly through this hole when assembled

## Step 4: PIR Board Shelf

Inside the shroud:
1. Draw a 23mm × 23mm shelf (matching the PIR board)
2. Position it so the Fresnel dome aligns with the front cutout when the board is seated
3. The dome center should be at the front face — the dome protrudes ~0.5mm past the face
4. Add 0.5mm retaining clips on the shelf corners to hold the board in place

## Step 5: Potentiometer Access Holes

On one side face of the shroud:
1. Draw 2× circles, each 3mm diameter
2. Position them to align with the two potentiometers on the HC-SR501:
   - **Sensitivity trimmer** (left side of PIR board)
   - **Time-delay trimmer** (right side of PIR board)
3. Push/Pull through the wall (cutout)
4. These allow a small jeweler's screwdriver to reach the trimmers without removing the cap

## Step 6: Wire Routing

1. Verify the 18×8mm wire channel connects from sled rear to the PIR board shelf
2. The 4-pin JST pigtail (VCC, GND, OUT, NC) passes through this channel

## Step 7: Union & Export

1. Select `Sled-Motion` and `Shroud-Motion`
2. Solid Tools → Union
3. Run Solid Inspector²
4. Export as `housing_motion.stl`

---

## Assembly Checklist

- [ ] HC-SR501 board seated in recessed shelf
- [ ] Fresnel lens dome protrudes through 15.5mm cutout
- [ ] 4-pin JST pigtail (3 active: VCC, GND, OUT + 1 NC — 3-pin JST not in BOM)
- [ ] Potentiometer access holes aligned with PIR trimmers
- [ ] Test screwdriver access through side holes
- [ ] **FIRMWARE TODO:** PIR not wired yet (bead 2ux pending — GPIO13 interrupt)

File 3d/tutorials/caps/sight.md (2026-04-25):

# Sight Cap — SketchUp Tutorial

**Component:** ESP32-CAM-MB Dual-Board (40×27mm)
**Connection:** 4-pin JST XH (UART: VCC, GND, TX, RX)
**Socket Position:** 30° (high visibility, clear line of sight)
**Print Count:** 2 (socket side + camera head — separate prints)
**Material:** PETG (mandatory — ESP32-CAM generates heat)

---

## What You're Building

An articulated camera head using a ball joint. The sled side holds the socket; the camera head holds the ball. This allows manual aiming (~25° range) after plugging in. Two-part print.

---

## Part 1: Socket Side (Sled + Ball Socket)

### Step 1: Male Sled Base

1. Draw 23.6mm × 15.6mm rectangle
2. Push/Pull 10mm deep
3. Apply 1° draft on outer walls
4. Subtract 18×8mm wire channel
5. Add +3mm flange per side
6. Group as `Sled-Sight`

### Step 2: Ball Socket Housing

On the sled front face:
1. Draw a cylinder extending ~8mm forward
2. At the front of this cylinder, carve a spherical socket:
   - Sphere diameter: ~15mm (matches the ball on the head)
   - Socket depth: ~8mm (half-sphere concavity)
3. Use **Arc** tool to draw the concave profile, then **Follow Me** to sweep it
4. Add a circular lip (1mm rim) around the socket opening to retain the ball
5. Group as `Socket-Sight`

### Step 3: Union Part 1

1. Select `Sled-Sight` and `Socket-Sight`
2. Solid Tools → Union
3. Solid Inspector²
4. Export as `housing_sight_socket.stl`

---

## Part 2: Camera Head (Ball + Lens Housing)

### Step 1: Ball Joint

1. Draw a sphere: 15mm diameter (matches socket concavity)
2. This sphere clicks into the socket and allows rotation
3. Print the ball at slightly reduced size (14.8mm) for smooth rotation, OR sand to fit

### Step 2: Camera Housing

On the ball's forward face:
1. Draw a rectangular box: 42mm wide × 29mm tall × 15mm deep (fits 40×27mm ESP32-CAM board)
2. Shell to 1.5mm walls
3. On the front face, draw a 15.5mm diameter circle for the OV2640 lens cutout
4. Push/Pull through (cutout)
5. The lens protrudes slightly through this opening

### Step 3: Antenna Wall (CRITICAL)

The ESP32-CAM has an onboard WiFi antenna trace. The wall near the antenna MUST be <1.5mm:

1. Identify which end of the housing has the antenna (typically the end opposite the lens)
2. Measure wall thickness: must be ≤1.5mm in the antenna zone
3. If the wall is too thick, use Push/Pull to thin it from inside
4. Mark this zone with a guide line so you don't accidentally thicken it during cleanup

### Step 4: Board Mounting

Inside the housing:
1. Add 2× M2 standoff positions matching the ESP32-CAM mounting holes (2.4mm holes)
2. Board sits with lens aligned to front cutout
3. USB port on the ESP32-CAM-MB should face the ball joint side (for programming access if needed)

### Step 5: Wire Exit

1. Route wires from the ESP32-CAM through the ball joint center and into the socket
2. This means drilling a 4mm hole through the ball center after printing
3. OR model the hole in SketchUp: draw a 4mm circle on the ball rear face, Push/Pull through

### Step 6: Union Part 2

1. Select ball and camera housing
2. Solid Tools → Union
3. Solid Inspector²
4. Export as `housing_sight_head.stl`

---

## Assembly Checklist

- [ ] Socket side printed and plugged into hub 30° socket
- [ ] Camera head printed separately
- [ ] Ball joint clicks into socket — test rotation range (~25°)
- [ ] ESP32-CAM board mounted with 2× M2 screws
- [ ] 4-pin JST pigtail (UART2: VCC, GND, GPIO2, GPIO12)
- [ ] OV2640 lens centered in front cutout
- [ ] Antenna wall ≤1.5mm thick (verify with calipers)
- [ ] UART2 wiring: ESP-CAM GPIO2 → NodeBase GPIO16, GPIO12 → GPIO17
- [ ] Wire routed through ball joint center hole

---

## SketchUip Tips for Ball Joints

- The ball-socket fit must be tight enough to hold position but loose enough to adjust by hand
- **Test print** the ball and socket first at 100% scale before committing to the full housing
- If the ball is too tight: sand the ball or scale the socket to 101%
- If the ball is too loose: add a thin shim or scale the socket to 99%
- The 1mm lip around the socket opening is what retains the ball — don't skip it

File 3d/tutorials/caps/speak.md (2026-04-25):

# Speak Cap — SketchUp Tutorial

**Component:** MAX98357A (7×7mm) + 3W 8Ω Speaker (40mm diameter)
**Connection:** 6-pin JST XH (I2S: VCC, GND, DIN, BCLK, LRC, GAIN)
**Socket Position:** 90° (near USB-C, ventilation access)
**Print Count:** 1
**Material:** PETG (mandatory — amp generates heat)

---

## What You're Building

A heavy trapezoidal housing with asymmetric flare. The 40mm speaker is wider than the 24mm sled, so the housing must flare outward. Includes a thermal divider between the MAX98357A amp and the speaker magnet.

---

## Step 1: Male Sled Base

1. Draw 23.6mm × 15.6mm rectangle
2. Push/Pull 10mm deep
3. Apply 1° draft on outer walls
4. Subtract 18×8mm wire channel
5. Add +3mm flange per side
6. Group as `Sled-Speak`

## Step 2: Trapezoidal Flare

The housing must expand from 23.6mm (sled width) to at least 44mm (40mm speaker + 2mm wall each side):

1. On the sled front face, draw a 44mm wide × 40mm tall trapezoid
   - Bottom matches sled: 23.6mm
   - Top flares to: 44mm
   - Height: ~22mm (speaker depth + wall)
2. The flare is **asymmetric** — offset 3mm to one side to avoid blocking neighboring caps
3. Use **Line** tool to draw the trapezoid profile
4. **Push/Pull** the profile to the housing depth (~22mm)
5. Shell to 2mm wall thickness (Solid Subtract method)
6. Group as `Body-Speak`

## Step 3: Speaker Grille

On the front face of the housing:
1. Draw a 40mm diameter circle (speaker size)
2. Inside, draw a radial grille pattern:
   - 4–6 concentric rings (1mm thick, 2mm gap between)
   - OR horizontal bars (1mm wide, 2mm apart)
3. Push/Pull the open areas through the front wall (cutout)
4. Keep 2mm minimum wall between grille openings

## Step 4: Thermal Divider

This is critical — the MAX98357A generates heat that must not transfer to the speaker magnet:

1. Inside the housing, draw a horizontal shelf/wall dividing the interior into two chambers:
   - **Rear chamber** (near sled): MAX98357A amp zone, ~7mm tall
   - **Front chamber** (near grille): Speaker zone, ~33mm deep
2. The divider is a 2mm thick horizontal plate spanning the full width
3. Add ventilation openings on the divider: 2× 4mm diameter holes for wire pass-through + airflow

## Step 5: Amp Zone Details

In the rear chamber:
1. Draw 7×7mm pocket for MAX98357A (Push/Pull 2mm deep)
2. Add wire routing channel connecting to the 18×8mm sled channel

## Step 6: Ventilation

Top and bottom vents for amp heat dissipation:
1. Draw 3 horizontal slits (2mm wide) on the top face above the amp zone
2. Push/Pull through (cutout)
3. Repeat on the bottom face
4. Chamfer slit edges at 45°

## Step 7: Union & Export

1. Select `Sled-Speak` and `Body-Speak`
2. Solid Tools → Union
3. Run Solid Inspector²
4. Export as `housing_speak.stl`

---

## Assembly Checklist

- [ ] MAX98357A placed behind thermal divider in amp zone
- [ ] 40mm speaker seated in front cutout, grille facing out
- [ ] 6-pin JST pigtail routed through wire channel
- [ ] GAIN pin configured (SD_MODE: pull VCC = 15W, GND = mute, float = 9dB)
- [ ] Thermal divider intact — no direct contact between amp IC and speaker magnet
- [ ] Ventilation slits unobstructed
- [ ] Asymmetric offset positions housing away from neighboring caps

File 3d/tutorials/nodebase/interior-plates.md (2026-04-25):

# NodeBase Interior Plates — SketchUp Tutorial

**Components:** Rail Guides, Keyway Strips, Landing Pads, Reference Markers, Zone A/B/C Plates
**Print Count:** 6+3+4+10+1+1+1 = 26 prints total
**Material:** PETG

---

## Overview

All interior components are **separate prints** that glue into the NodeBase shell. The shell provides reference positions; you print and stick these in place.

Two assembly paths:
- **Path A:** Print plates, slide into rail guides, screw onto bosses
- **Path B:** Skip plates, glue physical standoffs onto landing pads

---

## Rail Guide Strips (6 prints)

### Dimensions
- Width: 3.5mm
- Height: 2mm (protrudes from wall)
- Length: 9mm (Z=3 to Z=12, collar zone only)

### SketchUp Steps
1. Draw 3.5mm × 2mm rectangle
2. Push/Pull 9mm long
3. Add 1° draft on the long edges (Move tool: offset top edge ~0.08mm per side)
4. Group as `Rail-Guide`, make Component
5. Export 6 copies

### Glue Position
- Inner wall at each hex vertex: 0°, 60°, 120°, 180°, 240°, 300°
- Z=3 to Z=12 (collar zone only, where wall is ≥3mm thick)
- Scuff wall, apply cyanoacrylate, press flat back of guide against wall

---

## Keyway Strips (3 prints)

### Dimensions
- Width: 3mm
- Height: 1.5mm (protrudes from wall)
- Length: 84mm (Z=3 to Z=87, full interior height)

### SketchUp Steps
1. Draw 3mm × 1.5mm rectangle
2. Push/Pull 84mm
3. Group as `Keyway-Strip`, make Component
4. Export 3 copies

### Glue Position
- Inner wall at 0°, 120°, 240°
- Full interior height Z=3 to Z=87
- These are subtractive grooves conceptually — the strip creates a ridge that plates notch around

---

## Landing Pads (4 prints, Path B only)

### Dimensions
- Diameter: 8mm
- Thickness: 0.5mm raised disc

### SketchUp Steps
1. Draw 8mm diameter circle
2. Push/Pull 0.5mm thick
3. Group as `Landing-Pad`, make Component
4. Export 4 copies

### Glue Position
- (±57, ±37) at Z=20 on inner cavity wall
- These are glue targets for physical M3 standoffs (Zone B master board)
- Scuff pad back + wall with 120-grit, apply cyanoacrylate, seat standoff on top

---

## Reference Markers (10 prints)

### Dimensions
- Diameter: 1.5mm
- Depth: 0.5mm (subtractive pit — modeled as a bump for drilling reference)

### SketchUp Steps
1. Draw 1.5mm diameter circle
2. Push/Pull 0.5mm
3. Group as `Ref-Marker`, make Component
4. Export 10 copies

### Positions

| Zone | Count | Coordinates (X, Y, Z) | Marks |
|---|---|---|---|
| A | 3 | (0, -25, 3), (15, 30, 3), (-15, 30, 3) | Battery center, TP4056, MT3608 |
| B | 4 | (±57, ±37, 20) | Master board M3 standoff corners |
| C | 3 | (±11, 42, 45), (0, 18, 45) | ESP32 M2 standoff positions |

---

## Zone A Tray (1 print)

### Dimensions
- Fits within hex F2F at Z=3 (≈142mm)
- 2mm thick hex-shaped plate
- Central 30×30mm wire chimney cutout
- Notches around port sleeve intrusions

### Contains
- 18650 battery clip-in pocket (~78×22×19mm)
- TP4056 clip pocket (25×19mm)
- MT3608 clip pocket (37×22mm)
- LDO clip pocket (12×8mm)
- Wire chimney (30×30mm)

### SketchUp Steps
1. Draw a hex plate matching the inner F2F at Z=3 (≈142mm)
2. Push/Pull 2mm thick
3. Subtract 30×30mm central chimney (Push/Pull through)
4. Subtract notches where port sleeves intrude (measure from shell interior)
5. Add clip-in pockets on top surface for each component (Push/Pull downward, add retaining lips with Line tool)
6. Group as `Zone-A-Tray`

### Mount
- Slides into rail guide channels at Z=3
- OR glue directly to floor with cyanoacrylate
- Secure with M3×6 screws into bosses (Path A)

---

## Zone B Plate (1 print)

### Dimensions
- 120×80mm with 15mm chamfered corners (must clear hex apothem at Z=20)
- Fits within hex F2F at Z=20 (≈133mm)
- 2mm thick with honeycomb infill pattern
- Central 30×30mm wire chimney
- 4× M3 standoff positions (110×70mm span)

### SketchUp Steps
1. Draw 120×80mm rectangle
2. Chamfer all 4 corners at 15mm (Line tool to cut corners at 45°)
3. Push/Pull 2mm thick
4. Subtract 30×30mm central chimney
5. Subtract notches for port sleeves
6. Draw honeycomb infill pattern (hexagonal holes) across non-structural areas
7. Add 4× M3 standoff cylinders (5mm boss, 4.2mm hole) at (±55, ±35)
8. Group as `Zone-B-Plate`

### Mount
- Slides into rail guides at Z=20 (Path A)
- OR rests on glued standoffs at landing pads (Path B)
- Secure with M3×8 screws

---

## Zone C Plate (1 print)

### Dimensions
- Fits within hex F2F at Z=45 (≈106mm)
- ESP32 mount: 22×48mm standoff span
- 2mm thick with honeycomb infill
- Central 30×30mm wire chimney
- Anti-rotation nub

### SketchUp Steps
1. Draw plate to fit Z=45 inner hex (≈106mm F2F)
2. Push/Pull 2mm thick
3. Subtract 30×30mm chimney
4. Add 4× M2 standoff cylinders (4mm boss, 2.4mm hole) at positions matching ESP32 dev board (55×28mm board, 22×48mm span)
5. Add anti-rotation nub (small 2×2×2mm cube) to prevent board from rotating
6. Add honeycomb infill cutouts
7. Group as `Zone-C-Plate`

### Mount
- Slides into rail guides at Z=45
- OR rests on glued M2 standoffs at Zone C reference marker positions
- Secure with M2×6 screws

---

## Export Checklist

Before exporting each plate:
1. Run **Solid Inspector²** — must be solid
2. Verify dimensions with **Tape Measure** (`T`)
3. Export as STL (binary, mm units)
4. Name files descriptively: `zone_a_tray.stl`, `zone_b_plate.stl`, etc.

---

## Glue Quick Reference

| Adhesive | Use For | Prep | Cure | Notes |
|---|---|---|---|---|
| Cyanoacrylate | Landing pads, rail guides, keyways | Scuff both surfaces with 120-grit | 30s | Strongest for PETG+PETG |
| Hot glue | Temporary holds, wire tacking | Clean surface | 60s | Removable, softens >80°C |
| PETG cement | Permanent bonds only | Clean surface | 24h | Weld-On 3, irreversible |

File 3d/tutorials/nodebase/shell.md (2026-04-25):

# NodeBase Shell — SketchUp Tutorial

**Component:** Main Hub Shell (Truncated Hex-Pyramid)
**Print Count:** 1
**Material:** PETG (mandatory)
**Estimated Print Time:** 8–12 hours

---

## What You're Building

A hollow truncated hex-pyramid with 7 port pockets, ventilation gills, a USB-C cutout, a rear anchor pocket, collar ribs, and breakout PCB flanges. Nothing else is in this print — all interior features are separate prints.

---

## Step 1: Base Hexagon

1. Select **Polygon** tool (shortcut: `C` then type `6s` for 6 sides)
2. Click origin, drag outward, type `86.6mm` for radius — this gives 150mm flat-to-flat
3. Immediately **Push/Pull** upward: type `12mm` — this is the collar (straight section)
4. Triple-click → **Make Group** → rename to `NodeBase-Collar`

## Step 2: Front Hexagon (Top of Pyramid)

1. On the top face of the collar, draw another 6-sided polygon
2. Radius: `34.6mm` — this gives 60mm flat-to-flat
3. Do NOT extrude yet — this is just the target profile

## Step 3: Connect the Taper

1. Use the **Line** tool (`L`) to connect each vertex of the small hex to the corresponding vertex on the large hex
2. This creates 6 trapezoidal faces
3. Delete the top face of the small hex (it will be open)
4. Select all taper geometry → **Make Group** → rename to `NodeBase-Taper`
5. Verify with **Solid Inspector²** — must show "Solid"

## Step 4: Shell the Solid (3mm Walls)

**Method A — Solid Subtract (recommended):**
1. Copy the entire outer shell
2. Scale the copy down uniformly: subtract 3mm from each dimension (or model inner profile manually using F2F reduced by 6mm)
3. Use **Solid Tools → Subtract** (outer minus inner) to hollow the shell
4. Check with Solid Inspector²

**Method B — Manual Push/Pull:**
1. Enter the group (double-click)
2. Push/Pull each inner face inward by 3mm
3. Connect all inner faces to form a closed inner cavity
4. Verify solid

## Step 5: Port Pockets (7x)

For each port face (6 sides + 1 front center):

1. **Draw the pocket rectangle** on the outer face: 24.4mm wide × 16.4mm tall
2. **Push/Pull inward** 10mm — this creates the pocket
3. **Draw the sleeve behind the pocket:** On the pocket floor, draw a 24.0mm × 16.0mm rectangle (the inner sleeve opening)
4. **Push/Pull the sleeve** inward another 10mm through the 3mm wall — this creates the internal sleeve tube
5. **Draw the wire channel:** 18mm wide × 8mm tall rectangle on the sleeve floor, Push/Pull through to the interior

**Port positions by face angle:**
- 30° = Sight (side 1)
- 90° = Speak (side 2)
- 150° = Climate (side 3)
- 210° = Motion (side 4)
- 270° = Listen (side 5)
- 330° = Reserved (side 6)
- Front center = Display

**Tip:** Create one pocket+sleeve as a Component named `Port-Pocket`, then copy and rotate to each face using **Rotate** tool (`Q`). The front center pocket is vertical, not angled.

## Step 6: Breakout PCB Flange

Around each port sleeve interior:
1. Draw a 2mm flange extending outward from the sleeve perimeter
2. Add 2× M2 mounting holes (2.4mm diameter) on opposite sides of the flange
3. Group as `Flange-[port-name]`

## Step 7: USB-C Cutout

1. On the 90° collar face (same face as Speak port, but in the collar zone)
2. Draw 12mm × 6mm rectangle
3. Push/Pull through the wall (cutout)
4. Add 1mm floor overcut below the cutout (extends 1mm below rectangle) for thick cable plug housings

## Step 8: Ventilation Gills

On 3 alternating faces (0°, 120°, 240° — between port faces):
1. Draw 4 horizontal slits per face, each 2mm wide
2. Space them evenly across the face height
3. Chamfer top and bottom edges at 45° using the **Move** tool on slit edges
4. Push/Pull through the wall (cutout)
5. Repeat for collar zone and mid-body zone (2 rows)

## Step 9: Rear Anchor Pocket

1. On the rear (bottom) face, draw a circle: radius 20mm (40mm diameter)
2. Push/Pull inward 6mm
3. Add 2 perpendicular cross-key channels (3mm wide × 2mm deep) across the pocket floor for anti-rotation

## Step 10: Collar Aesthetic Ribs

On the collar exterior at 0°, 60°, 120°, 180°, 240°, 300°:
1. Draw a 2mm wide × 1mm tall rectangular profile along the collar height
2. Push/Pull outward 0.5mm from the face
3. These are purely decorative — they break up the flat collar surface

## Step 11: Final Checks

1. Run **Solid Inspector²** — fix all leaks and internal faces
2. Verify all pocket dimensions with the **Tape Measure** tool (`T`)
3. Verify wall thickness is 3mm minimum (Tape Measure inner-to-outer face)
4. Export as STL: Right-click group → **Export STL** (binary, mm)
5. Open in slicer — verify dimensions match before printing

---

## Common SketchUp Gotchas

- **Flipped normals:** If faces appear dark/gray, right-click → **Reverse Faces**. All outward-facing surfaces should be white.
- **Internal faces:** After Solid Subtract, delete any leftover internal partition faces. Solid Inspector² catches these.
- **Coplanar edges:** SketchUp sometimes leaves extra edges on coplanar faces. Use **Erase** (`E`) to clean them — they confuse slicers.
- **Export units:** Always verify STL export units are millimeters. SketchUp sometimes defaults to inches.

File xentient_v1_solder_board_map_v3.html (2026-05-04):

# Xentient V1 — Solder Board Map

42 × 30 holes · 2.54 mm pitch · v5 — 10k Speaker Resistor + 5V LCD fix — click any zone to trace wires

⟳ Flip Board ▶ Back Side (solder)

Board: 42 × 30 holes
Pitch: 2.54 mm

██ Row 0 — GND rail (top)
██ Row 29 — GND rail (bottom)
██ Row 1 — 5 V rail
██ Row 2 — 3.3 V rail

Click a coloured zone to highlight
its wires and bus endpoints.
Use ⟳ Flip to switch Top/Back view. ▋ awaiting selection

Hide wires

Power zone

ESP32 DevKit

JST connectors

LCD header

Cap/Battery

Resistor

E-Cap

GND bus rail

5 V rail

3.3 V rail

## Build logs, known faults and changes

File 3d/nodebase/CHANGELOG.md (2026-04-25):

# Xentient NodeBase V3.1 — Update Log

**Date:** 2026-04-25  
**Changes from V3 → V3.1**

---

## Restored Shell Features (V3.1)

The following features were stripped from V3 to create a "clean atrium" shell, but are **required** for assembly and have been added back in V3.1:

### 1. Rail Slots (6× at hex vertices)
- **Spec:** 3.5mm wide × 2mm deep grooves at each hex vertex (0°, 60°, 120°, 180°, 240°, 300°)
- **Zone:** Collar only (Z=3 to Z=12) where wall is ≥3mm thick
- **Purpose:** Path A plates slide into these for angular alignment
- **Implementation:** Subtractive cuts into inner wall surface

### 2. Alignment Keyways (3×)
- **Spec:** 1.6mm wide × 1.6mm deep grooves at 0°, 120°, 240°
- **Zone:** Full depth (Z=Shell_T to Z=Total_Depth-Shell_T)
- **Purpose:** Angular orientation for all plates, regardless of assembly path
- **Implementation:** Subtractive grooves on inner cavity wall

### 3. Reference Pits (Zone A/B/C)
- **Spec:** 0.5mm deep × 1.5mm diameter subtractive dimples
- **Zone A:** Battery holder center (0, -25), TP4056 (15, 30), MT3608 (-15, 30) — all at Z=3
- **Zone B:** Master board standoff coordinates (±57, ±37) at Z=2
- **Zone C:** ESP32 standoff coordinates (±11, ±24) at Z=45
- **Purpose:** Easier to locate with drill bit or glue tip than additive bumps
- **Implementation:** Subtractive cylinders on inner wall surface

### 4. Landing Pads (Zone B, Path B)
- **Spec:** 8mm diameter × 0.5mm raised circles at Zone B standoff coordinates
- **Location:** (±57, ±37) at Z=20, projected onto inner hex wall
- **Purpose:** Flat glue surfaces for physical M3 standoffs (Path B builders)
- **Implementation:** Additive cylinders on inner cavity wall

---

## Still Separate Modules (NOT in shell)

These remain as separate .scad files:

| Module | File | Why Separate |
|---|---|---|
| Zone A tray | `zone_a_tray.scad` | Clip-in battery/power module pockets |
| Zone B plate | `zone_b_plate.scad` | 120×80mm board mount, needs flat surface |
| Zone C plate | `zone_c_tray.scad` | ESP32 board mount |
| Display cap | `caps/housing_display.scad` | Separate cap per §4 |
| All 6 peripheral caps | `caps/housing_*.scad` | Plug into side sockets |
| Both anchors | `anchors/anchor_*.scad` | Plug into rear anchor |

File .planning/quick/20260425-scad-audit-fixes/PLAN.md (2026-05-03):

---
status: planning
created: 2026-04-25
priority: critical
---

# Quick Task: Fix 10 SCAD Inconsistencies from Cross-Reference Audit

Cross-referencing SPEC-v3.md, SPEC-caps.md, and all .scad files revealed 10
issues. Three are CRITICAL showstoppers that will prevent parts from fitting.

## Tasks (ordered by severity)

### CRITICAL (showstoppers — parts won't fit or function)

1. **Anchor draft taper won't fit hub pocket**
   - Files: `3d/anchors/anchor_wall_plate.scad`, `3d/anchors/anchor_desk_pedestal.scad`
   - Both add a +1mm draft taper (40→41mm) at the cylinder tip
   - Hub `rear_anchor_negative()` is a straight 40mm cylinder with no taper
   - Fix: Remove the additive taper ring from both anchors (the `cylinder(h=1, d1=40, d2=41)` block)

2. **Speak thermal divider is a cutout, not a wall**
   - File: `3d/caps/housing_speak.scad`
   - Thermal divider `cube([Flare_W+10, Div_Wall_T, Flare_Depth*0.3])` is inside `difference()`
   - This creates a gap CONNECTING amp zone to speaker zone (opposite of thermal isolation)
   - Fix: Move thermal divider from difference() to an additive union() block within the housing body. The divider must be a solid wall separating two chambers.

3. **Listen pinholes face sideways instead of outward**
   - File: `3d/caps/housing_listen.scad`
   - Pinholes use `rotate([0, 90, 0])` drilling along X axis (sideways)
   - MEMS mic needs sound from the FRONT face (outward, Z direction)
   - Fix: Change pinhole rotation to drill through the front face. Remove the rotate or use a rotation that creates holes perpendicular to the housing's front surface.

### HIGH (functional issues)

4. **Front center pocket has no draft angle**
   - File: `3d/nodebase/v3.scad`
   - `front_port_negative()` uses plain `cube()` — no 1° draft angle
   - Side pockets use `hull()` with 1° draft for wedge-fit insertion
   - Fix: Add draft angle to front pocket matching `socket_pocket_negative()` pattern

5. **Marginal flange bearing surface**
   - File: `3d/caps/sleds.scad`
   - Default flange +2mm gives only 1.6mm bearing per side
   - Fix: Increase default `flange_w` and `flange_h` from 2.0 to 3.0 in `male_sled_with_flange()`

6. **Desk pedestal cable channel size mismatch**
   - File: `3d/anchors/anchor_desk_pedestal.scad`
   - Hub rear anchor has 15mm wire hole; pedestal uses 10mm (Cable_D+2)
   - Fix: Increase Cable_D from 8.0 to 13.0 so channel matches hub's 15mm hole (13+2=15)

### MEDIUM (documentation / cleanup)

7. **Dead code in v3.scad**
   - File: `3d/nodebase/v3.scad`
   - Modules `battery_cradle()`, `power_module_clip()`, `master_board_standoffs()`, `esp32_standoffs()`, `lcd_standoffs()` are defined but never called
   - Per SPEC-v3.md, interior features are separate prints
   - Fix: Remove these unused modules and their parameter blocks

8. **Document 3mm flange on speak/display in SPEC-caps.md**
   - File: `3d/caps/SPEC-caps.md`
   - Speak and Display use `flange_w=3.0, flange_h=3.0` instead of standard 2.0
   - Fix: Add note to SPEC-caps.md Universal Sled section documenting the +3mm flange for larger caps

9. **Camera antenna thin-wall geometry may create zero material**
   - File: `3d/caps/housing_sight.scad`
   - The offset cube in antenna zone difference() may cut away all material on the outer face
   - Fix: Adjust the antenna zone geometry so the thin wall is exactly Ant_Wall=1.2mm thick on the outer face

10. **Spec split note** — not a code fix, just awareness that SPEC-v3.md and SPEC-caps.md should be cross-referenced. No file change needed.

## Files Modified

- `3d/anchors/anchor_wall_plate.scad`
- `3d/anchors/anchor_desk_pedestal.scad`
- `3d/caps/housing_speak.scad`
- `3d/caps/housing_listen.scad`
- `3d/nodebase/v3.scad`
- `3d/caps/sleds.scad`
- `3d/caps/SPEC-caps.md`
- `3d/caps/housing_sight.scad`

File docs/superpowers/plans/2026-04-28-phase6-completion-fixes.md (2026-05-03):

# Phase 6 Completion Fixes Implementation Plan

> **For agentic workers:** REQUIRED SUB-SKILL: Use superpowers:subagent-driven-development (recommended) or superpowers:executing-plans to implement this plan task-by-task. Steps use checkbox (`- [ ]`) syntax for tracking.

**Goal:** Fix 3 low-severity issues from the Phase 6 completion audit: ROADMAP checkbox updates, test mock `transition()` method, and STATE/ROADMAP alignment.

**Architecture:** Three small, independent fixes — two documentation updates and one test mock fix. No production code changes.

**Tech Stack:** Vitest, TypeScript, Markdown

---

## File Structure

| File | Action | Responsibility |
|---|---|---|
| `.planning/ROADMAP.md` | Modify | Mark 06-03/04/05 complete, update progress table |
| `harness/tests/skill-executor.test.ts` | Modify | Add `transition` to `mockModeManager` |
| `harness/tests/space-manager.test.ts` | Modify | Add `transition` to `mockModeManager` |
| `.planning/STATE.md` | Modify | No changes needed — already correct |

---

### Task 1: Fix test mocks — add `transition()` method

**Files:**
- Modify: `harness/tests/skill-executor.test.ts:17-23`
- Modify: `harness/tests/space-manager.test.ts:7`

- [ ] **Step 1: Add `transition` to `mockModeManager` in skill-executor.test.ts**

In `harness/tests/skill-executor.test.ts`, change the `mockModeManager` object (lines 17-23) from:

```typescript
const mockModeManager = {
  getMode: vi.fn(() => 'listen'),
  setMode: vi.fn(),
  on: vi.fn(),
  clearIdleTimer: vi.fn(),
  handleModeCommand: vi.fn(),
  handleSensorEvent: vi.fn(),
};
```

to:

```typescript
const mockModeManager = {
  getMode: vi.fn(() => 'listen'),
  setMode: vi.fn(),
  transition: vi.fn(() => true),
  on: vi.fn(),
  clearIdleTimer: vi.fn(),
  handleModeCommand: vi.fn(),
  handleSensorEvent: vi.fn(),
};
```

- [ ] **Step 2: Add `transition` to `mockModeManager` in space-manager.test.ts**

In `harness/tests/space-manager.test.ts`, change line 7 from:

```typescript
const mockModeManager = { getMode: vi.fn(() => 'listen'), setMode: vi.fn(), on: vi.fn(), clearIdleTimer: vi.fn() };
```

to:

```typescript
const mockModeManager = { getMode: vi.fn(() => 'listen'), setMode: vi.fn(), transition: vi.fn(() => true), on: vi.fn(), clearIdleTimer: vi.fn() };
```

- [ ] **Step 3: Run tests to verify no regressions and no noisy errors**

Run: `cd harness && npx vitest run`
Expected: All 26 tests pass. No `TypeError: transition is not a function` errors in output.

- [ ] **Step 4: Commit test fix**

```bash
git add harness/tests/skill-executor.test.ts harness/tests/space-manager.test.ts
git commit -m "fix: add transition() to test mocks to match ModeManager API"
```

---

### Task 2: Update ROADMAP.md — mark Phase 6 plans complete

**Files:**
- Modify: `.planning/ROADMAP.md`

- [ ] **Step 1: Mark 06-03, 06-04, 06-05 as complete**

In `.planning/ROADMAP.md`, find these lines in the Phase 6 section:

```
- [ ] 06-03: SpaceManager + 8 MCP skill management tools (register/update/disable/remove/list/log/switch_mode/resolve_conflict)
- [ ] 06-04: Wire SpaceManager into `core.ts` — default Space, MQTT forwarding, SSE relay
- [ ] 06-05: Vitest tests for SkillLog, SkillExecutor, SpaceManager
```

Change them to:

```
- [x] 06-03: SpaceManager + 8 MCP skill management tools (register/update/disable/remove/list/log/switch_mode/resolve_conflict)
- [x] 06-04: Wire SpaceManager into `core.ts` — default Space, MQTT forwarding, SSE relay
- [x] 06-05: Vitest tests for SkillLog, SkillExecutor, SpaceManager
```

- [ ] **Step 2: Update progress table**

Find the progress table row for Phase 6:

```
| 6. Xentient Layers | 2/5 | In progress | 06-01, 06-02 |
```

Change to:

```
| 6. Xentient Layers | 5/5 | Complete | 06-01 through 06-05 |
```

- [ ] **Step 3: Update the last-updated line**

Find:

```
*Last updated: 2026-04-28 — Demo scope reduced (breadboard prototype, no casing). Phase 5 complete. Phase 6 Waves 1-2 done. Beads aligned.*
```

Change to:

```
*Last updated: 2026-04-28 — Phase 6 complete (all 5 waves). Demo scope reduced (breadboard prototype, no casing).*
```

- [ ] **Step 4: Commit ROADMAP update**

```bash
git add .planning/ROADMAP.md
git commit -m "docs: mark Phase 6 plans 06-03/04/05 complete, update progress table"
```

---

### Task 3: Verify STATE.md and ROADMAP.md alignment

**Files:**
- Read-only: `.planning/STATE.md`
- Read-only: `.planning/ROADMAP.md`

- [ ] **Step 1: Confirm STATE.md already says Phase 6 complete**

Read `.planning/STATE.md` and verify it contains `Phase 6 complete` or equivalent language. No changes needed — STATE.md is already correct.

- [ ] **Step 2: Confirm ROADMAP.md now agrees with STATE.md**

After Task 2 edits, both files should say Phase 6 is complete. No additional changes needed.

---

### Task 4: Push and close

- [ ] **Step 1: Push all commits to remote**

```bash
git pull --rebase
git push
```

- [ ] **Step 2: Close any related beads**

```bash
bd list --status=in_progress
# Close any Phase 6 related beads
bd close <id> --reason="Phase 6 completion audit fixes done"
```

- [ ] **Step 3: Verify clean state**

```bash
git status
bd dolt push
```

Expected: Working tree clean, remote up to date.

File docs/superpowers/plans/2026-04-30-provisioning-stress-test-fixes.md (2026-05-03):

# ESP32 WiFiManager + NVS Provisioning Stress-Test Fixes

> **For agentic workers:** REQUIRED SUB-SKILL: Use superpowers:subagent-driven-development (recommended) or superpowers:executing-plans to implement this plan task-by-task. Steps use checkbox (`- [ ]`) syntax for tracking.

**Goal:** Fix all 12 scenario gaps identified in the WiFiManager + NVS provisioning stress test, prioritizing the demo happy path (S12) and the critical MQTT topic resolution bug (S10).

**Architecture:** Three-layer fix strategy: (1) Firmware runtime topic resolution — replace compile-time `{nodeId}` strings with runtime-resolved nodeId from NVS config; (2) WiFiManager lifecycle hardening — fix factory reset, portal timeout, and dead WiFi creds in NVS; (3) Harness node-connect detection — add MQTT birth message so harness knows when ESP32 connects.

**Tech Stack:** ESP32 Arduino (Preferences.h, WiFiManager, PubSubClient), TypeScript (Harness MqttClient, SpaceManager)

---

## Scenario Audit Results

| # | Scenario | Verdict | Root Cause | Priority |
|---|---|---|---|---|
| S1 | Fresh boot happy path | Partially works | Portal pre-fills compile-time defaults on empty device | MEDIUM |
| S2 | Normal reboot with NVS | Works | WiFiManager reconnects from its own storage, NVS for extended config | — |
| S3 | JSON vs portal WiFi conflict | Broken | NVS WiFi creds never used for connection; WiFiManager has its own store | HIGH |
| S4 | Factory reset via BOOT | Partially works | Clears NVS but not WiFiManager's WiFi store | HIGH |
| S5 | Harness restart before ESP32 connects | Broken | No dynamic node registration; hardcoded Space in core.ts | MEDIUM |
| S6 | ESP32 MQTT connect detection | Broken | No birth message or confirmNode; profile_ack only after profile_set | CRITICAL |
| S7 | Portal timeout (180s) | Works but fragile | Infinite restart loop; no deep sleep fallback | LOW |
| S8 | Malformed JSON | Partially works | Parse error falls back OK; partial JSON succeeds but may leave gaps | LOW |
| S9 | MCP tool vs REST endpoint | N/A | Neither implemented yet | MEDIUM |
| S10 | MQTT {nodeId} topic resolution | **CRITICAL BUG** | Firmware subscribes to literal `xentient/node/{nodeId}/profile/set`; harness publishes to resolved `xentient/node/node-01/profile/set` — they NEVER match | **CRITICAL** |
| S11 | cleanupStale removes active token | N/A | NodeProvisioner not implemented | LOW |
| S12 | Demo happy path minimum fixes | Blocked by S10, S6, S4 | — | **CRITICAL** |

---

## File Structure

### Firmware (modified)
- Modify: `firmware/src/mqtt_client.cpp` — runtime topic resolution using nodeId from provisioning config
- Modify: `firmware/include/mqtt_client.h` — add `mqtt_init()` signature change to accept nodeId
- Modify: `firmware/src/main.cpp` — pass nodeId from ProvisioningConfig to mqtt_init
- Modify: `firmware/shared/messages.h` — remove `{nodeId}` from topic constants, add template helper
- Modify: `firmware/src/provisioning.cpp` — add WiFiManager WiFi erase in `provisioning_clear()`, fix dead NVS WiFi creds

### Harness (modified)
- Modify: `harness/src/comms/MqttClient.ts` — emit `nodeBirth` on firmware connect message
- Modify: `harness/src/engine/SpaceManager.ts` — handle `nodeBirth` → transition node to active
- Modify: `harness/src/core.ts` — wire `nodeBirth` event

### Tests (new/modified)
- Create: `firmware/tests/test_topic_resolution.cpp` — PlatformIO unit test for topic string building
- Modify: `harness/tests/mcp-integration.test.ts` — add nodeBirth detection test

---

## Task 1: [CRITICAL] Fix MQTT Topic Resolution — Replace `{nodeId}` with Runtime Value

**The #1 demo blocker.** Firmware subscribes to the literal string `xentient/node/{nodeId}/profile/set` instead of resolving `{nodeId}` to the actual nodeId from NVS. Harness publishes to `xentient/node/node-01/profile/set`. They never match, so profile hot-swap is completely broken.

**Files:**
- Modify: `firmware/shared/messages.h:110-111`
- Modify: `firmware/src/mqtt_client.cpp:43-45, 185, 289`
- Modify: `firmware/include/mqtt_client.h:12`
- Modify: `firmware/src/main.cpp:358`

- [ ] **Step 1: Add runtime topic builder in messages.h**

Replace the static `TOPIC_NODE_PROFILE_SET` and `TOPIC_NODE_PROFILE_ACK` with template strings and a builder function. Keep the template strings for documentation but add a runtime builder.

In `firmware/shared/messages.h`, replace lines 110-111:

```cpp
// --- MQTT topics for NodeProfile hot-swap ---
// NOTE: {nodeId} MUST be resolved at runtime. These are template strings,
// NOT subscribe/publish targets. Use buildNodeTopic() to get the resolved topic.
static constexpr const char* TOPIC_NODE_PROFILE_SET_TPL = "xentient/node/{nodeId}/profile/set";
static constexpr const char* TOPIC_NODE_PROFILE_ACK_TPL = "xentient/node/{nodeId}/profile/ack";
static constexpr const char* TOPIC_NODE_PROFILE_SET_BASE = "xentient/node/";
static constexpr const char* TOPIC_NODE_PROFILE_SET_SUFFIX = "/profile/set";
static constexpr const char* TOPIC_NODE_PROFILE_ACK_SUFFIX = "/profile/ack";

// Build a resolved topic string: "xentient/node/<nodeId>/profile/set" or "/ack"
// buf must be at least 64 bytes. Returns pointer to buf.
char* buildNodeTopic(const char* nodeId, const char* suffix, char* buf, size_t bufLen);
```

- [ ] **Step 2: Implement buildNodeTopic() in a new small source file**

Create `firmware/src/topic_builder.cpp`:

```cpp
#include <Arduino.h>
#include "messages.h"
#include <cstdio>

char* buildNodeTopic(const char* nodeId, const char* suffix, char* buf, size_t bufLen) {
    snprintf(buf, bufLen, "xentient/node/%s%s", nodeId, suffix);
    return buf;
}
```

- [ ] **Step 3: Modify mqtt_client.cpp to accept nodeId and resolve topics at runtime**

Add a static `nodeId` storage in `mqtt_client.cpp` and resolve topics at init time.

Replace the static topic strings with runtime-resolved ones. In `firmware/src/mqtt_client.cpp`:

After the existing static variables (around line 11), add:

```cpp
// --- Runtime-resolved nodeId for topic building ---
static char runtimeNodeId[24] = NODE_BASE_ID;
static char resolvedTopicProfileSet[64] = {0};
static char resolvedTopicProfileAck[64] = {0};
```

Modify `mqtt_init()` to accept and store nodeId:

```cpp
void mqtt_init(const char* brokerHost, uint16_t brokerPort, const char* nodeId) {
    strncpy(mqttBrokerHost, brokerHost, sizeof(mqttBrokerHost) - 1);
    mqttBrokerHost[sizeof(mqttBrokerHost) - 1] = '\0';
    mqttBrokerPort = brokerPort;
    if (nodeId) {
        strncpy(runtimeNodeId, nodeId, sizeof(runtimeNodeId) - 1);
        runtimeNodeId[sizeof(runtimeNodeId) - 1] = '\0';
    }
    // Resolve nodeId-dependent topics at runtime
    buildNodeTopic(runtimeNodeId, TOPIC_NODE_PROFILE_SET_SUFFIX, resolvedTopicProfileSet, sizeof(resolvedTopicProfileSet));
    buildNodeTopic(runtimeNodeId, TOPIC_NODE_PROFILE_ACK_SUFFIX, resolvedTopicProfileAck, sizeof(resolvedTopicProfileAck));
    client.setServer(mqttBrokerHost, mqttBrokerPort);
    client.setCallback(mqtt_callback);
    mqtt_connect();
}
```

Replace all references to `TOPIC_NODE_PROFILE_SET` with `resolvedTopicProfileSet`:

In `mqtt_connect()` (line 45):
```cpp
    mqtt_subscribe(resolvedTopicProfileSet);
```

In `mqtt_callback()` (line 185):
```cpp
    if (strcmp(topic, resolvedTopicProfileSet) == 0) {
```

In `send_profile_ack()` (line 289):
```cpp
    mqtt_publish(resolvedTopicProfileAck, buf, strlen(buf));
```

- [ ] **Step 4: Update mqtt_client.h signature**

In `firmware/include/mqtt_client.h`, change:
```cpp
void mqtt_init(const char* brokerHost, uint16_t brokerPort);
```
to:
```cpp
void mqtt_init(const char* brokerHost, uint16_t brokerPort, const char* nodeId = nullptr);
```

- [ ] **Step 5: Update main.cpp to pass nodeId**

In `firmware/src/main.cpp`, change the `mqtt_init()` call from:
```cpp
    mqtt_init(cfg.mqttHost, cfg.mqttPort);
```
to:
```cpp
    mqtt_init(cfg.mqttHost, cfg.mqttPort, cfg.nodeId);
```

- [ ] **Step 6: Verify build compiles**

Run: `cd firmware && pio run -e node_base`
Expected: Build succeeds with no errors

- [ ] **Step 7: Commit**

```bash
git add firmware/shared/messages.h firmware/src/topic_builder.cpp firmware/src/mqtt_client.cpp firmware/include/mqtt_client.h firmware/src/main.cpp
git commit -m "fix(firmware): resolve {nodeId} in MQTT topics at runtime — profile hot-swap was broken"
```

---

## Task 2: [CRITICAL] Add MQTT Birth Message for Node-Connect Detection

**S6 fix.** Currently the harness has no way to know when an ESP32 connects to MQTT. Profile ack only fires after a profile_set command. Add a birth message that the firmware publishes on first MQTT connect, so the harness can transition the node from "dormant" to "connected".

**Files:**
- Modify: `firmware/shared/messages.h` — add birth topic + message type
- Modify: `firmware/src/mqtt_client.cpp` — publish birth message on connect
- Modify: `harness/src/comms/MqttClient.ts` — emit `nodeBirth` event
- Modify: `harness/src/engine/SpaceManager.ts` — handle nodeBirth
- Modify: `harness/src/core.ts` — wire nodeBirth event

- [ ] **Step 1: Add birth message constants in messages.h**

In `firmware/shared/messages.h`, after the NodeProfile section:

```cpp
// --- Node birth message (published on first MQTT connect) ---
static constexpr const char* TOPIC_NODE_BIRTH = "xentient/node/{nodeId}/birth";
static constexpr const char* TOPIC_NODE_BIRTH_SUFFIX = "/birth";
// Message: { v:1, type:"node_birth", nodeId:"node-01", timestamp:ms }
```

- [ ] **Step 2: Publish birth message in mqtt_connect()**

In `firmware/src/mqtt_client.cpp`, add a static `resolvedTopicBirth` and publish in `mqtt_connect()`:

Add alongside other static resolved topics:
```cpp
static char resolvedTopicBirth[64] = {0};
```

In `mqtt_init()`, after the `buildNodeTopic` calls:
```cpp
    buildNodeTopic(runtimeNodeId, TOPIC_NODE_BIRTH_SUFFIX, resolvedTopicBirth, sizeof(resolvedTopicBirth));
```

In `mqtt_connect()`, after `Serial.println("[MQTT] Connected.")`:
```cpp
        // Publish birth message so harness knows this node is online
        JsonDocument birthDoc;
        birthDoc["v"]        = MSG_VERSION;
        birthDoc["type"]     = "node_birth";
        birthDoc["nodeId"]   = runtimeNodeId;
        birthDoc["timestamp"] = (uint32_t)millis();
        char birthBuf[128];
        serializeJson(birthDoc, birthBuf, sizeof(birthBuf));
        mqtt_publish(resolvedTopicBirth, birthBuf, strlen(birthBuf));
        Serial.printf("[MQTT] Birth message published for node '%s'\n", runtimeNodeId);
```

- [ ] **Step 3: Handle nodeBirth in harness MqttClient.ts**

In `harness/src/comms/MqttClient.ts`, add the `xentient/node/+/birth` subscription and emit:

In the `connect` handler's subscribe list, add:
```typescript
        'xentient/node/+/birth',
```

In `handleMessage()`, add a new branch:
```typescript
      } else if (topic.startsWith('xentient/node/') && topic.endsWith('/birth')) {
        this.emit('nodeBirth', data);
      }
```

Note: This must come BEFORE the generic `topic.startsWith('xentient/node/')` catch at the end of the chain, so reorder accordingly. Actually, looking at the current code, the `profile/ack` handler already uses `startsWith('xentient/node/') && topic.endsWith('/profile/ack')`. The birth handler should use similar pattern. Update the existing `profile/ack` check to also handle `/birth`:

```typescript
      } else if (topic.startsWith('xentient/node/')) {
        if (topic.endsWith('/profile/ack')) {
          this.emit('nodeProfileAck', data);
        } else if (topic.endsWith('/birth')) {
          this.emit('nodeBirth', data);
        } else {
          logger.warn({ topic }, 'Unhandled node topic');
        }
      }
```

- [ ] **Step 4: Handle nodeBirth in SpaceManager.ts**

In `harness/src/engine/SpaceManager.ts`, add:

```typescript
  /** Handle firmware birth message — node is online and ready */
  onNodeBirth(nodeId: string): void {
    for (const [, space] of this.spaces) {
      const node = space.nodes.find(n => n.nodeId === nodeId);
      if (node) {
        if (node.state === 'dormant') {
          node.state = 'running';
          logger.info({ nodeId }, 'Node birth received — transitioning to running');
          // Push default profile to newly connected node
          this.pushDefaultProfile(node);
        }
        break;
      }
    }
  }
```

- [ ] **Step 5: Wire nodeBirth in core.ts**

In `harness/src/core.ts`, after the existing `nodeProfileAck` wiring:

```typescript
  mqtt.on('nodeBirth', (data: { nodeId: string }) => {
    spaceManager.onNodeBirth(data.nodeId);
  });
```

- [ ] **Step 6: Commit**

```bash
git add firmware/shared/messages.h firmware/src/mqtt_client.cpp harness/src/comms/MqttClient.ts harness/src/engine/SpaceManager.ts harness/src/core.ts
git commit -m "feat: add MQTT node birth message for connect detection (S6)"
```

---

## Task 3: [HIGH] Fix Factory Reset — Clear WiFiManager WiFi Creds

**S4 fix.** `provisioning_clear()` only clears the NVS "xentient" namespace. WiFiManager stores WiFi creds in its own internal namespace (`wifi` or similar). After factory reset, the device still auto-connects to the old WiFi.

**Files:**
- Modify: `firmware/src/provisioning.cpp:155-167`

- [ ] **Step 1: Add WiFi.erase() to provisioning_clear()**

In `firmware/src/provisioning.cpp`, replace `provisioning_clear()`:

```cpp
void provisioning_clear() {
    // Clear NVS "xentient" namespace (mqtt, nodeId, spaceId, ws config)
    Preferences prefs;
    prefs.begin(NVS_NAMESPACE, false);
    prefs.remove(NVS_KEY_WIFI_SSID);
    prefs.remove(NVS_KEY_WIFI_PASS);
    prefs.remove(NVS_KEY_MQTT_HOST);
    prefs.remove(NVS_KEY_MQTT_PORT);
    prefs.remove(NVS_KEY_NODE_ID);
    prefs.remove(NVS_KEY_SPACE_ID);
    prefs.remove(NVS_KEY_WS_HOST);
    prefs.remove(NVS_KEY_WS_PORT);
    prefs.end();

    // Clear WiFiManager's stored WiFi credentials
    // WiFiManager uses ESP32's WiFi storage (nvs namespace "wifi")
    // WiFi.erase() clears ALL stored WiFi credentials
    WiFi.disconnect(true, true);  // disconnect + clear WiFi config
    delay(100);

    Serial.println("[PROV] NVS config + WiFi creds cleared (factory reset)");
}
```

Note: `WiFi.disconnect(true, true)` — first `true` = erase SSID/password from flash, second `true` = disconnect from current AP. This clears WiFiManager's stored creds.

- [ ] **Step 2: Also clear WiFiManager's internal portal config**

WiFiManager stores its own state. Add `wm.resetSettings()` equivalent. Since we don't have a WiFiManager instance in `provisioning_clear()`, use the WiFi API directly. `WiFi.erase()` is the ESP32 equivalent.

Actually, `WiFi.disconnect(true, true)` on ESP32 already handles this. But for extra safety, also explicitly erase the WiFiManager NVS key:

```cpp
    // Also clear WiFiManager's portal-stored credentials
    // (it uses Preferences with namespace "wifi" internally)
    Preferences wifiPrefs;
    wifiPrefs.begin("wifi", false);
    wifiPrefs.clear();
    wifiPrefs.end();
```

Wait — WiFiManager may use a different namespace. The safest approach is to use `WiFi.disconnect(true, true)` which is the ESP32 SDK-level erase. Let's keep it simple and robust:

```cpp
void provisioning_clear() {
    // Clear Xentient NVS namespace
    Preferences prefs;
    prefs.begin(NVS_NAMESPACE, false);
    prefs.remove(NVS_KEY_WIFI_SSID);
    prefs.remove(NVS_KEY_WIFI_PASS);
    prefs.remove(NVS_KEY_MQTT_HOST);
    prefs.remove(NVS_KEY_MQTT_PORT);
    prefs.remove(NVS_KEY_NODE_ID);
    prefs.remove(NVS_KEY_SPACE_ID);
    prefs.remove(NVS_KEY_WS_HOST);
    prefs.remove(NVS_KEY_WS_PORT);
    prefs.end();

    // Clear WiFiManager's stored WiFi credentials
    // This ensures factory reset truly wipes ALL stored config.
    // WiFi.disconnect(true) erases SSID/password from NVS flash.
    WiFi.disconnect(true, true);
    delay(100);

    Serial.println("[PROV] NVS + WiFi creds cleared (full factory reset)");
}
```

- [ ] **Step 3: Commit**

```bash
git add firmware/src/provisioning.cpp
git commit -m "fix(firmware): factory reset clears WiFiManager WiFi creds (S4)"
```

---

## Task 4: [HIGH] Fix Dead NVS WiFi Credentials — Remove or Document

**S3 fix.** NVS stores `wifi_ssid` and `wifi_pass`, but these are never read for WiFi connection — WiFiManager uses its own internal storage. The NVS WiFi keys are dead data that mislead anyone reading the code. Two options:
1. Remove NVS WiFi keys entirely (WiFiManager handles WiFi)
2. Keep them as backup documentation but mark as "informational only"

Going with option 1: remove the dead keys and stop writing them.

**Files:**
- Modify: `firmware/src/provisioning.cpp:65-68, 135-136, 158-159`
- Modify: `firmware/src/provisioning.h` — remove wifiSsid/wifiPass from ProvisioningConfig? NO — keep for JSON provisioning compatibility

Wait — the JSON provisioning flow from the dashboard token DOES include wifiSsid/wifiPass. The user pastes JSON that may contain WiFi creds. We need to handle that case:
- If JSON has wifiSsid/wifiPass, we should use them for WiFiManager's connection
- But WiFiManager's autoConnect already handles WiFi from its own storage
- The portal form's SSID/pass are what WiFiManager uses for THIS session

The real fix: when parsing JSON with wifiSsid/wifiPass, programmatically set WiFiManager's stored creds so they persist. Use `WiFi.begin(ssid, pass)` + `WiFi.setAutoConnect(true)` or use WiFiManager's `setConf()` method.

Actually, the simplest correct approach: remove the NVS wifi_ssid/wifi_pass keys entirely since they're never read. WiFi creds belong to WiFiManager, not NVS. If JSON has wifiSsid/wifiPass, ignore them in NVS (they were already used by WiFiManager's portal form for this session, or if JSON was pasted, WiFiManager's autoConnect already connected using the portal form's SSID/pass).

Better approach: When JSON has wifiSsid/wifiPass, we should tell WiFiManager to use those as its stored WiFi creds for future reboots. We can do this by calling `WiFi.begin()` with the JSON creds after saving them, which stores them in the ESP32 WiFi NVS:

- [ ] **Step 1: Remove NVS wifi_ssid/wifi_pass from provisioning.cpp**

In `provisioning_read_config()`, remove the lines that read `NVS_KEY_WIFI_SSID` and `NVS_KEY_WIFI_PASS`.

In `provisioning_start_portal()`, in the JSON parse section, instead of writing wifi_ssid/wifi_pass to NVS, use `WiFi.begin()` to store them in ESP32 WiFi flash:

```cpp
            // Store WiFi creds in ESP32 WiFi flash (not NVS)
            // so WiFiManager can use them on next reboot
            if (doc["wifiSsid"].is<const char*>() && doc["wifiPass"].is<const char*>()) {
                const char* ssid = doc["wifiSsid"].as<const char*>();
                const char* pass = doc["wifiPass"].as<const char*>();
                WiFi.begin(ssid, pass);  // stores to flash for auto-reconnect
                Serial.printf("[PROV] WiFi creds from JSON stored: SSID=%s\n", ssid);
            }
```

In the fallback manual-field save section, remove `NVS_KEY_WIFI_SSID` and `NVS_KEY_WIFI_PASS` writes. WiFiManager already handles WiFi cred storage internally.

In `provisioning_clear()`, remove `NVS_KEY_WIFI_SSID` and `NVS_KEY_WIFI_PASS` removals (already covered by `WiFi.disconnect(true, true)`).

In `provisioning_has_config()`, remove wifi_ssid and wifi_pass from the check (WiFiManager handles WiFi separately):

```cpp
bool provisioning_has_config() {
    Preferences prefs;
    prefs.begin(NVS_NAMESPACE, true);
    bool has = prefs.isKey(NVS_KEY_MQTT_HOST) && prefs.isKey(NVS_KEY_NODE_ID);
    prefs.end();
    return has;
}
```

Wait — we also removed wifi_pass. But what if someone provisions ONLY via the JSON field with WiFi creds? In that case WiFiManager's autoConnect has already connected using the portal form's SSID/pass. The JSON WiFi creds are for NEXT reboot. We need WiFiManager to pick them up.

Actually the simplest correct fix: In the JSON parse branch, after parsing, also call `WiFi.setAutoConnect(true)` and manually store the credentials via `WiFi.begin()`:

```cpp
if (doc["wifiSsid"].is<const char*>() && doc["wifiPass"].is<const char*>()) {
    const char* jSsid = doc["wifiSsid"].as<const char*>();
    const char* jPass = doc["wifiPass"].as<const char*>();
    // Store JSON WiFi creds in ESP32 WiFi NVS for future autoConnect
    WiFi.setAutoConnect(true);
    WiFi.begin(jSsid, jPass);
    delay(100);
}
```

But this is a bit risky — we're already connected via the portal's WiFi, and calling `WiFi.begin()` might disconnect and reconnect. Let's use a simpler approach: just use `WiFi.setAutoConnect(true)` and store the creds via the ESP32 NVS API directly:

Actually, the safest approach for the demo: just remove the NVS wifi keys and add a Serial note. WiFiManager handles WiFi. JSON wifi creds are informational only — if they differ from the portal form, the user will need to re-provision. This is acceptable for demo scope.

- [ ] **Step 1: Remove dead NVS WiFi keys from provisioning_has_config()**

In `firmware/src/provisioning.cpp`, change `provisioning_has_config()`:

```cpp
bool provisioning_has_config() {
    // WiFi connectivity is managed by WiFiManager (separate NVS namespace).
    // We only check MQTT + nodeId — the keys that Xentient NVS owns.
    Preferences prefs;
    prefs.begin(NVS_NAMESPACE, true);
    bool has = prefs.isKey(NVS_KEY_MQTT_HOST) && prefs.isKey(NVS_KEY_NODE_ID);
    prefs.end();
    return has;
}
```

- [ ] **Step 2: Remove NVS WiFi key writes from provisioning_start_portal()**

In the JSON parse branch, remove:
```cpp
            if (doc["wifiSsid"].is<const char*>())
                prefs.putString(NVS_KEY_WIFI_SSID, doc["wifiSsid"].as<const char*>());
            if (doc["wifiPass"].is<const char*>())
                prefs.putString(NVS_KEY_WIFI_PASS, doc["wifiPass"].as<const char*>());
```

Replace with:
```cpp
            // WiFi creds are handled by WiFiManager, not NVS.
            // If JSON has different WiFi than portal form, the user must
            // re-provision next session (acceptable for demo scope — S3 note).
```

In the manual-field fallback, remove:
```cpp
    prefs.putString(NVS_KEY_WIFI_SSID, p_ssid.getValue());
    prefs.putString(NVS_KEY_WIFI_PASS, p_pass.getValue());
```

Replace with comment:
```cpp
    // WiFi SSID/pass stored by WiFiManager internally — not in Xentient NVS
```

In `provisioning_read_config()`, remove:
```cpp
    if (prefs.isKey(NVS_KEY_WIFI_SSID))
        safeStrncpy(cfg.wifiSsid, prefs.getString(NVS_KEY_WIFI_SSID).c_str(), sizeof(cfg.wifiSsid));
    if (prefs.isKey(NVS_KEY_WIFI_PASS))
        safeStrncpy(cfg.wifiPass, prefs.getString(NVS_KEY_WIFI_PASS).c_str(), sizeof(cfg.wifiPass));
```

- [ ] **Step 3: Remove NVS WiFi key removals from provisioning_clear()**

Remove:
```cpp
    prefs.remove(NVS_KEY_WIFI_SSID);
    prefs.remove(NVS_KEY_WIFI_PASS);
```

They're already handled by `WiFi.disconnect(true, true)`.

- [ ] **Step 4: Remove NVS_KEY_WIFI_SSID/PASS constants**

In the anonymous namespace at the top of provisioning.cpp, remove:
```cpp
constexpr const char* NVS_KEY_WIFI_SSID = "wifi_ssid";
constexpr const char* NVS_KEY_WIFI_PASS = "wifi_pass";
```

- [ ] **Step 5: Commit**

```bash
git add firmware/src/provisioning.cpp
git commit -m "fix(firmware): remove dead NVS WiFi keys — WiFiManager owns WiFi lifecycle (S3)"
```

---

## Task 5: [MEDIUM] Add JSON Parse Error Feedback in WiFiManager Portal

**S8 fix.** When a user pastes malformed JSON, the firmware falls back to manual fields silently (only a Serial message). The user has no indication that their JSON was rejected. Add visible feedback.

**Files:**
- Modify: `firmware/src/provisioning.cpp:97-103`

- [ ] **Step 1: Add a WiFiManager custom parameter for status display**

WiFiManager doesn't natively support status messages in the portal. The workaround is to add a read-only parameter that shows the result. But WiFiManager's custom HTML support is limited.

A simpler approach: use WiFiManager's `setCustomHeadElement()` to inject a small JavaScript that validates the JSON field client-side before form submission.

In `provisioning_start_portal()`, before `wm.autoConnect()`:

```cpp
    // Client-side JSON validation in portal
    const char* jsonValidateScript = R"(
<script>
document.addEventListener('DOMContentLoaded', function() {
  var jsonField = document.getElementById('prov_json');
  var form = jsonField ? jsonField.closest('form') : null;
  if (form && jsonField) {
    form.addEventListener('submit', function(e) {
      var val = jsonField.value.trim();
      if (val.length > 0) {
        try { JSON.parse(val); }
        catch(err) {
          e.preventDefault();
          alert('Provisioning JSON parse error: ' + err.message + '\\nPlease fix the JSON or clear the field to use manual entries.');
          return false;
        }
      }
    });
  }
});
</script>
)";
    wm.setCustomHeadElement(jsonValidateScript);
```

- [ ] **Step 2: Add firmware-side fallback logging for partial JSON**

After the JSON parse succeeds but before saving to NVS, add a validation check for required fields:

```cpp
        if (!err) {
            // Validate required fields
            if (!doc["mqttBroker"].is<const char*>() && !doc["nodeId"].is<const char*>()) {
                Serial.println("[PROV] JSON missing required fields (mqttBroker, nodeId) — saving what we have");
            }
            // ... existing NVS save code ...
```

- [ ] **Step 3: Commit**

```bash
git add firmware/src/provisioning.cpp
git commit -m "fix(firmware): add client-side JSON validation + required-field check in portal (S8)"
```

---

## Task 6: [MEDIUM] Fix Portal Timeout — Deep Sleep Instead of Restart Loop

**S7 fix.** Currently, portal timeout (180s with no user action) triggers `ESP.restart()`, which reboots into the same portal, creating an infinite loop. Add a deep sleep fallback so the device doesn't thrash.

**Files:**
- Modify: `firmware/src/main.cpp:340-344`

- [ ] **Step 1: Add deep sleep on portal timeout**

In `firmware/src/main.cpp`, replace the portal timeout restart:

```cpp
        if (!provisioning_start_portal()) {
            Serial.println("[BOOT] Portal timeout — entering deep sleep for 60s then retry");
            lcd_display_face("(x_x)", "timeout...");
            delay(1000);
            esp_sleep_enable_timer_wakeup(60 * 1000000); // 60s in microseconds
            esp_deep_sleep_start();
            // Never reaches here — wakes up and re-runs setup()
        }
```

Same for the "no NVS config" branch:

```cpp
        if (!provisioning_start_portal()) {
            Serial.println("[BOOT] Portal timeout — entering deep sleep for 60s then retry");
            lcd_display_face("(x_x)", "timeout...");
            delay(1000);
            esp_sleep_enable_timer_wakeup(60 * 1000000);
            esp_deep_sleep_start();
        }
```

- [ ] **Step 2: Commit**

```bash
git add firmware/src/main.cpp
git commit -m "fix(firmware): portal timeout enters 60s deep sleep instead of restart loop (S7)"
```

---

## Task 7: [LOW] Add Partial JSON Warning for Incomplete Config

**S8 partial fix.** When JSON parses successfully but is missing required fields (mqttBroker, nodeId), the firmware saves whatever it has. Add a warning Serial log so debugging is easier, and add a runtime check after `provisioning_read_config()` in main.cpp.

**Files:**
- Modify: `firmware/src/main.cpp` — add config completeness check after provisioning

- [ ] **Step 1: Add config validation after provisioning_read_config()**

In `firmware/src/main.cpp`, after `cfg = provisioning_read_config()`, add:

```cpp
    // Validate config completeness
    if (cfg.mqttHost[0] == '\0' || cfg.nodeId[0] == '\0') {
        Serial.println("[BOOT] Incomplete config — mqttHost or nodeId missing, restarting portal");
        provisioning_clear();
        lcd_display_face("(?_?)", "bad config");
        delay(2000);
        esp_sleep_enable_timer_wakeup(10 * 1000000); // 10s
        esp_deep_sleep_start();
    }
```

- [ ] **Step 2: Commit**

```bash
git add firmware/src/main.cpp
git commit -m "fix(firmware): validate config completeness after provisioning (S8)"
```

---

## Task 8: Harness — Wire MQTT Reconnect → Profile Replay for Birth Messages

**S6 continuation.** When MQTT reconnects after a broker restart, the firmware should re-publish its birth message. The harness should re-push profiles.

**Files:**
- Modify: `firmware/src/mqtt_client.cpp` — re-publish birth on reconnect
- Modify: `harness/src/engine/SpaceManager.ts` — onMqttReconnect re-pushes profiles

- [ ] **Step 1: Re-publish birth message in mqtt_reconnect()**

In `firmware/src/mqtt_client.cpp`, in the `SYSTEM_EVENT_STA_GOT_IP` handler (already in main.cpp) and in `mqtt_reconnect()`, after successful connect, the birth message is already published in `mqtt_connect()`. Since `mqtt_reconnect()` calls `mqtt_connect()`, this is already handled. No change needed.

- [ ] **Step 2: Verify onMqttReconnect in SpaceManager already replays profiles**

Looking at `SpaceManager.onMqttReconnect()`:

```typescript
  onMqttReconnect(): void {
    logger.info('MQTT reconnected — replaying active configurations');
    for (const [spaceId, space] of this.spaces) {
```

This already re-pushes active profiles. Combined with the birth message, the harness now has full reconnect detection. No code change needed — just verification.

- [ ] **Step 3: Verify — done, no code change needed**

---

## Task 9: Harness — Add NodeProvisioner for Dynamic Node Registration

**S5 + S9 + S11 fix.** Currently the harness uses a static Space with hardcoded nodeId. Add `NodeProvisioner` for dynamic token generation and `confirmNode()`.

**Files:**
- Create: `harness/src/comms/NodeProvisioner.ts`
- Modify: `harness/src/shared/types.ts` — add `ProvisioningToken`, update `SpaceNode`
- Modify: `harness/src/engine/SpaceManager.ts` — add `registerNode()`, `updateNodeStatus()`, `removeNode()`
- Modify: `harness/src/mcp/tools.ts` — add `xentient_register_node` MCP tool
- Modify: `harness/src/comms/ControlServer.ts` — add `POST /api/nodes/register`
- Create: `harness/tests/node-provisioner.test.ts`

- [ ] **Step 1: Add ProvisioningToken type and update SpaceNode in types.ts**

In `harness/src/shared/types.ts`, add:

```typescript
/** Token generated by Core for ESP32 provisioning */
export interface ProvisioningToken {
  nodeId: string;
  spaceId: string;
  mqttBroker: string;
  mqttPort: number;
  wsHost: string;
  wsPort: number;
  wifiSsid?: string;
  wifiPass?: string;
}
```

Update `SpaceNode` type to include `status` and `lastSeen`:

```typescript
export interface SpaceNode {
  nodeId: string;
  role: string;
  hardware: string[];
  state: 'dormant' | 'running';
  status?: 'pending' | 'active';  // provisioning status
  lastSeen?: number;               // last birth message timestamp
}
```

- [ ] **Step 2: Create NodeProvisioner.ts**

```typescript
import { randomUUID } from 'crypto';
import type { ProvisioningToken } from '../shared/types';
import type { SpaceManager } from '../engine/SpaceManager';
import pino from 'pino';

const logger = pino({ name: 'node-provisioner' }, process.stderr);

export class NodeProvisioner {
  private pendingTokens = new Map<string, {
    token: ProvisioningToken;
    spaceId: string;
    role: string;
    hardware: string[];
    createdAt: number;
  }>();

  constructor(
    private getMqttBroker: () => { host: string; port: number },
    private getWsHost: () => { host: string; port: number },
    private spaceManager: SpaceManager,
  ) {}

  generateToken(spaceId: string, role: string, hardware: string[], wifiSsid?: string): ProvisioningToken {
    const nodeId = `node_${randomUUID().slice(0, 8)}`;
    const token: ProvisioningToken = {
      nodeId,
      spaceId,
      mqttBroker: this.getMqttBroker().host,
      mqttPort: this.getMqttBroker().port,
      wsHost: this.getWsHost().host,
      wsPort: this.getWsHost().port,
      wifiSsid,
    };

    // Register node in SpaceManager immediately (no orphan tokens)
    this.spaceManager.registerNode(spaceId, {
      nodeId,
      role,
      hardware,
      state: 'dormant',
      status: 'pending',
      lastSeen: Date.now(),
    });

    this.pendingTokens.set(nodeId, { token, spaceId, role, hardware, createdAt: Date.now() });
    logger.info({ nodeId, spaceId }, 'Provisioning token generated');
    return token;
  }

  confirmNode(nodeId: string): boolean {
    const pending = this.pendingTokens.get(nodeId);
    if (!pending) return false;
    this.pendingTokens.delete(nodeId);
    this.spaceManager.updateNodeStatus(pending.spaceId, nodeId, 'active');
    logger.info({ nodeId }, 'Node confirmed — active');
    return true;
  }

  cleanupStale(ttlMs = 3600000): number {
    const now = Date.now();
    let cleaned = 0;
    for (const [nodeId, entry] of this.pendingTokens.entries()) {
      if (now - entry.createdAt > ttlMs) {
        this.spaceManager.removeNode(entry.token.spaceId, nodeId);
        this.pendingTokens.delete(nodeId);
        cleaned++;
        logger.warn({ nodeId }, 'Stale provisioning token cleaned up');
      }
    }
    return cleaned;
  }
}
```

- [ ] **Step 3: Add registerNode/updateNodeStatus/removeNode to SpaceManager**

In `harness/src/engine/SpaceManager.ts`, add three new methods:

```typescript
  registerNode(spaceId: string, node: SpaceNode): boolean {
    const space = this.spaces.get(spaceId);
    if (!space) return false;
    if (space.nodes.some(n => n.nodeId === node.nodeId)) return false;
    space.nodes.push(node);
    logger.info({ nodeId: node.nodeId, spaceId }, 'Node registered');
    return true;
  }

  updateNodeStatus(spaceId: string, nodeId: string, status: string): boolean {
    const space = this.spaces.get(spaceId);
    if (!space) return false;
    const node = space.nodes.find(n => n.nodeId === nodeId);
    if (!node) return false;
    (node as any).status = status;
    (node as any).lastSeen = Date.now();
    return true;
  }

  removeNode(spaceId: string, nodeId: string): boolean {
    const space = this.spaces.get(spaceId);
    if (!space) return false;
    const idx = space.nodes.findIndex(n => n.nodeId === nodeId);
    if (idx < 0) return false;
    space.nodes.splice(idx, 1);
    logger.info({ nodeId, spaceId }, 'Node removed');
    return true;
  }
```

- [ ] **Step 4: Wire NodeProvisioner into core.ts**

In `harness/src/core.ts`, after SpaceManager creation:

```typescript
  import { NodeProvisioner } from './comms/NodeProvisioner';

  // After spaceManager is created...
  const nodeProvisioner = new NodeProvisioner(
    () => ({ host: config.mqtt.brokerUrl.split('//')[1]?.split(':')[0] ?? 'localhost', port: 1883 }),
    () => ({ host: config.mqtt.brokerUrl.split('//')[1]?.split(':')[0] ?? 'localhost', port: parseInt(process.env.WS_PORT ?? String(config.audio.wsPort), 10) }),
    spaceManager,
  );

  // Wire nodeBirth → confirmNode
  mqtt.on('nodeBirth', (data: { nodeId: string }) => {
    nodeProvisioner.confirmNode(data.nodeId);
    spaceManager.onNodeBirth(data.nodeId);
  });

  // Cleanup stale tokens every 5 minutes
  setInterval(() => nodeProvisioner.cleanupStale(), 300000);
```

- [ ] **Step 5: Add xentient_register_node MCP tool**

In `harness/src/mcp/tools.ts`, add a new tool handler:

```typescript
    xentient_register_node: async ({ spaceId, role, hardware, wifiSsid }: {
      spaceId?: string; role?: string; hardware?: string[]; wifiSsid?: string;
    }) => {
      const sid = spaceId ?? 'default';
      const r = role ?? 'base';
      const hw = hardware ?? ['motion', 'temperature', 'humidity', 'audio', 'camera'];
      const token = deps.nodeProvisioner?.generateToken(sid, r, hw, wifiSsid);
      if (!token) {
        return { content: [{ type: 'text' as const, text: 'NodeProvisioner not available' }] };
      }
      return {
        content: [{
          type: 'text' as const,
          text: `Node registered. Paste this JSON into your Xentient-Setup portal:\n\n${JSON.stringify(token, null, 2)}`,
        }],
      };
    },
```

Add to `McpToolDeps`:
```typescript
  nodeProvisioner?: NodeProvisioner;
```

- [ ] **Step 6: Add POST /api/nodes/register REST endpoint**

In `harness/src/comms/ControlServer.ts`, add a new route handler (following the existing REST endpoint pattern):

```typescript
    // POST /api/nodes/register — generate provisioning token
    this.app.post('/api/nodes/register', async (req, res) => {
      const { spaceId = 'default', role = 'base', hardware, wifiSsid } = req.body;
      const token = this.deps.nodeProvisioner?.generateToken(
        spaceId, role, hardware ?? ['motion', 'temperature', 'humidity', 'audio', 'camera'], wifiSsid,
      );
      if (!token) {
        res.status(503).json({ error: 'NodeProvisioner not available' });
        return;
      }
      res.json({ token, json: JSON.stringify(token, null, 2) });
    });
```

- [ ] **Step 7: Write tests for NodeProvisioner**

Create `harness/tests/node-provisioner.test.ts`:

```typescript
import { describe, it, expect, vi, beforeEach } from 'vitest';
import { NodeProvisioner } from '../src/comms/NodeProvisioner';

function mockSpaceManager() {
  const nodes: any[] = [];
  return {
    registerNode: vi.fn((spaceId: string, node: any) => { nodes.push(node); return true; }),
    updateNodeStatus: vi.fn((spaceId: string, nodeId: string, status: string) => {
      const n = nodes.find(x => x.nodeId === nodeId);
      if (n) n.status = status;
      return true;
    }),
    removeNode: vi.fn((spaceId: string, nodeId: string) => {
      const idx = nodes.findIndex(x => x.nodeId === nodeId);
      if (idx >= 0) nodes.splice(idx, 1);
      return true;
    }),
  } as any;
}

describe('NodeProvisioner', () => {
  let sm: any;
  let provisioner: NodeProvisioner;

  beforeEach(() => {
    sm = mockSpaceManager();
    provisioner = new NodeProvisioner(
      () => ({ host: '10.0.0.1', port: 1883 }),
      () => ({ host: '10.0.0.1', port: 8080 }),
      sm,
    );
  });

  it('generates token with unique nodeId and registers in SpaceManager', () => {
    const token = provisioner.generateToken('default', 'base', ['motion']);
    expect(token.nodeId).toMatch(/^node_[a-f0-9]{8}$/);
    expect(token.spaceId).toBe('default');
    expect(token.mqttBroker).toBe('10.0.0.1');
    expect(sm.registerNode).toHaveBeenCalledWith('default', expect.objectContaining({
      nodeId: token.nodeId,
      status: 'pending',
    }));
  });

  it('generates unique nodeIds across calls', () => {
    const a = provisioner.generateToken('default', 'base', ['motion']);
    const b = provisioner.generateToken('default', 'base', ['motion']);
    expect(a.nodeId).not.toBe(b.nodeId);
  });

  it('confirms a pending node transitions to active', () => {
    const token = provisioner.generateToken('default', 'base', ['motion']);
    expect(provisioner.confirmNode(token.nodeId)).toBe(true);
    expect(sm.updateNodeStatus).toHaveBeenCalledWith('default', token.nodeId, 'active');
  });

  it('returns false for unknown nodeId confirm', () => {
    expect(provisioner.confirmNode('unknown')).toBe(false);
  });

  it('cleanupStale removes expired tokens', () => {
    provisioner.generateToken('default', 'base', ['motion']);
    // TTL=0 means everything is stale
    const cleaned = provisioner.cleanupStale(0);
    expect(cleaned).toBeGreaterThanOrEqual(1);
    expect(sm.removeNode).toHaveBeenCalled();
  });
});
```

- [ ] **Step 8: Commit**

```bash
git add harness/src/comms/NodeProvisioner.ts harness/src/shared/types.ts harness/src/engine/SpaceManager.ts harness/src/mcp/tools.ts harness/src/comms/ControlServer.ts harness/src/core.ts harness/tests/node-provisioner.test.ts
git commit -m "feat(harness): add NodeProvisioner for dynamic node registration (S5, S9, S11)"
```

---

## Self-Review

### Spec Coverage

| Scenario | Task | Status |
|---|---|---|
| S1 | No separate task — portal pre-fills are acceptable for demo | ACCEPTABLE |
| S2 | No fix needed — WiFiManager handles correctly | N/A |
| S3 | Task 4 | Fixed |
| S4 | Task 3 | Fixed |
| S5 | Task 9 | Fixed |
| S6 | Task 2 | Fixed |
| S7 | Task 6 | Fixed |
| S8 | Task 5 + Task 7 | Fixed |
| S9 | Task 9 | Fixed |
| S10 | Task 1 | Fixed |
| S11 | Task 9 | Fixed |
| S12 | Tasks 1+2+3+4 | Demo path unblocked |

### Placeholder Scan

No TBDs, TODOs, or "implement later" found. All code blocks contain actual implementation code.

### Type Consistency

- `ProvisioningConfig.wifiSsid/wifiPass` — kept in the struct for JSON compatibility even though NVS no longer stores them. The `provisioning_read_config()` just returns empty strings for these fields now. This is fine — they're informational.
- `mqtt_init()` signature changed to `(const char* brokerHost, uint16_t brokerPort, const char* nodeId = nullptr)` — the default `nullptr` means callers that don't pass nodeId still work (falls back to `NODE_BASE_ID`).
- `buildNodeTopic()` uses `snprintf` with buf/len — standard C pattern, no heap allocation.
- `SpaceNode.status` added as optional field — backward compatible with existing code that doesn't set it.

---

## Demo Happy Path (S12) — Minimum Fix Set

To make the demo work, implement these tasks in order:

1. **Task 1** (S10) — MQTT topic `{nodeId}` resolution. Without this, profile hot-swap is completely broken.
2. **Task 2** (S6) — Birth message. Without this, harness doesn't know the node is online.
3. **Task 3** (S4) — Factory reset. Without this, you can't recover a misconfigured device without serial monitor.
4. **Task 4** (S3) — Remove dead NVS WiFi keys. Cleanup, not blocking but prevents confusion.

Tasks 5-9 are improvements but not demo-blockers.

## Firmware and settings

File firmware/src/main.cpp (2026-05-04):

#include <Arduino.h>
#include <Wire.h>
#include <WiFi.h>
#include <ArduinoJson.h>
#include <esp_task_wdt.h>

#include "freertos/FreeRTOS.h"
#include "freertos/task.h"

#include "pins.h"
#include "peripherals.h"
#include "lcd_driver.h"
#include "mqtt_client.h"
#include "bme_reader.h"
#include "i2s_mic.h"
#include "vad.h"
#include "ws_audio.h"
#include "cam_relay.h"
#include "messages.h"
#include "provisioning.h"

// RTC memory survives deep sleep — used for exponential backoff
RTC_DATA_ATTR static uint8_t bootFailCount = 0;

// ============================================================================
//  Shared state — two-task model
// ============================================================================
portMUX_TYPE       profileMux           = portMUX_INITIALIZER_UNLOCKED;
volatile NodeProfile activeProfile;
volatile NodeProfile pendingProfile;
volatile bool       profileUpdateFlag    = false;
char               lastReceivedProfileId[32] = {0};

// ============================================================================
//  Helpers
// ============================================================================

static bool i2c_ping(uint8_t addr) {
    Wire.beginTransmission(addr);
    return (Wire.endTransmission() == 0);
}

// ============================================================================
//  PIR interrupt (GPIO13)
// ============================================================================
static volatile bool pirTriggered = false;
void IRAM_ATTR pir_isr() {
    pirTriggered = true;
}

// ============================================================================
//  VAD state
// ============================================================================
static volatile bool  vad_was_active    = false;
static volatile bool vad_is_active      = false;
static volatile uint32_t vad_start_millis = 0;
static bool last_vad_active = false;

// VAD start -> trigger_pipeline{source:"voice"}
static void publish_vad_start() {
    if (!mqtt_connected()) return;
    JsonDocument doc;
    doc["v"]      = MSG_VERSION;
    doc["type"]   = "trigger_pipeline";
    doc["source"] = TRIGGER_SOURCE_VOICE;
    char buf[128];
    serializeJson(doc, buf, sizeof(buf));
    mqtt_publish(TOPIC_TRIGGER, buf, strlen(buf));
    Serial.println("[VAD] Published: trigger_pipeline source=voice");
    vad_start_millis = millis();
    vad_is_active = true;
}

// VAD end -> trigger_pipeline{source:"voice", stage:"end"}
static void publish_vad_end() {
    if (!mqtt_connected()) return;
    vad_was_active = vad_is_active;
    vad_is_active = false;
    JsonDocument doc;
    doc["v"]           = MSG_VERSION;
    doc["type"]        = "trigger_pipeline";
    doc["source"]      = TRIGGER_SOURCE_VOICE;
    doc["stage"]       = "end";
    doc["duration_ms"] = (uint32_t)(millis() - vad_start_millis);
    char buf[128];
    serializeJson(doc, buf, sizeof(buf));
    mqtt_publish(TOPIC_TRIGGER, buf, strlen(buf));
    Serial.printf("[VAD] Voice end - duration %lu ms\n",
                  (unsigned long)(millis() - vad_start_millis));
}

// ============================================================================
//  LCD face mapping from NodeProfile.lcd_face
// ============================================================================
static void apply_lcd_face(uint8_t lcd_face) {
    switch (lcd_face) {
        case 0:  lcd_set_state(NodeState::LISTENING);  break; // calm
        case 1:  lcd_set_state(NodeState::ERROR_STATE); break; // alert
        case 2:  lcd_set_state(NodeState::LISTENING);  break; // listening
        case 3:  lcd_set_state(NodeState::SPEAKING);   break; // speaking
        default: lcd_set_state(NodeState::LISTENING);  break;
    }
}

// ============================================================================
//  Sensor reconfiguration after profile hot-swap
// ============================================================================
static void reconfigure_sensors(const NodeProfile& p) {
    Serial.printf("[CONFIG] Applying profile '%s': pir=%u bme=%u mic=%u cam=%u lcd=%u mask=0x%04X\n",
                 p.profile_id, p.pir_interval_ms, p.bme_interval_ms,
                 p.mic_mode, p.camera_mode, p.lcd_face, p.event_mask);
    apply_lcd_face(p.lcd_face);
}

// ============================================================================
//  Task handles
// ============================================================================
static TaskHandle_t workTaskHandle  = nullptr;
static TaskHandle_t configTaskHandle = nullptr;

// ============================================================================
//  Work Task — Core 1, high priority
//  Runs the activeProfile: reads sensors at declared intervals, publishes
//  events based on event_mask, controls actuators. Checks profileUpdateFlag
//  at the end of each iteration (Config Task handles the swap).
// ============================================================================

static int16_t s_pcm[I2S_MIC_CHUNK_SAMPLES];
static unsigned long lastPirMs       = 0;
static unsigned long lastBmeMs       = 0;

static float rounded2(float v) { return round(v * 100.0F) / 100.0F; }

static void work_task(void* /*pvParameters*/) {
    // Register with ESP32 task watchdog (5s timeout, panic-on-timeout)
    esp_err_t wdt_err = esp_task_wdt_add(nullptr);
    if (wdt_err != ESP_OK) {
        Serial.printf("[WORK] WDT add failed: %d\n", wdt_err);
    }
    esp_task_wdt_reset();
    Serial.println("[WORK] Task started on core " + String(xPortGetCoreID()));

    while (true) {
        // -- Snapshot activeProfile under critical section --
        // We only need the intervals and mask for this iteration.
        // Copying the whole struct under the spinlock is cheap (sizeof ~42 bytes).
        NodeProfile snap;
        portENTER_CRITICAL(&profileMux);
        memcpy(&snap, (const void*)&activeProfile, sizeof(NodeProfile));
        portEXIT_CRITICAL(&profileMux);

        uint32_t now = millis();

        // -- PIR: atomic read-and-clear (H1: prevents ISR edge loss) --
        bool pirFired = false;
        portENTER_CRITICAL(&profileMux);
        if (pirTriggered) {
            pirFired = true;
            pirTriggered = false;
        }
        portEXIT_CRITICAL(&profileMux);

        if ((snap.event_mask & (EVENT_MASK_PRESENCE | EVENT_MASK_MOTION)) &&
            pirFired && mqtt_connected()) {
            JsonDocument doc;
            doc["v"]              = MSG_VERSION;
            doc["type"]           = "sensor_data";
            doc["peripheralType"] = PERIPHERAL_TYPE_PIR;
            JsonObject payload    = doc["payload"].to<JsonObject>();
            payload["motion"]     = true;
            doc["timestamp"]      = (uint32_t)now;
            char buf[128];
            serializeJson(doc, buf, sizeof(buf));
            mqtt_publish(TOPIC_MOTION, buf, strlen(buf));
            Serial.println("[PIR] Motion detected - published sensor_data");
            lastPirMs = now;
        }

        // -- BME280 telemetry at bme_interval_ms --
        if ((snap.event_mask & EVENT_MASK_ENV) &&
            mqtt_connected() &&
            (now - lastBmeMs >= snap.bme_interval_ms)) {
            lastBmeMs = now;
            BmeReading reading;
            if (bme_read(reading)) {
                JsonDocument doc;
                doc["v"]               = MSG_VERSION;
                doc["type"]            = "sensor_data";
                doc["peripheralType"]  = PERIPHERAL_TYPE_BME280;
                JsonObject payload     = doc["payload"].to<JsonObject>();
                payload["temperature"] = rounded2(reading.temperature);
                payload["humidity"]    = rounded2(reading.humidity);
                payload["pressure"]    = rounded2(reading.pressure);
                doc["timestamp"]       = (uint32_t)now;
                char buf[256];
                serializeJson(doc, buf, sizeof(buf));
                mqtt_publish(TOPIC_ENV, buf, strlen(buf));
            }
        }

        // -- Mic + VAD (only if mic_mode != 0) --
        if (snap.mic_mode != 0 && i2s_mic_read(s_pcm, I2S_MIC_CHUNK_SAMPLES)) {
            VadResult vad = vad_process(s_pcm, I2S_MIC_CHUNK_SAMPLES);
            last_vad_active = vad.active;

            // VAD event
            if (vad.transitioned) {
                if (vad.active) {
                    publish_vad_start();
                }
            }

            // Audio chunk forwarding (always-on or VAD-active)
            bool should_send = (snap.mic_mode == 2) ||  // always-on
                               (snap.mic_mode == 1 && vad.active); // vad-only
            if (should_send && (snap.event_mask & EVENT_MASK_AUDIO_CHUNK)) {
                ws_audio_send((const uint8_t*)s_pcm, I2S_MIC_CHUNK_BYTES);
            }
        }

        // -- VAD end detection (silence after speech) --
        if (vad_is_active && !last_vad_active && mqtt_connected()) {
            publish_vad_end();
        }

        // -- Camera relay loop (UART -> WS forwarding) --
        if (snap.camera_mode != 0 && (snap.event_mask & EVENT_MASK_FRAME)) {
            cam_relay_loop();
        }

        // -- WebSocket audio loop (outbound queue drain) --
        ws_audio_loop();

        // -- MQTT loop (keepalive + inbound processing) --
        mqtt_loop();

        // -- Reset watchdog after successful sensor cycle --
        esp_task_wdt_reset();

        // -- Yield: let other tasks run. Use the shortest sensor interval as
        //    the work cycle to avoid busy-waiting, but cap at 10ms minimum. --
        uint16_t min_interval = snap.pir_interval_ms;
        if (snap.bme_interval_ms < min_interval)
            min_interval = snap.bme_interval_ms;
        uint16_t sleep_ms = min_interval / 4;
        if (sleep_ms < 10) sleep_ms = 10;
        vTaskDelay(pdMS_TO_TICKS(sleep_ms));
    }
}

// ============================================================================
//  Config Task — Core 0, low priority
//  Sleeps 500ms, wakes, checks profileUpdateFlag. If set, copies
//  pendingProfile -> activeProfile under critical section, clears flag,
//  reconfigures sensors, sends node_profile_ack.
//  Never parses JSON — all parsing done in MQTT callback.
// ============================================================================

static void config_task(void* /*pvParameters*/) {
    Serial.println("[CONFIG] Task started on core " + String(xPortGetCoreID()));

    while (true) {
        vTaskDelay(pdMS_TO_TICKS(500));

        if (profileUpdateFlag) {
            // -- Swap profile under critical section --
            portENTER_CRITICAL(&profileMux);
            memcpy((void*)&activeProfile, (const void*)&pendingProfile, sizeof(NodeProfile));
            profileUpdateFlag = false;
            portEXIT_CRITICAL(&profileMux);

            Serial.printf("[CONFIG] Profile swapped to '%s'\n", activeProfile.profile_id);

            // -- Reconfigure sensors outside critical section --
            NodeProfile snap;
            portENTER_CRITICAL(&profileMux);
            memcpy(&snap, (const void*)&activeProfile, sizeof(NodeProfile));
            portEXIT_CRITICAL(&profileMux);
            reconfigure_sensors(snap);

            // -- Send ack echoing lastReceivedProfileId --
            send_profile_ack("loaded");
        }
    }
}

// ============================================================================
//  WiFi event handler — reconnect MQTT when WiFi reconnects (8.6)
// ============================================================================

void wifi_event_cb(WiFiEvent_t event) {
    switch (event) {
        case SYSTEM_EVENT_STA_GOT_IP:
            Serial.println("[WIFI] Got IP — triggering MQTT reconnect");
            mqtt_reconnect();
            break;
        default:
            break;
    }
}

// ============================================================================
//  setup
// ============================================================================

void setup() {
    Serial.begin(115200);
    delay(500);
    Serial.println("[BOOT] Xentient Node Base starting...");

    Wire.begin(PIN_I2C_SDA, PIN_I2C_SCL);
    Wire.setTimeout(1000);

    for (size_t i = 0; i < PERIPHERAL_COUNT; i++) {
        const PeripheralDef& p = PERIPHERALS[i];
        if (p.i2cAddr == 0x00) continue;
        bool present = i2c_ping(p.i2cAddr);
        Serial.printf("[BOOT] %s (0x%02X): %s\n", p.name, p.i2cAddr, present ? "online" : "offline");
    }

    lcd_init();
    lcd_set_state(NodeState::BOOT);

    bool bmeOk = bme_init();
    Serial.printf("[BOOT] BME280: %s\n", bmeOk ? "online" : "offline");

    // -- Initialize activeProfile with DEFAULT_PROFILE --
    memcpy((void*)&activeProfile, &DEFAULT_PROFILE, sizeof(NodeProfile));
    Serial.printf("[BOOT] activeProfile = '%s'\n", activeProfile.profile_id);

    // -- Factory reset: hold BOOT button (GPIO0) for 3s on power-up --
    if (provisioning_check_factory_reset()) {
        ESP.restart();
    }

    // Migrate legacy NVS keys from pre-S3 firmware
    provisioning_migrate_legacy();

    // -- Provisioning: NVS → portal fallback, WiFiManager owns WiFi lifecycle --
    ProvisioningConfig cfg;
    if (provisioning_has_config()) {
        cfg = provisioning_read_config();
        Serial.printf("[BOOT] NVS config: node=%s space=%s mqtt=%s:%u\n",
                     cfg.nodeId, cfg.spaceId, cfg.mqttHost, cfg.mqttPort);
        if (!provisioning_start_portal()) {
            Serial.println("[BOOT] Portal timeout — entering deep sleep for 60s then retry");
            lcd_display_face("(x_x)", "timeout...");
            delay(1000);
            esp_sleep_enable_timer_wakeup(60 * 1000000); // 60s in microseconds
            esp_deep_sleep_start();
        }
    } else {
        Serial.println("[BOOT] No NVS config — starting provisioning portal");
        lcd_set_state(NodeState::BOOT);
        lcd_display_face("(+_-)", "setup mode...");
        if (!provisioning_start_portal()) {
            Serial.println("[BOOT] Portal timeout — entering deep sleep for 60s then retry");
            lcd_display_face("(x_x)", "timeout...");
            delay(1000);
            esp_sleep_enable_timer_wakeup(60 * 1000000); // 60s in microseconds
            esp_deep_sleep_start();
        }
        cfg = provisioning_read_config();
    }

    // WiFi is now connected (WiFiManager guaranteed this or we restarted)
    Serial.printf("[WIFI] Connected. IP: %s\n", WiFi.localIP().toString().c_str());

    // Validate config completeness
    if (cfg.mqttHost[0] == '\0' || cfg.nodeId[0] == '\0') {
        bootFailCount++;
        // Exponential backoff: 10s, 20s, 40s, 80s, 160s, 320s→capped 300s
        uint8_t shift = min((uint8_t)(bootFailCount - 1), (uint8_t)5);
        uint32_t sleepSecs = min(10u << shift, 300u);
        Serial.printf("[BOOT] Incomplete config (fail %u) — sleeping %us then retry\n", bootFailCount, sleepSecs);
        provisioning_clear();
        lcd_display_face("(?_?)", "bad config");
        delay(2000);
        esp_sleep_enable_timer_wakeup((uint64_t)sleepSecs * 1000000);
        esp_deep_sleep_start();
    }

    bootFailCount = 0; // Config valid — reset failure counter

    // Register WiFi event handler for MQTT reconnect on WiFi reconnect (8.6)
    WiFi.onEvent(wifi_event_cb);

    mqtt_init(cfg.mqttHost, cfg.mqttPort, cfg.nodeId, cfg.spaceId);
    ws_audio_init(cfg.wsHost, cfg.wsPort);
    i2s_mic_init();
    vad_init();
    cam_relay_init();

    // -- PIR ISR attachment --
    pinMode(PIN_PIR_INT, INPUT_PULLUP);
    attachInterrupt(digitalPinToInterrupt(PIN_PIR_INT), pir_isr, RISING);
    Serial.printf("[BOOT] PIR ISR attached on GPIO%d\n", PIN_PIR_INT);

    // --- Task Watchdog ---
    esp_task_wdt_init(60, true); // 60s timeout, panic
    Serial.println("[BOOT] Task watchdog initialized: 60s timeout, panic on timeout");

    // -- Create Config Task (Core 0, low priority, 4KB stack) --
    xTaskCreatePinnedToCore(
        config_task,
        "configTask",
        4096,
        nullptr,
        1,          // low priority
        &configTaskHandle,
        0           // Core 0
    );

    // -- Create Work Task (Core 1, high priority, 8KB stack) --
    //    Work task replaces the Arduino loop() — it runs the sensor cycle.
    xTaskCreatePinnedToCore(
        work_task,
        "workTask",
        8192,
        nullptr,
        2,          // high priority
        &workTaskHandle,
        1           // Core 1
    );

    Serial.println("[BOOT] Two-task model active. Deleting Arduino loop task.");
    // Delete the default Arduino loop task — our FreeRTOS tasks take over.
    vTaskDelete(nullptr);
}

// ============================================================================
//  loop — never reached (deleted in setup)
// ============================================================================
void loop() {
    // Unreachable — work_task and config_task run instead.
}

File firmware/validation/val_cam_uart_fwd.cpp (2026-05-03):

/*
 * val_cam_uart_fwd.cpp — P3-CAM-1 (9v3)
 * ESP-CAM: JPEG capture + UART2 chunked forwarding to Node Base.
 *
 * Captures QQVGA q10 JPEG every 3s, chunks over UART2 using
 * the wire contract from CONTRACTS.md:
 *   [0xAA 0x55][frame_id:u16LE][chunk_idx:u8][chunk_total:u8]
 *   [chunk_len:u16LE][data...][crc8]
 *
 * PlatformIO: pio run -e val_cam_uart_fwd -t upload
 * Monitor:    pio device monitor -e val_cam_uart_fwd
 */

#include <Arduino.h>
#include "esp_camera.h"

// --- ESP32-CAM AI-Thinker pin mapping ---
#define PWDN_GPIO_NUM     32
#define RESET_GPIO_NUM    -1
#define XCLK_GPIO_NUM      0
#define SIOD_GPIO_NUM     26
#define SIOC_GPIO_NUM     27
#define Y9_GPIO_NUM       35
#define Y8_GPIO_NUM       34
#define Y7_GPIO_NUM       39
#define Y6_GPIO_NUM       36
#define Y5_GPIO_NUM       21
#define Y4_GPIO_NUM       19
#define Y3_GPIO_NUM       18
#define Y2_GPIO_NUM        5
#define VSYNC_GPIO_NUM    25
#define HREF_GPIO_NUM     23
#define PCLK_GPIO_NUM     22

// --- UART2 to Node Base ---
// GPIO1/3 are shared with UART0 (USB serial) — can't use both simultaneously.
// Use GPIO2 (TX) and GPIO12 (RX) for UART2 instead.
// Wiring: ESP-CAM GPIO2 → Node Base GPIO16 (RX)
//         ESP-CAM GPIO12 ← Node Base GPIO17 (TX)
#define CAM_UART_NUM      2
#define CAM_TX_PIN         2
#define CAM_RX_PIN         12
#define CAM_BAUD           115200

// --- Wire contract constants (CONTRACTS.md / messages.h) ---
#define UART_SYNC_1       0xAA
#define UART_SYNC_2       0x55
#define CRC8_POLY         0x07
#define UART_CHUNK_MAX     200       // max chunk payload bytes
#define FRAME_INTERVAL_MS  3000      // push every 3s
#define FRAME_ID_WRAP      65535     // uint16 wrap

static HardwareSerial CamSerial(CAM_UART_NUM);
static uint16_t frame_id = 0;
static uint32_t frames_sent = 0;
static uint32_t chunks_sent = 0;
static uint32_t frames_failed = 0;

// --- CRC8/ITU (polynomial 0x07, init 0x00, no final XOR) ---
// Computes CRC-8 over data, with optional initial value for chaining.
static uint8_t crc8_update(uint8_t crc, const uint8_t *data, size_t len) {
    for (size_t i = 0; i < len; i++) {
        crc ^= data[i];
        for (int j = 0; j < 8; j++) {
            if (crc & 0x80)
                crc = (crc << 1) ^ CRC8_POLY;
            else
                crc <<= 1;
        }
    }
    return crc;
}

// --- Send one UART chunk ---
// Format: [0xAA 0x55][frame_id:u16LE][chunk_idx:u8][chunk_total:u8]
//         [chunk_len:u16LE][data...][crc8]
static void send_uart_chunk(uint16_t fid, uint8_t chunk_idx, uint8_t chunk_total,
                            const uint8_t *data, uint16_t data_len) {
    uint8_t header[8];
    header[0] = UART_SYNC_1;
    header[1] = UART_SYNC_2;
    header[2] = fid & 0xFF;
    header[3] = (fid >> 8) & 0xFF;
    header[4] = chunk_idx;
    header[5] = chunk_total;
    header[6] = data_len & 0xFF;
    header[7] = (data_len >> 8) & 0xFF;

    // CRC over header + data (all preceding bytes, per CONTRACTS.md)
    uint8_t crc = crc8_update(0x00, header, 8);
    crc = crc8_update(crc, data, data_len);

    CamSerial.write(header, 8);
    CamSerial.write(data, data_len);
    CamSerial.write(crc);

    chunks_sent++;
}

void setup() {
    Serial.begin(115200);
    delay(1000);
    Serial.println("\n=== VAL: CAM UART FWD (9v3) ===");

    // --- UART2 to Node Base ---
    CamSerial.begin(CAM_BAUD, SERIAL_8N1, CAM_RX_PIN, CAM_TX_PIN);
    Serial.printf("[UART2] TX=GPIO%d RX=GPIO%d baud=%u\n", CAM_TX_PIN, CAM_RX_PIN, CAM_BAUD);

    // --- PSRAM check ---
    if (psramFound()) {
        Serial.printf("[PSRAM] Found: %d bytes free\n", ESP.getFreePsram());
    } else {
        Serial.println("[PSRAM] NOT FOUND — JPEG mode requires PSRAM!");
        Serial.println("\n=== VAL FAIL ===");
        return;
    }

    // --- Camera config ---
    camera_config_t config;
    config.ledc_channel = LEDC_CHANNEL_0;
    config.ledc_timer   = LEDC_TIMER_0;
    config.pin_d0       = Y2_GPIO_NUM;
    config.pin_d1       = Y3_GPIO_NUM;
    config.pin_d2       = Y4_GPIO_NUM;
    config.pin_d3       = Y5_GPIO_NUM;
    config.pin_d4       = Y6_GPIO_NUM;
    config.pin_d5       = Y7_GPIO_NUM;
    config.pin_d6       = Y8_GPIO_NUM;
    config.pin_d7       = Y9_GPIO_NUM;
    config.pin_xclk     = XCLK_GPIO_NUM;
    config.pin_pclk     = PCLK_GPIO_NUM;
    config.pin_vsync    = VSYNC_GPIO_NUM;
    config.pin_href     = HREF_GPIO_NUM;
    config.pin_sccb_sda = SIOD_GPIO_NUM;
    config.pin_sccb_scl = SIOC_GPIO_NUM;
    config.pin_pwdn     = PWDN_GPIO_NUM;
    config.pin_reset    = RESET_GPIO_NUM;
    config.xclk_freq_hz = 20000000;
    config.pixel_format  = PIXFORMAT_JPEG;
    config.frame_size    = FRAMESIZE_QQVGA;   // 160x120
    config.jpeg_quality  = 10;
    config.fb_location   = CAMERA_FB_IN_PSRAM;
    config.fb_count      = 2;

    esp_err_t err = esp_camera_init(&config);
    if (err != ESP_OK) {
        Serial.printf("[CAM] Init FAILED: 0x%x\n", err);
        Serial.println("\n=== VAL FAIL ===");
        return;
    }
    Serial.println("[CAM] Init OK — OV2640 ready");

    // --- Sensor info ---
    sensor_t *s = esp_camera_sensor_get();
    Serial.printf("[CAM] Sensor PID: 0x%x\n", s->id.PID);

    // --- Warm-up: discard 3 frames for auto-exposure ---
    Serial.println("[CAM] Warm-up: discarding 3 frames...");
    for (int i = 0; i < 3; i++) {
        camera_fb_t *fb = esp_camera_fb_get();
        if (fb) esp_camera_fb_return(fb);
        delay(200);
    }

    Serial.println("\n[LOOP] Capturing + sending every 3s over UART2");
    Serial.println("[LOOP] Connect Node Base RX=GPIO16 to see reassembled frames");
    Serial.println("=== VAL READY ===\n");
}
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

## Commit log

2026-04-12 feat(phase-02-plan-02-01): add pipeline engine with Transform Stream architecture
    - Created Pipeline.ts with VAD-gated audio processing
    - Added buffer guards to prevent OOM (2MB limit, 45s timeout)
    - Added config/default.json with all pipeline settings
    - Audio flows: WebSocket → Buffer → STT → LLM → TTS → WebSocket
2026-04-19 docs(05): create phase plan for doc architecture refactor
    3 plans across 3 waves:
    - 05-01 (Wave 1): VISION.md, NON_GOALS.md, HARDWARE.md, README.md
    - 05-02 (Wave 2): CONTRACTS.md, PACKS.md, SPACES.md, INTEGRATIONS/*.md
    - 05-03 (Wave 3): ROADMAP.md, PROJECT.md, REQUIREMENTS.md, NOTES.md,
    xentient.md, SUPERSEDED.md, STATE.md
    ROADMAP.md updated with two-track structure (Demo + Platform P1-P8).
    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
2026-04-19 docs(05-01): create NON_GOALS.md, HARDWARE.md, rewrite README.md
    - NON_GOALS.md: explicit exclusions for v1 demo, Platform Track, and out-of-scope
    - HARDWARE.md: B1-B7 decisions verbatim from NOTES.md, BOM, enclosure specs, audio format
    - README.md: rewritten as 60-second bridge-model pitch, remove all stale n8n/visual language
    - Archon contradiction resolved: P9 in VISION.md, excluded from demo in NON_GOALS.md
2026-04-19 docs(05-01): complete foundation documents plan
    - SUMMARY.md created with execution metrics and verification
    - STATE.md updated: plan 01 complete, decisions recorded
    - ROADMAP.md updated: P1-P9 Platform Track, plan 01 marked complete
    - REQUIREMENTS.md updated: DOC-01/02/03/06/07 marked complete
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2026-04-19 docs(vision): reframe web as separate Laravel app + lock demo cut\n\n- VISION.md: Tier 2 reframed (Core and Web are separate processes, not Face A/B). Add Event Pipeline (trigger-agnostic + composabl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
2026-04-19 feat(quick-260420-mqtt): add messages.h, mqtt_client, bme_reader modules
    - messages.h: protocol constants (MSG_VERSION, topic strings, MQTT_RETRY_MAX, payload cap)
    - mqtt_client.h/cpp: PubSubClient wrapper with auto-reconnect (3 retries, 1s/2s/4s backoff, 10s reset)
    - bme_reader.h/cpp: Adafruit_BME280 wrapper, reads temp/humidity/pressure, NaN guard
    - platformio.ini: add PubSubClient, ArduinoJson v7, Adafruit BME280 + Unified Sensor deps; shared/ include path
    [bme_reader.cpp, mqtt_client.cpp]
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2026-04-19 feat(1xi): validate I2S mic + fix deprecation warning
    - I2C scanner: LCD 0x27 + BME280 0x76 confirmed
    - INMP441 mic: left channel (L/R=GND), >>16 shift, peak ~2200 loud
    - VAD thresholds 1000/600 confirmed appropriate for speech detection
    - i2s_read.cpp: upgraded to stereo diagnostic (RIGHT_LEFT mode)
    - WIRING.md: validated I2C + I2S pins, added calibration data
    - platformio.ini: src_filter → build_src_filter (deprecation fix)
    [i2s_read.cpp]
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2026-04-21 fix(p3-cam): correct camera smoke test - add Arduino.h include + fix PSRAM enum\n\nTwo fixes for val_cam_capture.cpp:\n- Add #include <Arduino.h> for proper ESP32-Arduino framework compatibility\n- C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
    [val_cam_capture.cpp]
2026-04-21 fix(p3-cam): remap UART2 to GPIO2/12 â GPIO1/3 conflict with USB serial\n\nESP32-CAM GPIO1/3 are shared with UART0 (USB serial). Sending binary\nUART2 chunks on GPIO1 corrupted the debug output. Re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
    [val_cam_uart_fwd.cpp]
2026-04-22 fix(cam+latency): broken-JPEG false-Live badge, rename latency to frame-info, document llmTotalMs scope
    - camera.html: move goOnline() into img.onload so corrupt JPEG blobs no longer show false Live status; add onerror to revoke blob URL
    - camera.html: rename latency badge to frame-info (shows frame size/ID, not delivery latency)
    - Pipeline.ts: document that llmTotalMs includes pipelined TTS time, not LLM-only
2026-04-24 feat(3d): add V3 socket pocket negative and sleeve modules
    [v3.scad]
2026-04-24 feat(3d): add V3 Zone B (M3 board standoffs) and Zone C (ESP32 standoffs)
    [v3.scad]
2026-04-24 feat(3d): add V3 ventilation gills and rear anchor
    [v3.scad]
2026-04-25 fix(mqtt): remove dead xentient/sensors/vad subscription\n\nNo firmware publishes to xentient/sensors/vad. Remove the dead MQTT\nsubscription, the VADEvent interface, the handleMessage branch, and\nt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
2026-04-25 fix(3d): V3 audit - subtractive rails, pit dimples, board chamfer, Path B cleanup\n\nFlag 1 (Rib Antennas): Remove additive taper ribs from union(). Add\nsubtractive rail slots inside difference() - 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
    [v3.scad]
2026-04-25 feat(3d): add NodeBase spec, peripheral caps, anchor adapters, restore shell features\n\nNodeBase V3.1 (v3.scad):\n- Restore rail slots (6x hex vertices, Z=3-12, 3.5x2mm)\n- Restore alignment keyways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
    [anchor_desk_pedestal.scad, anchor_wall_plate.scad, housing_climate.scad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]
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2026-04-25 feat(harness): Phase 3 HealthMonitor + brain status SSE + onToolCall activity tracking\n\n- Create HealthMonitor.ts: implicit heartbeat via MCP tool calls, warning at 60s, disconnect at 120s, reconne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
2026-04-25 refactor(3d): pivot from OpenSCAD to SketchUp, rewrite framework and add 10 tutorials\n\nRepurpose Framework-for-designing.md as a SketchUp design guide. Archive old SCAD spec docs to _archive/scad/s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
    [anchor_desk_pedestal.scad, anchor_wall_plate.scad, housing_climate.scad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]
2026-04-28 feat(harness): implement Phase 7 gap fixes G1-G5\n\nG1: Wire mode trigger evaluation - handleEvent matches mode triggers with wildcard support\nG2: Composite trigger evaluation with AND logic and dep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
2026-04-28 feat(harness): implement SkillPersistence - brain skills survive restarts\n\n- New SkillPersistence module reads/writes var/skills.json\n- Only source:brain skills are persisted (builtins/packs from 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
2026-04-28 test(harness): add comprehensive tests for Phase 7 gap fixes\n\n- SkillExecutor.gaps.test.ts: G1-G5 (mode triggers, composite, modeFilter, _idle-sleep removal, DataCollector)\n- EventBridge.test.ts: 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
2026-04-28 fix(harness): Phase 7 post-implementation remediation (07-06)\n\n9 atomic fixes from deep architecture review:\n\nO2/O1/A: Move updateSpaceMode listener before EventBridge in core.ts boot sequence; d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
2026-04-28 docs(08): harden Phase 8 plans with expansion points and design system
    Deep hardening of all 8 Phase 8 plans + context file with 30+ expansion
    points integrated at implementation-level detail:
    Cross-cutting:
    - xai-DESIGN.md design system directive added to all 4 frontend plans
    (tokens: #1f2228, #0a0a0a, #2563eb, universalSans, GeistMono)
    - ES module architecture replaces single dashboard.js (8 JS files)
    - Resolved blockers: SkillLog exists, listSkills exists, EventBridge
    events exist, broadcastSkillEvent already public
    08-07 (ControlServer): .bind(this) handler binding, static file
    fallthrough ordering, 64KB body size limit, sensorHistory dep
    08-01 (REST API): /api/skill-log route (re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
2026-04-28 feat(08-07): refactor ControlServer with MicroRouter, ControlServerDeps, and body size limit
    - Replace if/else routing chain with MicroRouter route table
    - Introduce ControlServerDeps interface (DI pattern matching McpToolDeps)
    - Add SensorHistory interface for future ring buffer injection
    - Implement request resolution order: CORS → SSE → API routes → static files → 404
    - Add 64KB max body size limit (413 on overflow)
    - Change static file serving: index.html for root, non-API paths fall through
    - Add .woff2/.woff/.ttf MIME types for self-hosted fonts
    - Separate handleRequest into named handler methods with .bind(this)
    - Distinguish 404 vs 405 (path matched but method didn't)
2026-04-28 feat(08-07): wire ControlServerDeps in core.ts, add SensorHistory ring buffer
    - core.ts: Replace positional ControlServer args with ControlServerDeps object
    (mqtt, modeManager, cameraServer, sensorCache, sensorHistory, spaceManager,
    eventBridge, packLoader, skillLog, getBrainConnected)
    - core.ts: Wire MQTT sensor events to SensorHistory.push() for ring buffer
    - core.ts: Import PERIPHERAL_IDS for BME280 sensor identification
    - ControlServer.ts: Use SensorHistoryLike structural type (decoupled from class)
    - index.ts: Update to use ControlServerDeps with stubs for missing subsystems
    - SensorHistory.ts: New ring buffer class (300 readings, 5min at 1Hz) — stub
    implementation, full feature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
2026-04-28 test(08-07): update ControlServer REST tests for ControlServerDeps
    - Replace positional constructor args with ControlServerDeps object
    - Add stub mocks for new deps (spaceManager, eventBridge, packLoader, skillLog)
    - Add SensorHistoryLike stub (empty query)
    - Add 7 new test cases: 404, 405, CORS preflight, POST text, POST mode,
    POST trigger valid/invalid, GET status
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2026-04-28 docs(08-07): complete ControlServer refactoring plan summary
    - SUMMARY.md with 4 tasks, 5 commits, 7 files, 114/114 tests
    - STATE.md updated: plan 08-07 complete, progress 8/20 (40%)
    - Added SensorHistoryLike structural type decision
    - Added 4 auto-fixed deviations documented
    - Self-check: PASSED
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2026-04-28 feat(08-04): Skill Manager panel with CRUD, drawer, forms, packs, mappings
    - SkillManagerPanel class with sortable table (8 columns: ID, Name, Trigger, Priority, Source, Enabled, FireCount, LastFired)
    - Detail drawer: slide-in from right with animation, closes on Escape/overlay/close button
    - Register form: Simple mode with dynamic trigger fields per type, Advanced mode with JSON textarea
    - Form validation: inline errors with red borders, per-trigger-type field requirements
    - 409 collision handling on register, 403 protection on pack/builtin delete
    - Toggle enable/disable per skill, inline delete confirmation (3s timeout)
    - Live flash accent on skill_fired SSE events
    - Pack section: active p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
2026-04-28 feat(08-05): implement Live Telemetry panel with sparklines, timelines, event feeds
    - telemetry.js: full TelemetryPanel replacing placeholder with Sparkline
    class (canvas retina DPI, flat-line centering, resize debouncing),
    motion timeline (30min dot rendering), mode timeline (color-coded
    blocks per interval), skill fire log (reverse-chronological, batched
    DOM updates via requestAnimationFrame), escalation feed (color-coded
    cards with collapsible context JSON), conflict log (skills vs winner)
    - api.js: add getMotionHistory(minutes) and getModeHistory(minutes)
    - main.js: wire telemetry SSE handlers (sensor_update, skill_fired,
    skill_escalated, skill_conflict, mode_change), re-seed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
2026-04-28 test(08-08): add web console integration tests (42 tests)
    - REST API tests: Skills CRUD (6), Skill Log (2), Packs (3), Spaces (2),
    Event Mappings (5), Sensor History (1), Motion History (1), Mode History (1),
    Config (1), Route guards (404, 405, 400, 413, CORS, static files)
    - SSE broadcast tests: direct broadcastSSE, MQTT modeStatus wiring
    - Fix ControlServer: return 400 for invalid JSON body (was 500)
    - Fix ControlServer: return 413 for oversized body without killing connection
    (was req.destroy() which caused socket errors before response could be sent)
    - Install eventsource as dev dependency for SSE testing
2026-04-28 docs(08-08): complete Integration Testing + Polish plan summary
    - 42 integration tests (REST API, SSE, error cases, CORS, static files)
    - Fixed ControlServer: 400 for invalid JSON (was 500), 413 for oversized body (was socket error)
    - Toast, keyboard nav, responsive polish, SVG favicon
    - Phase 8 plan 08/08 complete
2026-04-28 docs(08): mark Phase 8 complete — all 8 plans shipped
    Phase 8 (Web Console + Dashboard) is complete:
    - 08-07: MicroRouter + ControlServerDeps DI
    - 08-01: 16 REST endpoints
    - 08-02: 10 SSE event types + throttled sensor broadcast
    - 08-03: SPA shell + Overview panel
    - 08-04: Skill Manager panel (CRUD, drawer, packs, mappings)
    - 08-05: Telemetry panel (sparklines, ring buffers, event feeds)
    - 08-06: Mode & Space panel (SVG state machine, mode selector)
    - 08-08: 42 integration tests + polish (toast, keyboard, responsive, favicon)
    203 tests passing, 0 TypeScript errors.
2026-04-29 feat(harness): add port auto-fallback for all servers
    If a configured port (8080, 8081, 3000) is already in use, servers
    now automatically try port+1, port+2, etc. (up to 5 attempts) instead
    of crashing with EADDRINUSE. Logs the fallback clearly so the user
    knows the actual port.
    - New `port-fallback.ts` shared utility with `listenWithFallback()`
    - AudioServer & CameraServer: deferred WS binding via async `start()`
    - ControlServer: uses `listenWithFallback` in `start()`, exposes `actualPort`
    - core.ts & index.ts: await server starts, log actual ports
2026-04-29 fix(harness): add actions UI to Simple skill form + fix trigger field names
    - Add ACTION_FIELDS constant with dynamic fields for all 6 CoreAction types
    (log, set_mode, play_chime, set_lcd, mqtt_publish, increment_counter)
    - Add action rows to Simple form with add/remove, type selector, dynamic
    fields per action type
    - Fix TRIGGER_FIELDS key names to match TypeScript types:
    eventName→event, intervalMs→everyMs, sensorKey→sensor,
    fromMode→from, toMode→to
    - Add select-mode-wildcard type for mode triggers (supports '*' wildcard)
    - Update Advanced form JSON template to include actions example
    - Update handleSimpleFormSubmit to collect and submit actions
    - Update validateSkillForm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
2026-04-29 docs: add doc alignment design spec with L0 Node Skills + Brain Interface
    Incorporates audit feedback:
    - Ground truth anchor: code > docs when they conflict
    - Pipeline.ts debt: migration-safe language, cutover point defined
    - Brain Relay Events section in CONTRACTS.md spec
    - Node Skill failure handling (hardware mismatch, offline, ack error, pairing violation)
    - Phases 9-15 with single "done when" criteria each
    - ROADMAP archive before rewrite
    - CONTEXT.md reading order updated with BRAIN-INTERFACE.md + NODE-SKILLS.md
    - New BRAIN-INTERFACE.md file: three-channel spec for anyone building a Brain
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2026-04-30 feat(harness): add configuration-centric type foundation (Sprint 1 partial)
    - Add Configuration, ConfigTransitions, ConfigTrigger, CoreNodeState, SpaceNode,
    NodeSkill, NodeEventType to types.ts
    - Replace BehavioralMode/SpaceMode with Configuration/CoreNodeState
    - Replace Space.nodeBaseId/activeMode/spaceMode with Space.nodes/activeConfig/availableConfigs
    - Replace CoreSkill.modeFilter with configFilter
    - Add NodeProfile constants, EVENT_MASK_BITS, MIC_MODES, CAMERA_MODES to contracts.ts
    - Add NodeProfileSet/NodeProfileAck Zod schemas and MQTT topics
    - Rename SKILL_EVENTS.MODE_SWITCHED → CONFIG_CHANGED
    - Rename SKILL_TOOLS.SWITCH_MODE → ACTIVATE_CONFIG
    - Update PackSkillManifestSchema w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
2026-04-30 fix(harness): patch 8 critical/high robustness gaps in skill engine
    Task 1: Add get_capabilities gap tests (null-pack, no-config, no-space)
    Task 2: Add node_profile_ack timeout handler (5s ack, offline detection)
    Task 3: Guard EventSubscription flush against removed subscriptions (timer leak)
    Task 4: Add TransitionQueue clear/drain interleaving correctness tests
    Task 5: Add write mutex + atomic rename to PackLoader.persistManifest
    Task 6: Add MQTT reconnect event + node_profile_ack subscription
    Task 7: Add unknown-emit warning log in nodeProfileCompiler + gap tests
    Task 8: Push default profile for unassigned nodes + edge case tests
    Task 9: Wire MQTT reconnect + nodeProfileAck events in core.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
2026-04-30 docs(harness): add 5-responsibility cutover gate to Pipeline.ts deprecation
    Replace the vague @deprecated comment with an explicit list of the five
    responsibilities that brain-basic must cover before Pipeline.ts can be
    deleted: STT with timeout/error handling, LLM routing with context
    injection, TTS with provider fallback, xentient_play_audio result
    validation, and escalation ID correlation across the full chain.
    Sprint 7 of 07-REALIGN-PLAN.
2026-04-30 feat(firmware): implement two-task FreeRTOS model for NodeProfile hot-swap
    Refactor firmware from single loop() into two FreeRTOS tasks:
    - Work Task (Core 1, priority 2): runs activeProfile sensor cycle,
    snapshots profile under critical section, uses event_mask to gate
    sensor reads, registers with ESP32 task watchdog
    - Config Task (Core 0, priority 1): polls profileUpdateFlag every
    500ms, performs guarded memcpy under spinlock, reconfigures sensors,
    sends node_profile_ack
    Key implementation details:
    - MQTT callback parses JSON and validates (not Config Task) per 8.4
    - lastReceivedProfileId captured immediately for ack echo per 8.5
    - WiFi.onEvent triggers mqtt_reconnect on WiFi recon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
    [main.cpp, mqtt_client.cpp]
2026-04-30 fix(firmware): explicit WDT init + reduce critical section in profile hot-swap
    - Add esp_task_wdt_init(5, true) in setup() before task creation to
    explicitly set 5s timeout with panic-on-timeout (was implicit)
    - Add return value check for esp_task_wdt_add() in work_task
    - Refactor handle_profile_set() to snapshot activeProfile in a short
    critical section, build incoming NodeProfile outside the spinlock,
    then only enter critical section for final memcpy + flag set
    [main.cpp, mqtt_client.cpp]
2026-04-30 docs: realign all docs to configuration-centric architecture (Sprint 9)
    Replace activeMode/modeFilter/BehavioralMode/SpaceMode with
    activeConfig/configFilter/Configuration/CoreNodeState across all docs.
    Add NodeProfile compilation, TransitionQueue, ack timeout flows,
    event subscription, config authoring, node_offline notification.
    Add runnable example pack to PACKS.md. Mark all robustness patches
    and G1-G6 gaps as complete in CONTEXT.md.
2026-04-30 fix(firmware): resolve 3 CRITICAL + 4 HIGH issues from Sprint 8 code review
    C1: Move lastReceivedProfileId write inside spinlock to prevent torn-write
    on 32-byte array across cores (mqtt_client.cpp)
    C2: Extract WiFi credentials from messages.h to gitignored secrets.h
    (secrets.h.example provided as template)
    C3: Add range validation for mic_mode (0-2), camera_mode (0-2),
    lcd_face (0-3) — reject out-of-range values, fall back to snapshot
    H1: Make PIR pirTriggered read-and-clear atomic under critical section
    to prevent ISR edge loss between check and assignment
    H2: Remove SYSTEM_EVENT_STA_CONNECTED from wifi_event_cb — only use
    GOT_IP to avoid MQTT reconnect before D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
    [main.cpp, mqtt_client.cpp]
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2026-04-30 fix(firmware): resolve {nodeId} in MQTT topics at runtime — profile hot-swap was broken
    Firmware was subscribing to the literal string "xentient/node/{nodeId}/profile/set"
    instead of resolving {nodeId} to the actual nodeId from NVS. The harness publishes
    to "xentient/node/node-01/profile/set", so they never matched and profile hot-swap
    was completely broken.
    Changes:
    - messages.h: Replace TOPIC_NODE_PROFILE_SET/ACK constants with template strings
    and suffix constants, add buildNodeTopic() declaration
    - topic_builder.cpp: New file implementing buildNodeTopic() using snprintf
    - mqtt_client.cpp: Add runtimeNodeId/resolvedTopicProfileSet/resolvedTopicAck
    statics; mqtt_init() now accepts n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
    [main.cpp, mqtt_client.cpp]
2026-04-30 fix(firmware): harden buildNodeTopic — null safety + truncation detection + empty nodeId fallback
    - Add null checks for nodeId/suffix/buf in buildNodeTopic
    - Add truncation detection with Serial warning
    - Use TOPIC_NODE_PROFILE_SET_BASE constant instead of hardcoded string
    - Add empty nodeId fallback warning in mqtt_init
    [mqtt_client.cpp]
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2026-04-30 fix(firmware): factory reset clears WiFiManager WiFi creds + remove dead NVS WiFi keys (S3, S4)
    - provisioning_clear() now calls WiFi.disconnect(true, true) to erase
    WiFiManager's stored SSID/password from NVS flash, ensuring a full
    factory reset instead of leaving stale WiFi creds behind (S4)
    - Removed NVS_KEY_WIFI_SSID and NVS_KEY_WIFI_PASS constants — WiFiManager
    owns the WiFi lifecycle and uses its own internal NVS namespace (S3)
    - provisioning_has_config() now only checks MQTT host + Node ID (WiFi keys
    no longer in Xentient namespace)
    - provisioning_read_config() no longer reads wifi_ssid/wifi_pass from NVS
    - provisioning_start_portal() JSON and manual-field paths no longer wr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
    [provisioning.cpp]
2026-04-30 fix(firmware): add client-side JSON validation + required-field check in portal (S8)
    - Inject JavaScript via WiFiManager setCustomHeadElement that validates
    JSON in the prov_json field before form submission, alerting the user
    on parse errors instead of silently falling back to manual fields.
    - Add server-side required-field check after successful JSON parse to
    warn if mqttBroker and nodeId are both missing from the payload.
    [provisioning.cpp]
2026-04-30 fix(firmware): portal timeout enters 60s deep sleep instead of restart loop (S7)
    Previously, portal timeout (180s) called ESP.restart() which reboots
    back into the same portal, creating an infinite loop. Now both branches
    (has-config and no-config) enter deep sleep for 60s before retrying,
    with an LCD face showing timeout state.
    [main.cpp]
2026-04-30 fix(firmware): validate config completeness after provisioning (S8)
    Add a runtime check after provisioning_read_config() that verifies
    mqttHost and nodeId are non-empty. If either is missing, clear NVS,
    display an error face on LCD, and enter deep sleep for 10s before
    retrying — preventing the node from attempting MQTT with invalid config.
    [main.cpp]
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2026-04-30 fix(firmware): remove dead wifiSsid/wifiPass from ProvisioningConfig — WiFiManager owns WiFi creds (H5)
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2026-04-30 fix(firmware): HTML-encode portal validation + add NVS field bounds checks + legacy key cleanup (H4, M6)
    [provisioning.cpp]
2026-04-30 fix: add spaceId to birth + exponential backoff + mqtt_subscribe bool return (H2, H3, L4, L6, M4)
    [main.cpp, mqtt_client.cpp]
2026-05-03 chore: stage all uncommitted work + cleanup gitignore
    - Stage firmware .pio build output, validation sketches, planning docs
    - Stage harness changes (MotionHistory, brain-stream test, mode.js, events.ts)
    - Stage 3d/demo, solder board map, product images, Arduino Codes shortcut
    - Remove harness/node_modules/ from git tracking (was accidentally committed)
    - Remove .claude/worktrees/ from tracking (embedded git repos)
    - Remove harness/data/ (Honcho runtime DB) from tracking
    - Update .gitignore: node_modules/, .claude/worktrees/, harness/data/,
    *.db-shm/wal/journal, tsconfig.tsbuildinfo, .claude/settings.local.json
    - Delete stale docs: NON_GOALS.md, VISION.md, WEB_CONTROL.md, repurpose.md,
    s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
    [v2.scad]
2026-05-04 fix(harness): wire EscalationSupervisor + McpSseServer into core.ts, add /mcp SSE route (B1, B2)
    - B1: Add mcpSse to ControlServerDeps and /mcp SSE endpoint bypass
    - B2: Instantiate EscalationSupervisor with chime fallback, create McpSseServer,
    pass mcpSse to ControlServer, update getBrainConnected to check sseBrainTracker
    - B3: _voice-capture already present in BUILTIN_SKILL_IDS (verified)
    Audit reference: tasks/AUDIT-WORKER-B.md gaps B1+B2 (HIGH) and B3 (MEDIUM)
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2026-05-04 chore: stage all Phase 7 work + add .pio/ to gitignore
    - Add firmware/.pio/ to .gitignore (build artifacts were leaking)
    - Remove tracked .pio build artifacts from git
    - Stage all harness dashboard/frontend changes (space, audio, overview)
    - Stage firmware source changes (i2s_mic, main, mqtt_client, provisioning)
    - Stage engine hardening changes (ModeManager, SkillExecutor, SpaceManager)
    - Stage frontend plan updates
    [main.cpp, mqtt_client.cpp, provisioning.cpp]
